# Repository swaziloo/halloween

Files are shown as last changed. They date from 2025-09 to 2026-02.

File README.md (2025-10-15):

# Hallowe'en Projects #

___
## [Animatronic Crow](animatronicCrow/README.md) ##
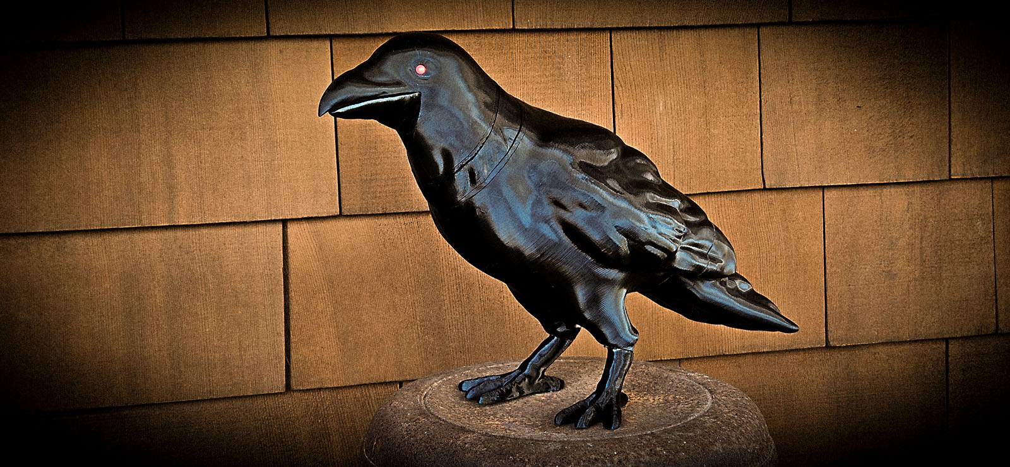
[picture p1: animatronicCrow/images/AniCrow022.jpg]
The Animatronic Crow


A 3D printable crow model that turns its head, blinks LED eyes, moves its beak and squawks when it sees your friends or trick-or-treaters.

___
## [Creature Control PCB](creatureControl/README.md) ##
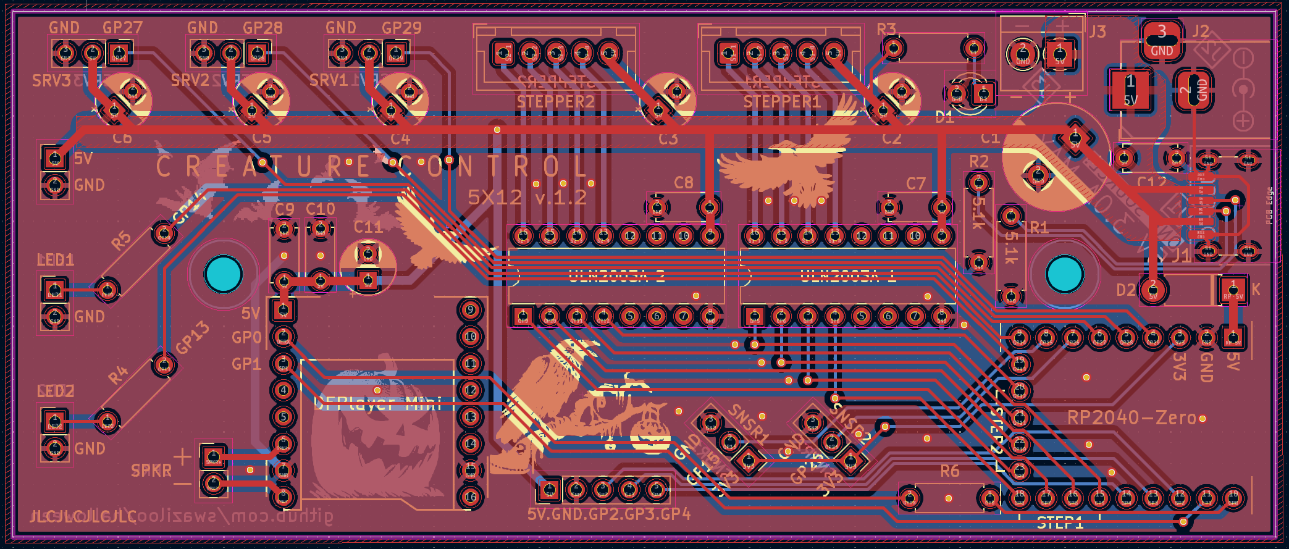
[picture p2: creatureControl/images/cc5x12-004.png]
The Creature Control 5x12 PCB


A PCB to make building animated projects easier to put together.

___
### [Our Hallowe'en Decoration Gallery](https://www.monkeymind.com/halloween) ###

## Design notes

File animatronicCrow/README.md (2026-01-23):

The Animatronic Crow
# Animatronic Crow
Based on  designs from Thingiverse:
[Animatronic Halloween Crow by andymcculloch](https://www.thingiverse.com/thing:6278223)
and [Animatronic Halloween Crow by Doctor_JohnSmith](https://www.thingiverse.com/thing:6258153)
which are themselves remixes from [danman](https://www.thingiverse.com/danman/designs)
who remixed the original model by [YahooJAPAN](https://www.thingiverse.com/yahoojapan/designs).

My work has been done in [KiCad](https://www.kicad.org/),
[FreeCAD](https://www.freecad.org/),
and [Blender](https://www.blender.org/download/releases/4-4/).

I may have extra PCBs available at my cost+shipping. 
Message me if interested.
___
## [Crow Printing Instructions](stl/README.md) ##
Details for printing the models.

## [Crow Build Guide](BUILD.md) ##
How-to guide for building your crow.

### :de: [Crow Guides in German](https://github.com/padpumpkin/animatronicCrow-de) ###
Deutsche Übersetzung der Anleitungen dank padpumpkin.

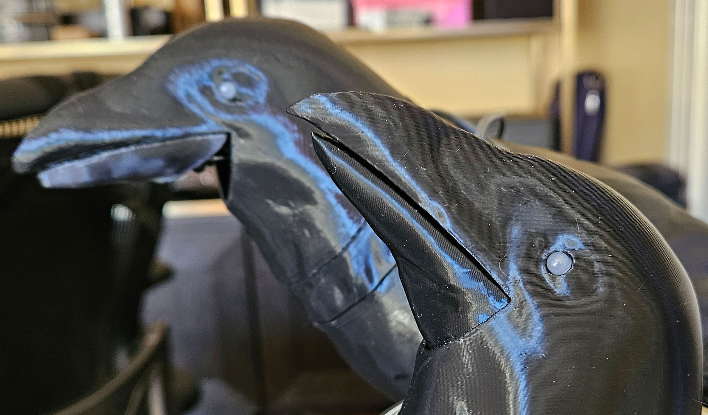
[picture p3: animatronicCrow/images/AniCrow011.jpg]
New beak/head in the foreground.

### Modifications and model sources: ###

| Model | Source | Modifications |
|---|---|---|
| Global | | Standardized on M3 x 4 (or 5) x 5 heat set inserts and M3 fasteners. |
| Head | andymcculloch | Refined beak shape to add more of a point. Smoothed/bevelled lower beak opening. Cut away mounts and rebuilt them slightly wider and short enough to fit below the SG90 servo. |
| Beak | Doctor_Johnsmith | Added a lower collar that fits inside the head without a visible cut-away. Re-drew mounting rail and added separate pin mount holes for actuator. Sliced to enable 3D printing standing up. |
| Beak Servo Mount Plate | andymcculloch | Refined connector tower to accommodate the larger beak when fully open. Straightened out SG-90 mount and shrunk mounting holes to match the screws that come with SG90 servos. Added hexagonal grille for sound. Moved M3 screw holes and shrunk wire pass-thru. |
| Head Stepper Collar | andymcculloch | Moved stepper center. Shrunk cable opening and added alignment pins. Added hexagonal grille for sound with slide path for head pivot pins. Moved M3 screw holes. |
| Body Stepper Mount Plate | Andymcculloch | Moved stepper center. Added arched cutout for alignment pins. Added head pivot pins. Added hexagonal grille for sound. Enlarged head holes to accommodate M3 screws. |
| Body | Doctor_Johnsmith | Cut away servo mount plate and added mounts for andymcculloch stepper mount plate. Added enclosed box for 40mm speaker with flange. Added internal wire management ring. Added access hole behind left leg. Added mount rail for Creature Control 5x12 PCB. Added internal sensor mount. Added PIR window to right knee (optional). Refined 10x3mm magnet mounts. Added mount and M3 hole for securing tail. Added alignment tabs and reversed pins for feet. Filled legs and added drainage routes around/through speaker out out the low point in the right leg. |
| Feet | Doctor_Johnsmith | Reversed pins (socket on feet) and added alignment tabs. Added tie-down horizontal hole through feet. |
| Tail | Doctor_Johnsmith | Refined 10x3mm magnet mounts. Added snap-in tab mount for securing tail to body (optional). Enlarged hole for exterior connection. Made wing tips pointier. |

### Additions: ###

| Model | Description |
|---|---|
| Actuator | Printable arm for connecting hinged beak to servo. Recommend 0.2mm nozzle. |
| Actuator Spacer | Fills the gap between the actuator and the SG90 arm. Recommend a 0.2mm nozzle. |
| PCB Mount | Small rail to mount the Creature Control 5x12 board with M3 hardware to slide inside the body. |
| PIR Mount | Holds a mini PIR sensor and snaps into place inside the right leg. Recommend 0.2mm nozzle. |
| PIR Small Fresnel | PIR window plug and cap are a glue-in holder for a minimal/black fresnel lens to hide the mini-PIR sensor. | 
| PIR Window Plug | Fills a PIR hole in the right knee if you change your mind. Print vertically to match the crow outer pattern. |
| PIR Window Template | A printable oval that matches the hole shape for the PIR window. The intention was to use black IR transmissive acrylic to cover the sensor, but it's too dark for effective sensing. YMMV. |
| LD1020 Mount | Holds an LD1020 radar sensor and snaps into place inside the right leg. Recommend a 0.2mm nozzle. |

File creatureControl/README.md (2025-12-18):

The Creature Control 5x12 PCB
# Creature Control PCB #
When hand soldering a board to enable the animatronic crow I realized that I wanted a half-dozen crows and maybe some talking skulls and hand soldering wasn't my favorite way to spend my time.
Hence Creature Control 5x12. Designed to enable a bunch of capability using an inexpensive and easy to program Raspberry Pi 2040 in the tiny Waveshare Zero format.

*I likely have extra PCBs&mdash;contact me directly if interested in PCB(s) at cost.*

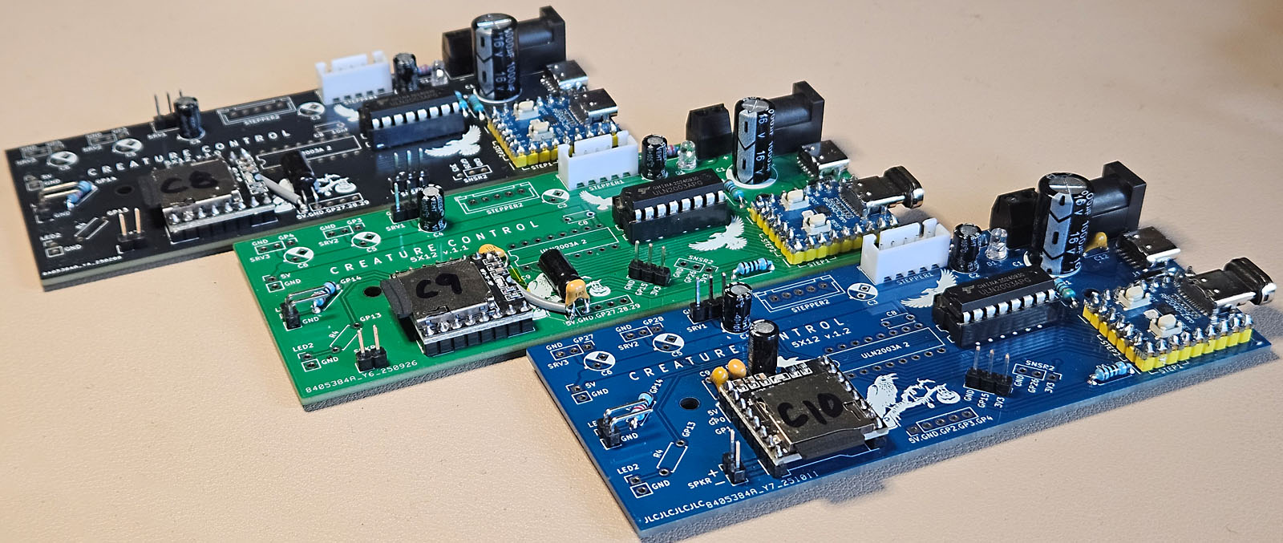
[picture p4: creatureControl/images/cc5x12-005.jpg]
Versions 1.0-1.2 of the CC5x12 PCB

## 5x12 v1.0 ##
Provides a 5-volt 3-amp power rail to supply 3 servos and 2 steppers controlled by a RP2040-Zero which is also wired to incorporate 2 LEDs, 2 motion sensors, the DFPlayer Mini mp3 player and a pin header for the remaining pins.
Designed to be hand-soldered and easily programmable using Arduino libraries.
### v1.1 2025-09 ###
Larger PTH (0.9mm) for MCU and mp3 player mounts, 
add 1KΩ serial resistor for DFPlayer RX (MCU GP0) connection, 
add capacitor (104) for DFPlayer 3V3, 
remove incorrect silk for C7 and C8 value,
rotate sensor mounts for better routing,
update schema.
### v1.2 2025-10 ###
Move DFPlayer Mini to 5V supply and add additional bulk/filtering capacitors (1µF, 220µF),
add filtering capacitor (0.1µF) at 5V power supply,
move servos 1-3 to GP27-GP29,
move GP2-GP4 to expansion header,
rotate DFPlayer Mini,
(re)arrange silks,
update schema.

*Gerber files have been produced for JLCPCB but may work elsewhere.*

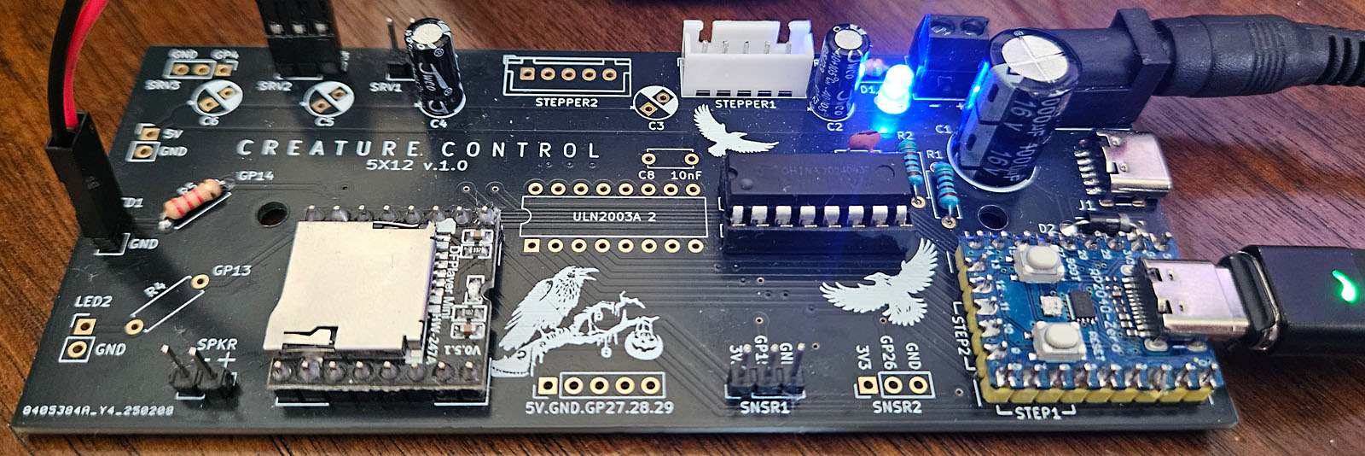
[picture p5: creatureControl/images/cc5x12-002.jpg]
Animatronic Crow build on CC5x12

### VITAL IMPORTANT SAFETY NOTICE! ###
*The 5 volt power rail allows for multiple source connections but only one should be used at any given time.* 
*Do not connect more than one 5 volt source to the power rail!*
(Unless you really know what you're doing.)
It is safe to connect the power to the 5v rail and the RP2040-Zero to your PC at the same time&mdash;in fact it's necessary for testing.
### Parts List ###
The intent is that one would install only the components needed for a project.

| Qty | Ref | Part | Note |
|---|---|---|---|
| 1 | | RP2040-Zero | Waveshare or equivalent. |
| 1 | D2 | 1N5819 Schottky Diode | For RP2040-Zero VCC. |
| 1 | | DFPlayer Mini | DFRobot or equivalent. |
| 3-4 | C7-C9, C12 | 100nF 50v Ceramic Capacitor (104) | (v1.1+) for DFPlayer Mini 5V, (v1.2) input 5V, ULN2003A. |
| 1 | C10 | 1µF 50v Ceramic Capacitor (105) | (v1.2) For DFPlayer Mini midrange filter. |
| 1 | C11 | 220µF 10-16v Electrolytic Capacitor | (v1.2) For DFPlayer Mini . |
| 1 | R6 | 1KΩ Resistor | (v1.1+) for MCU GP0->DFPlayer Mini RX |
| 1-2 | | ULN2003A | Stepper driver. |
| 1-2 (optional) | | IC DIP Socket 16-Pin | For ULN2003A. Or just solder directly to the board. |
| 1-2 | | XH2.54mm 5-Pin Connector | Straight pin for stepper. |
| 1 (optional) | D1 | 3mm LED | For power rail indicator. |
| 1 (optional) | R3 | Resistor for power indicator LED | I used 2.2kΩ for a blue 3mm LED. |
| 1-2 | R4,R5 | Resistor for external LEDs | Based on LED(s) to be used. |
| 1-5 | C2-C6 | 100µF 10-16v Electrolytic Capacitor | One for each 5v servo and stepper. |
| 1 | C1 | 1000µF 10-16v Electrolytic Capacitor | For 5v rail. |
| 1 (optional) | J2 | 5.5x2.1MM DC-005 Power Jack | If using a 5v/3A adapter. |
| 1 (optional) | J1 | USB-C 6-pin Surface Mount | If using a USB battery. |
| 2 (optional) | R1,R2 | 5.1kΩ Resistors | If using a USB battery. |
| 1 (optional) | J3 | KF350-2P 3.5mm Pitch 2Pin PCB Screw Terminal Block Connector | If using a wired 5v source or drain. Also useful if needing to share ground with an external power rail. |
| optional | | 2.54mm Pin Headers | For board connections. |

## Building the CC5x12 ##

* You do not need to fill the board. It is perfectly acceptable to install only the connections and components you intend to use.
* If you are installing the USB-C socket, do that first and test the electrical connections. Every other component is easier to hand solder.
* The RP2040-Zero can be powered by its USB-C connection or the board 5v power, but it will not provide power to the steppers, servos, or DFPlayer (since v1.2). LEDs and sensors draw power from the RP2040-Zero 3V3.
* The C1 capacitor is intended to smooth out the 5v supply for the board. C2-C6 & C11 provide demand power for their nearby stepper, servo, or DFPlayer Mini. Only install these caps for the components you intend to connect.
___

## Testing ##
Install the Arduino IDE and the following libraries:
[AccelStepper](https://www.airspayce.com/mikem/arduino/AccelStepper),
[DFRobotDFPlayerMini](https://github.com/DFRobot/DFRobotDFPlayerMini),
[arduino-pico](https://github.com/earlephilhower/arduino-pico) by Earle Philhower,
[Adafruit NeoPixel](https://github.com/adafruit/Adafruit_NeoPixel).
Install using the library manager in the Arduino IDE.

* Enable the *Waveshare RP2040-Zero* board in the board manager.
* Connect power to one of the 5v inputs and the RP2040-Zero to your pc. 
* Select the connected device/port and ensure the Waveshare RP2040-Zero board is assigned.
* Open the [BoardTest](BoardTest) sketch with the Arduino IDE.
* Set 'true' for available components at the top of the sketch. 
* Select the 'Upload' button.
* The sketch should compile, the board should initialize, and a test loop should run.

The steppers, servos, and MP3 components will cycle.
The LED(s) will reflect the sensor(s) states.

___
## Notes and Issues: ##

### Volume Issues v1.0 and v1.1 ###
The DFPlayer Mini is being powered off the RP2040-Zero 3V3 on these boards which doesn't provide enough power to handle max draw at high volume.
The fix for these boards is to pull the VCC pin from the header and wire to a nearby 5V connection.
Add a 220µF electrolytic and a 1µF (105) ceramic at the power tap and pull a twisted pair of 5V/GND to the DFPlayer, connecting a 0.1µF (104) between ground and VCC at the connection point.
The easier fix is to lower the volume to one that the MCU will support. 
Around 22-25/30.
TX/RX are already shifted to 3.3V for compatibility with MCU communication.

### Connecting to a 12v Rail ###
You should be able to control 12v steppers and servos using the CC5X12 by eliminating the 5v connection to them and providing separate power. 
If you do this, you will want to pull a shared ground over from the block connector or another board source.
*I have not tested this functionality.*

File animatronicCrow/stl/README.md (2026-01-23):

# 3D Printing #
:de: [Crow Guides in German](https://github.com/padpumpkin/animatronicCrow-de)

Print in the orientation shown in the images below. 
Consider PETG for a more weather resistant material, but note that the model is not fully weatherproof.

## Note: ##
The crow body is designed to be printed with minimal supports (only for the "ankles").
If your slicer wants to generate an enormous support to catch the tiny top of the PCB mount you should mark it "do not support" and save some filament.

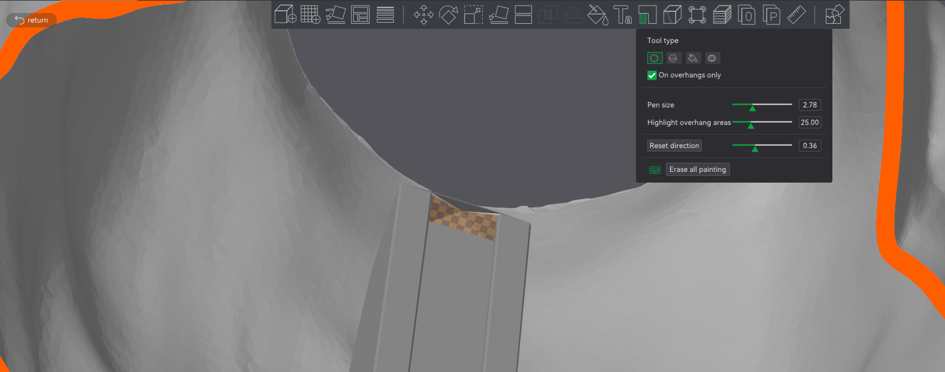
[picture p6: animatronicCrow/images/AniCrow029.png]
No need for printed support here


On a related note, I do prefer to support the sloping underside of the beak. 
The [.3mf](https://makerworld.com/en/models/1869791-animatronic-halloween-crow) includes these settings.

## Second Note: ##
The stepper collar slides against the stepper plate.
I print the collar with ironing on to help smooth the surface.
After printing, I sand both the dome mounts on the body plate and the sliding surface on the collar to 800 grit.
Add dry lube to both before assembly.

# Printing #
I find that PETG printed with a 0.4mm nozzle and 0.16mm layer height provides a strong build and a shiny appearance like bird feathers at the expense of a long print.

| | |
|---|---|
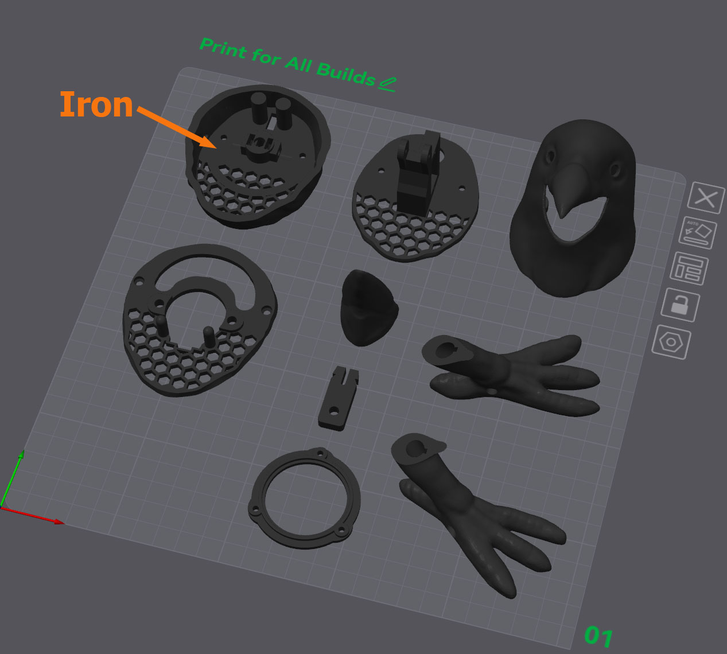
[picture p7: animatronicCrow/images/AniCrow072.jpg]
PIR Crow STL Files for 3D printing
|  | Print all parts on the first plate for all builds. Turn on ironing for the top of the collar. Consider the seam on the lower portion of the head (I like to align it right down the middle). The speaker ring and tail screw tab are optional, though I recommend both. |
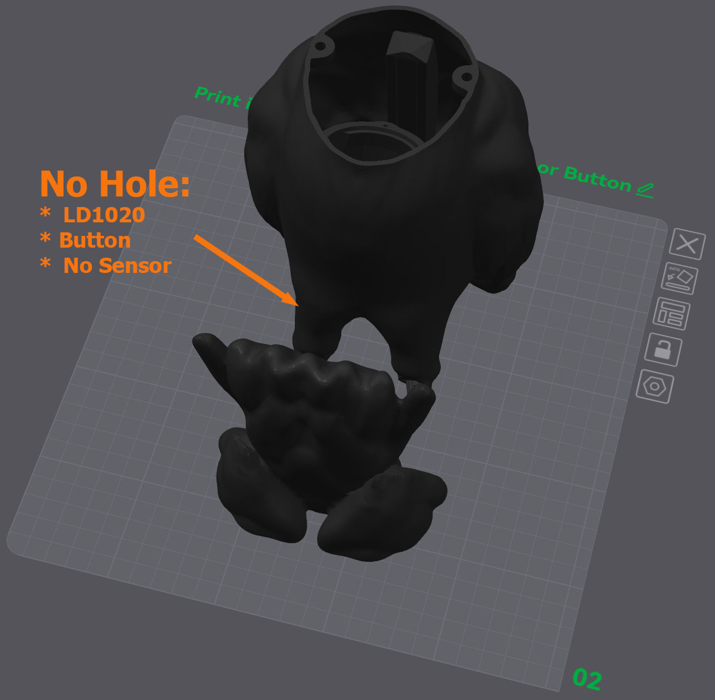
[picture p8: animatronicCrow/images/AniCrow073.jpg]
PIR Crow STL Files for 3D printing
|  | The crow body with no hole is used for non-PIR builds. |
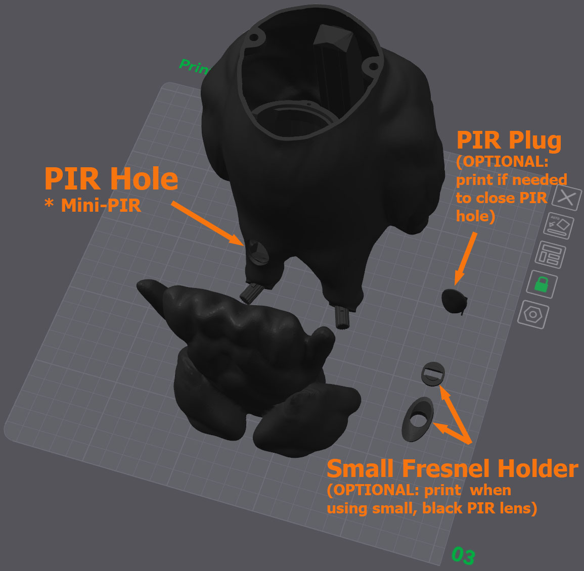
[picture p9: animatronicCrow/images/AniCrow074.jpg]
PIR Crow STL Files for 3D printing
|  | The body with the PIR hole can be used for a regular, white-lens Mini-PIR or with a replacement small black lens. You need the Small Fresnel Holder *or* the Mini-PIR Holder&mdash;not both. The PIR Plug can be used to close the PIR Hole if you decide to use another/no sensor. |
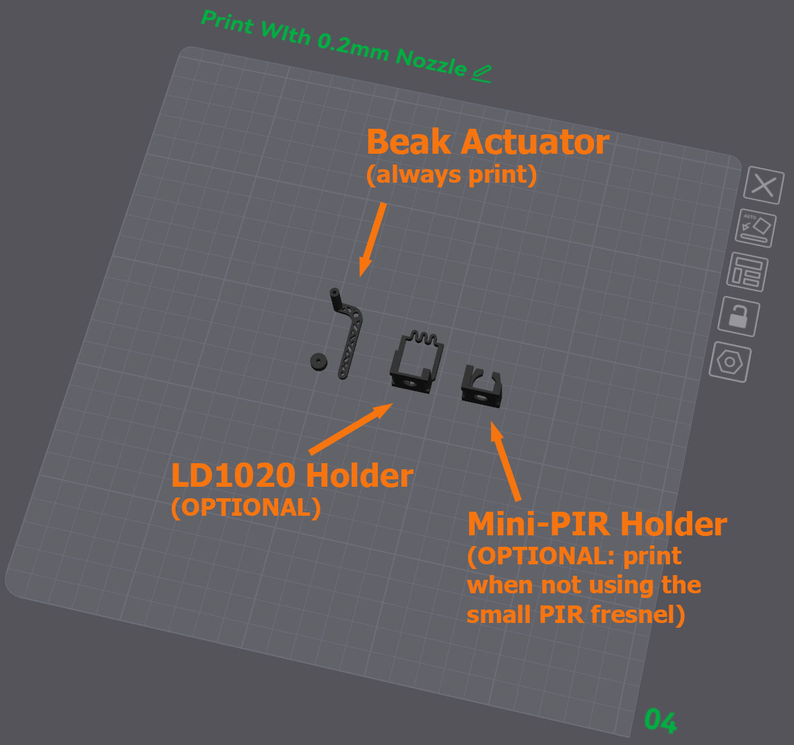
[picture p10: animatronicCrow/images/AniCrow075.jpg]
PIR Crow STL Files for 3D printing
|  | The actuator, spacer, and sensor holders are best printed with a 0.2mm nozzle and a "strength" setting (I prefer 0.10mm layer height). |

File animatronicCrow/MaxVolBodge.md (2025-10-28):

### Bodge for Max Volume PCB 1.0 & 1.1 ###
(You don't need to do any of this on v1.2+ boards)

:de: [Crow Guides in German](https://github.com/padpumpkin/animatronicCrow-de)

| Step | Simple Bodge v1.0 or v1.1 | This is my go-to for both v1.0 and v1.1 since I don't hear any noise or buzzing through the tiny 3-watt speaker without the ceramic caps. |
|---|---|---|
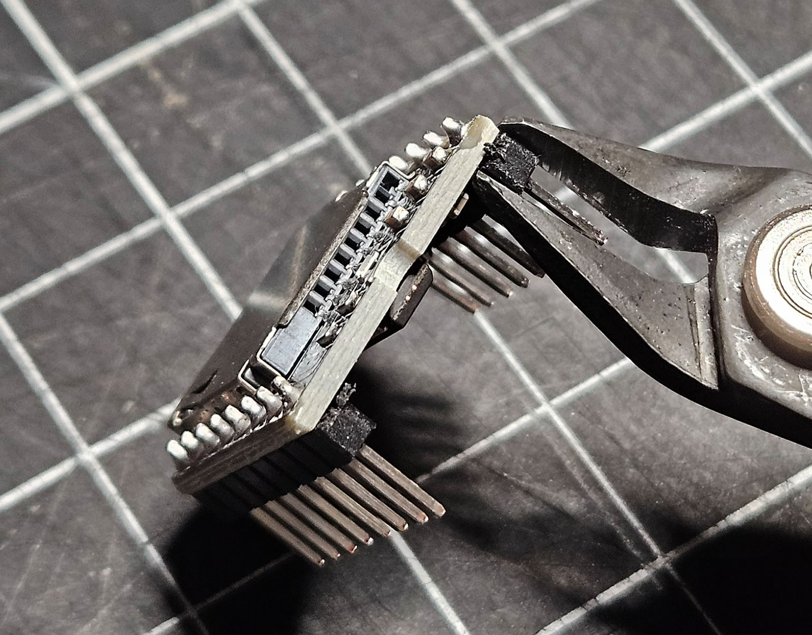
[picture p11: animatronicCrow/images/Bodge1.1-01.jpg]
| 1 |   | Carefully clip the plastic above the VCC pin on the DFPlayer Mini. |
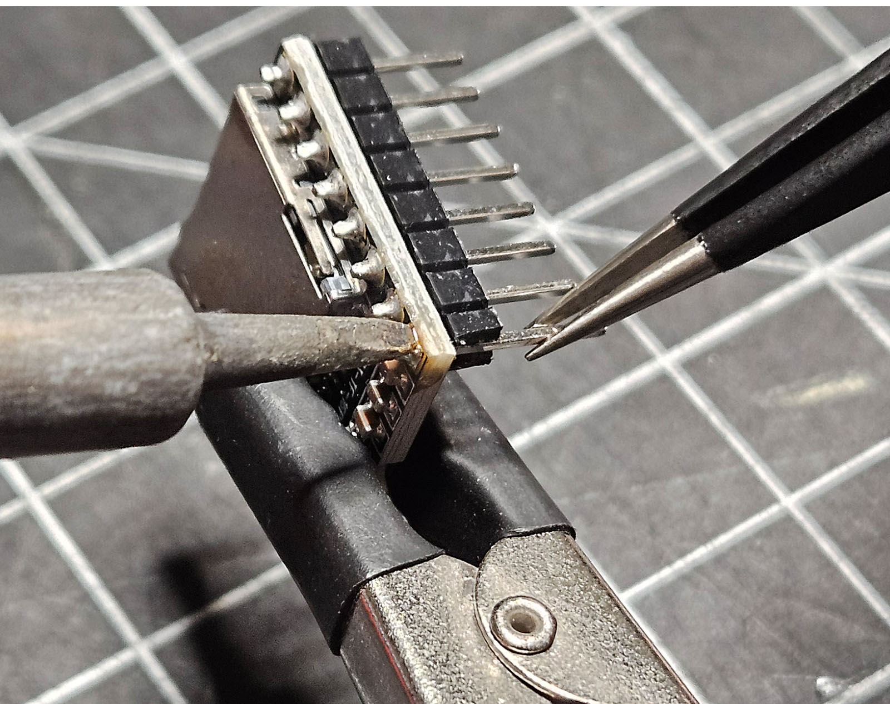
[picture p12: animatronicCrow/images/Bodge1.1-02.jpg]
| 2 |   | Any soldering on the DFPlayer Mini runs a risk of disrupting the tiny SMD caps and resistors. Keep away from them and heat the pin until you can pull it out of the board and header. Clip away the rest of the plastic below VCC. |
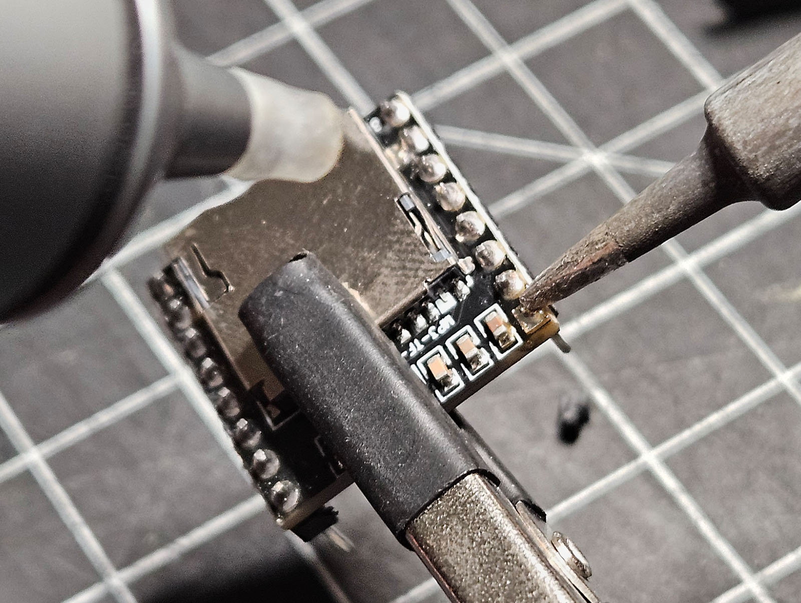
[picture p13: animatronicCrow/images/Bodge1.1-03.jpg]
| 3 |   | Clean up the through hole with a solder sucker (or tape, but...risky). |
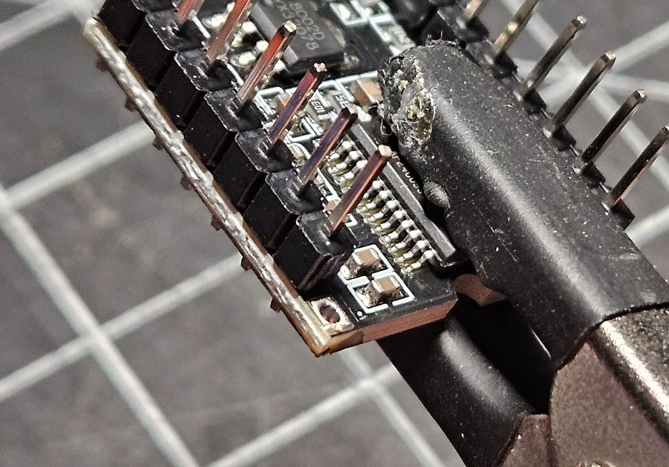
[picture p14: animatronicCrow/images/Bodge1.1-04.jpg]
| 4 |   | When you're done, ensure you didn't move or detatch any SMD components on the top or bottom of the board. The through hole should be clear. |
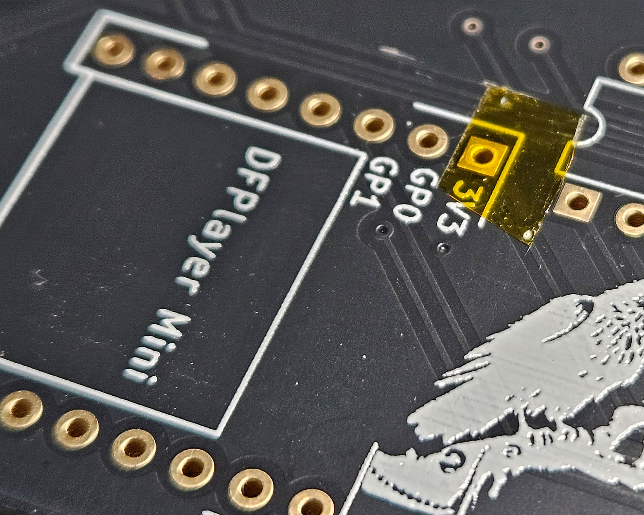
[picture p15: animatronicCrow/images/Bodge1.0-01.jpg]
| 5 |   | Cover the 3V3 through-hole pad with a bit of Kapton or electrical tape. |
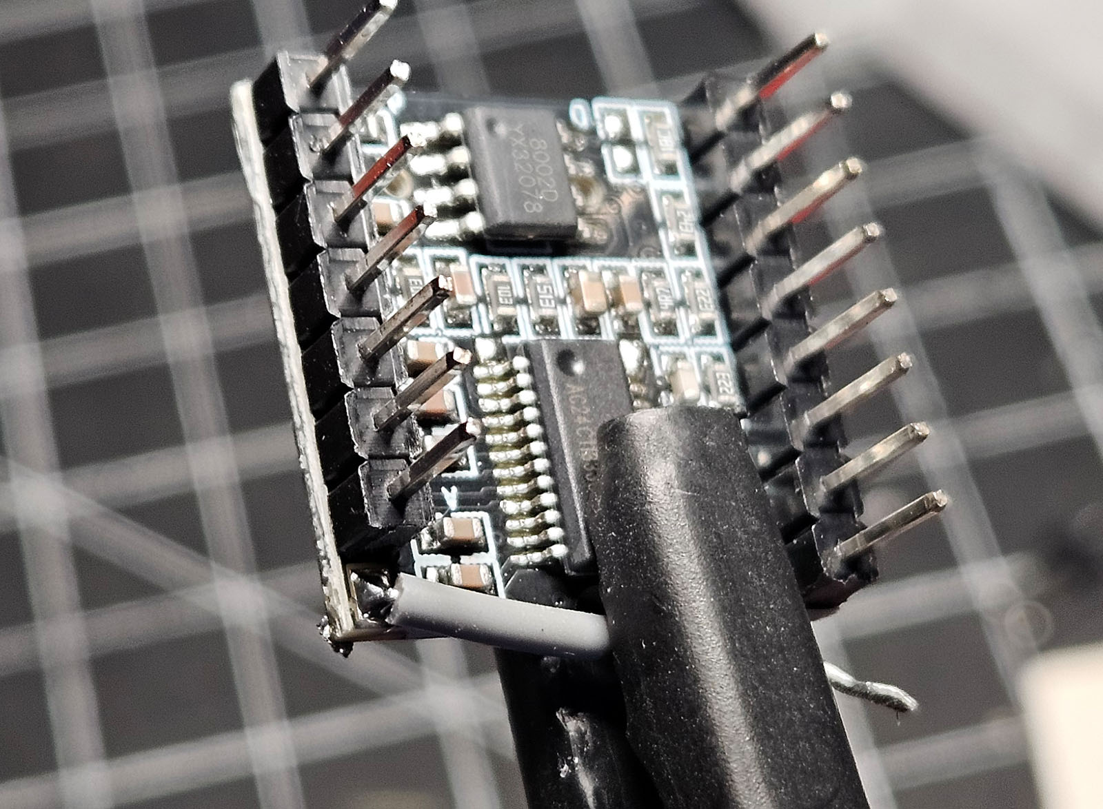
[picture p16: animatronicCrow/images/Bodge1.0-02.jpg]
| 6 |   | Strip the ends off a ~25mm length of high-temperature wire. Twist and solder one end through the DFPlayer Mini from below. Solder the DFPlayer Mini to the CC5x12 board. |
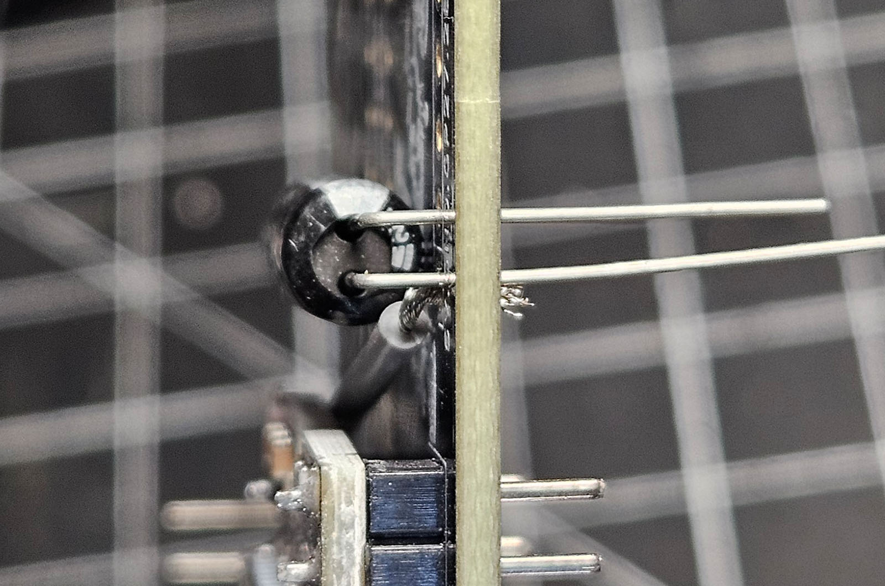
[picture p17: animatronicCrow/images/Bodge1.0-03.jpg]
| 7 |   | Bend the other end of the wire through the 5V expansion header hole. Fit a 220uF electrolytic capacitor through the same 5V and adjacent GND holes. Solder in place. |
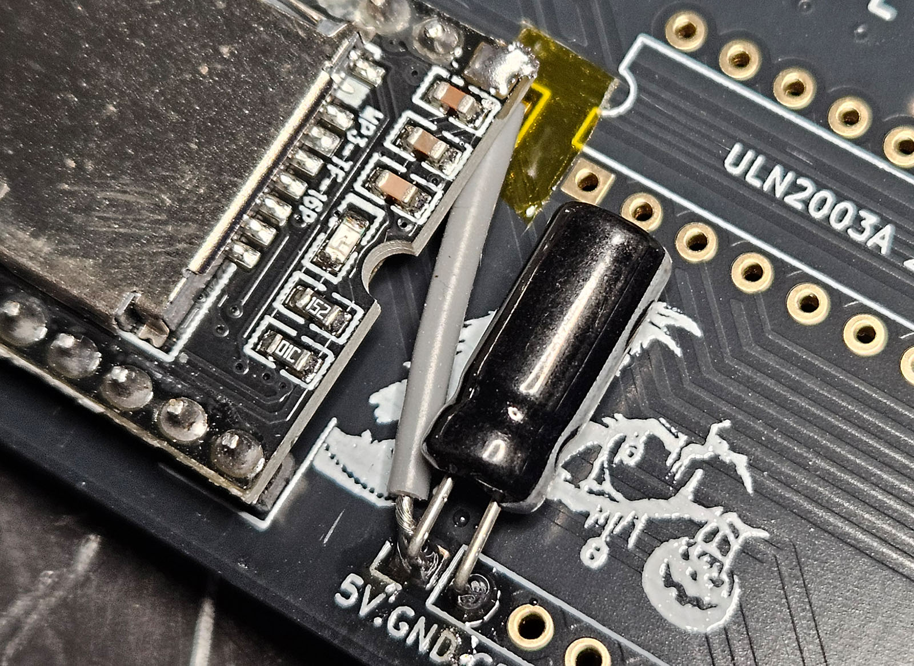
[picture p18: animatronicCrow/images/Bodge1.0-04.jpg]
| 8 |   | The completed bodge will support max volume (30) from the internal 3W amplifier of the DFPlayer Mini. |

| Step | Bodge v1.1 with Ceramic Caps | Ceramic capacitors will reduce board noise. |
|---|---|---|
| 1-4  | Same as above. | |
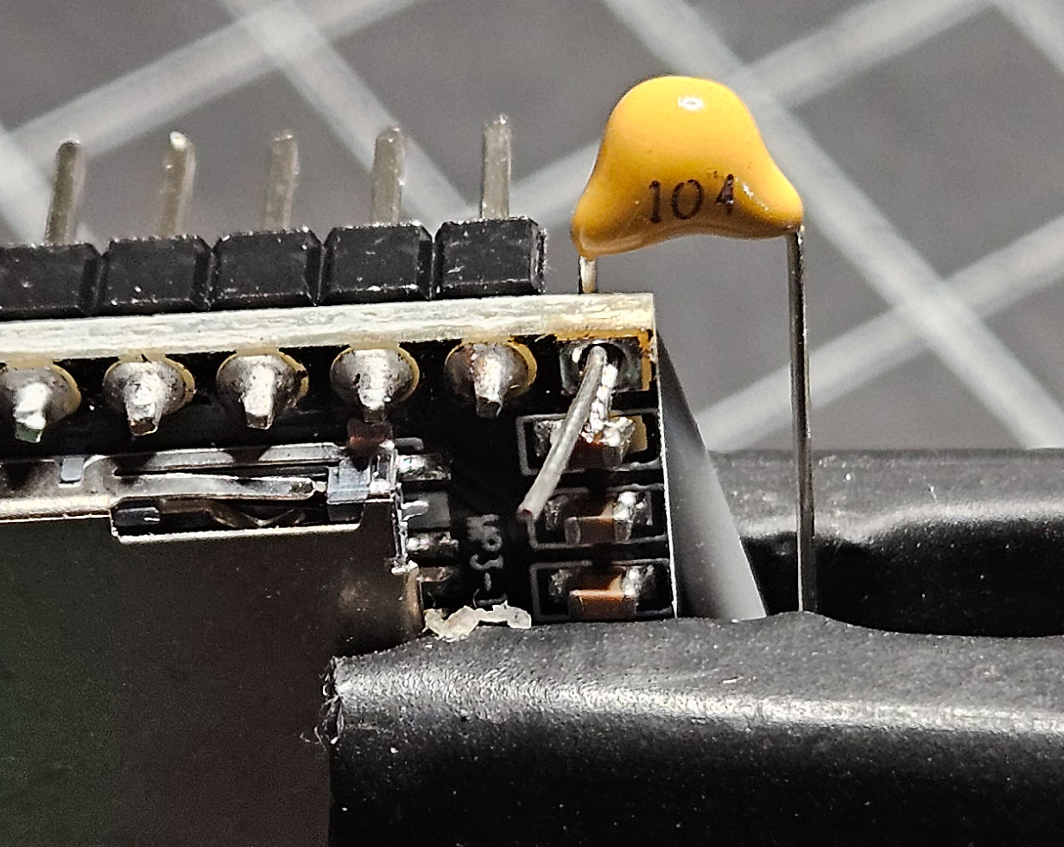
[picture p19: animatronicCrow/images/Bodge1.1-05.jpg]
| 5 |   | Fit a short piece of high temp wire and one leg from your 104 resistor from the bottom and solder those in place. |
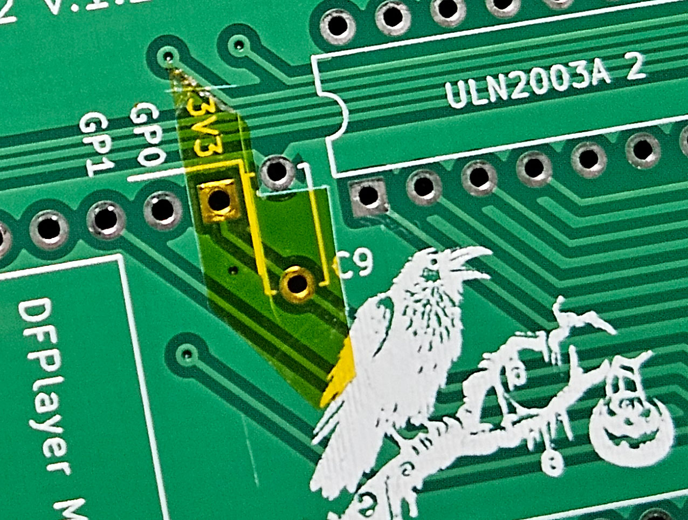
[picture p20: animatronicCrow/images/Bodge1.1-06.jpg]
| 6 |   | Add some Kapton (or electrical) tape to cover the 3v3 through hole pads. |
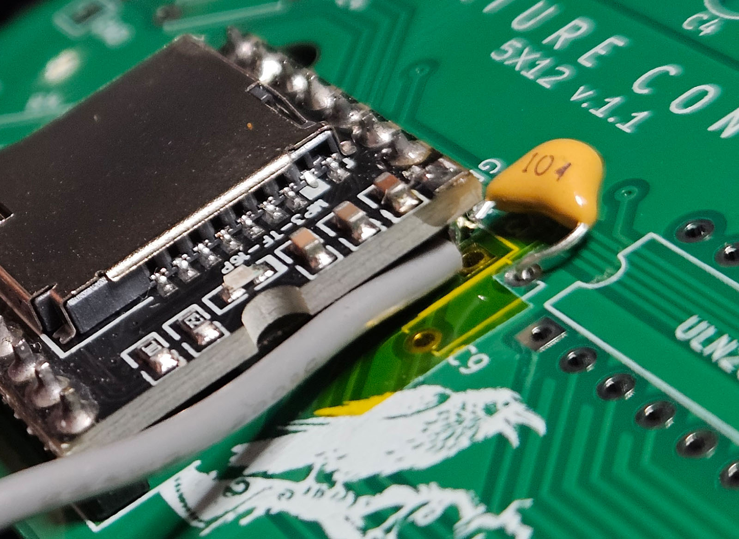
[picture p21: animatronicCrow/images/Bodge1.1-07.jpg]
| 7 |   | Mount the DFPlayer mini carefully fitting the other leg of the 104 cap into the ground. Solder both. |
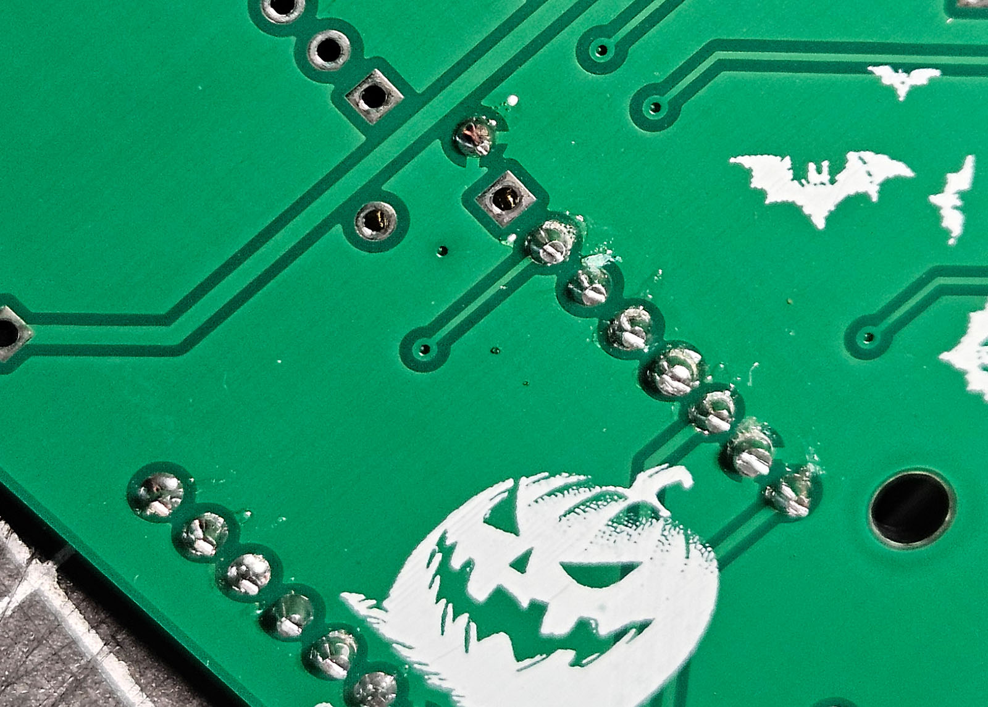
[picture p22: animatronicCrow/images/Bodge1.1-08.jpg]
| 8 |   | After soldering and clipping the legs you should have nothing in either 3v3 through holes. |
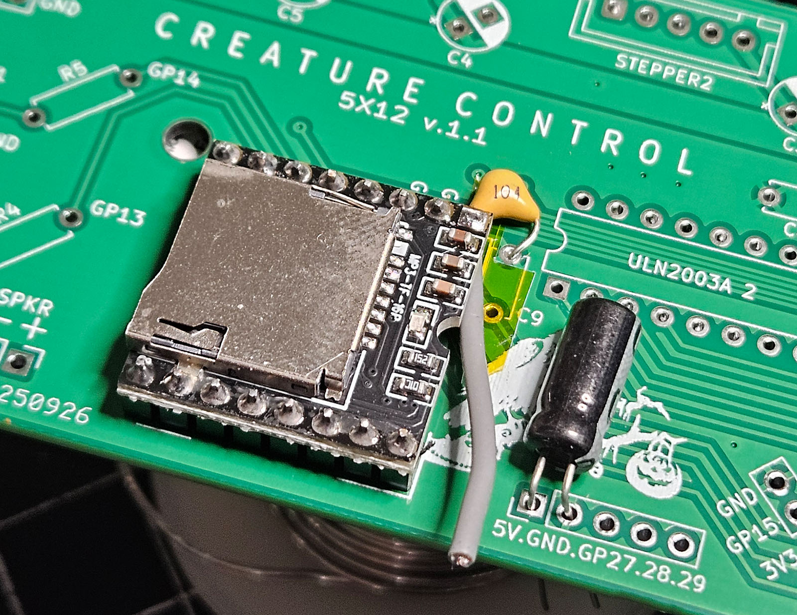
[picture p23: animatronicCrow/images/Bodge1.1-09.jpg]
| 9 |   | Bend the legs of a 220uF electrolytic and fit them into the 5V and GND holes of the nearby expansion header. |
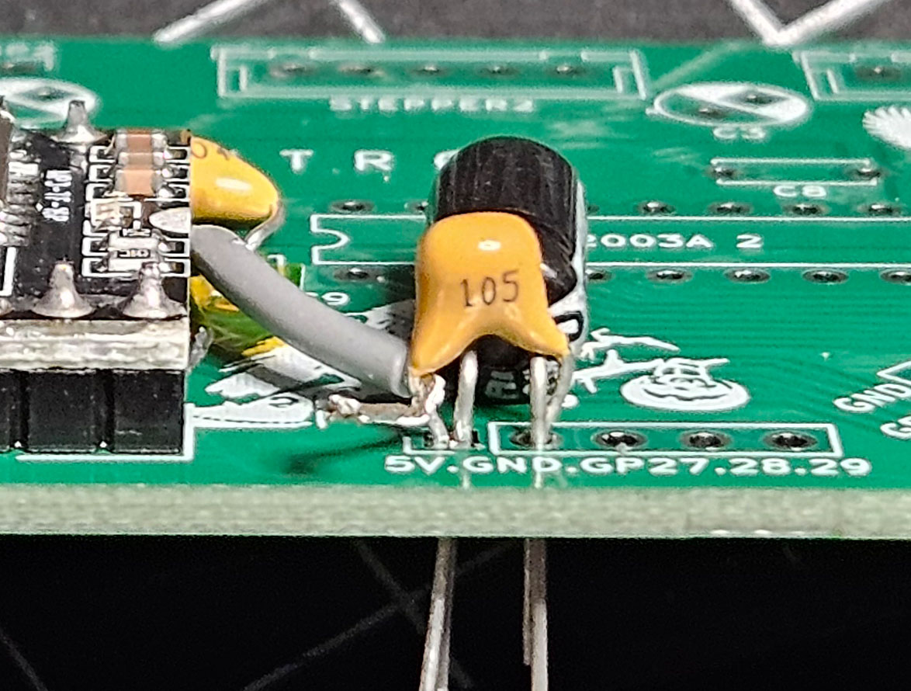
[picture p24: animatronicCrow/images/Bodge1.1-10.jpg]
| 10 |   | Strip the VCC wire and squeeze a 105 cap into the hole with the electrolytic in contact with the VCC wire. Solder them all into place. |
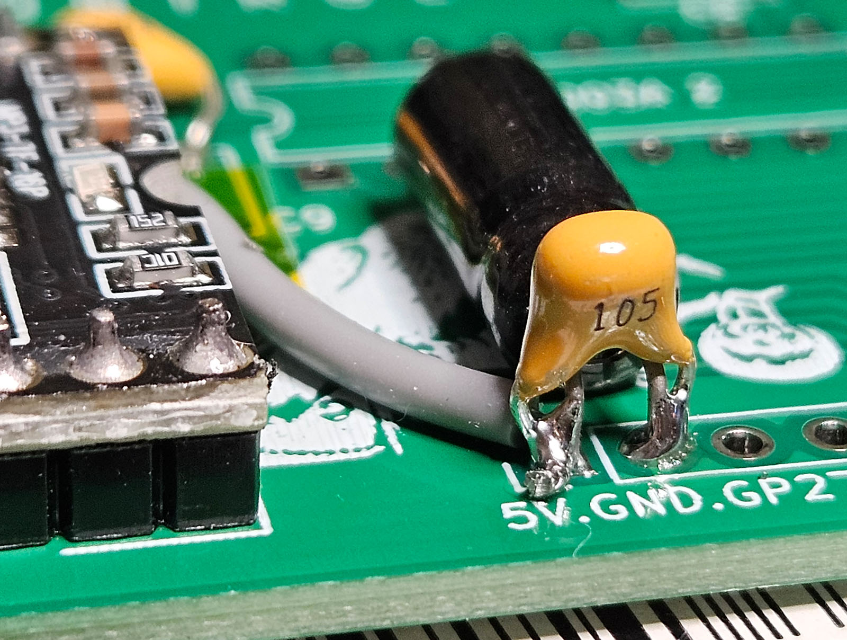
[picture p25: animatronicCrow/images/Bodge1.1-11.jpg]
| 11 |   | Completed bodge at the 5V supply. |
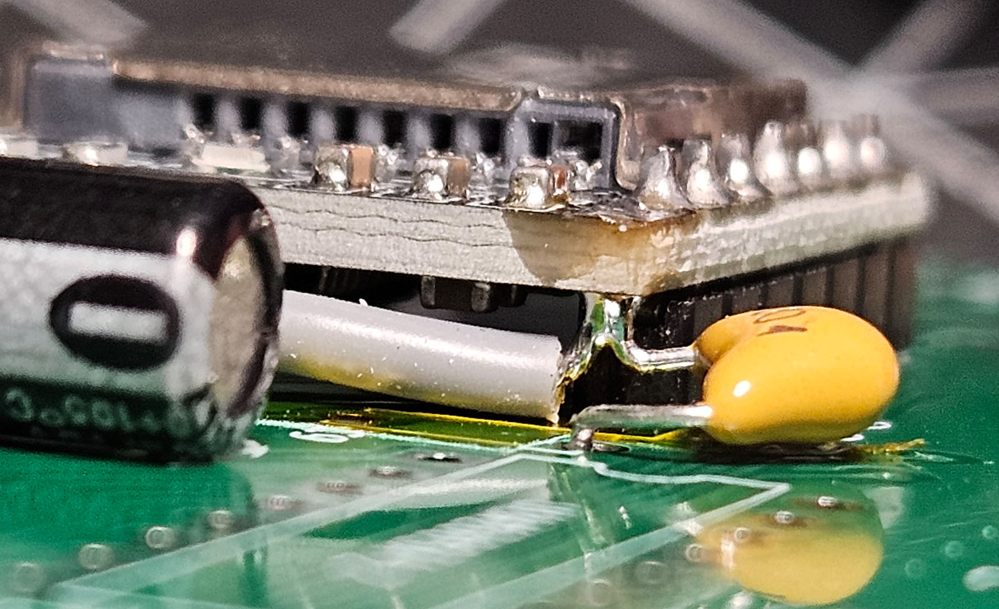
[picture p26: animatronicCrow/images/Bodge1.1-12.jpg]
| 12 |   | Completed bodge at the DFPlayer Mini. |

Test your connections!

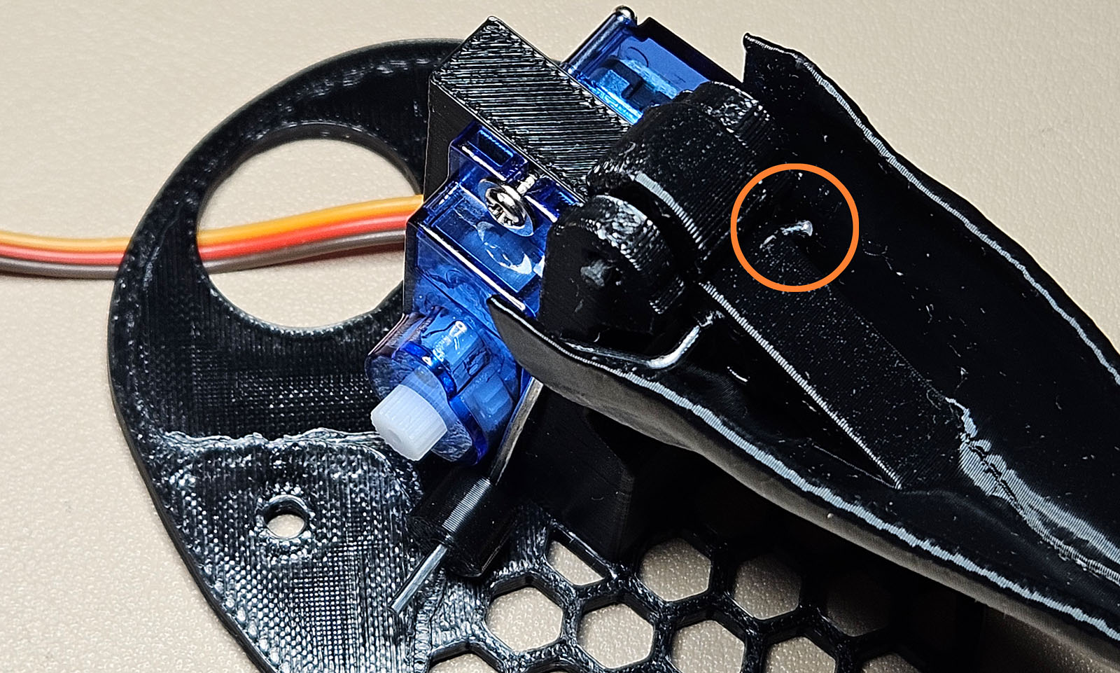
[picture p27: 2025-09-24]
animatronicCrow/images/AniCrow010.jpg

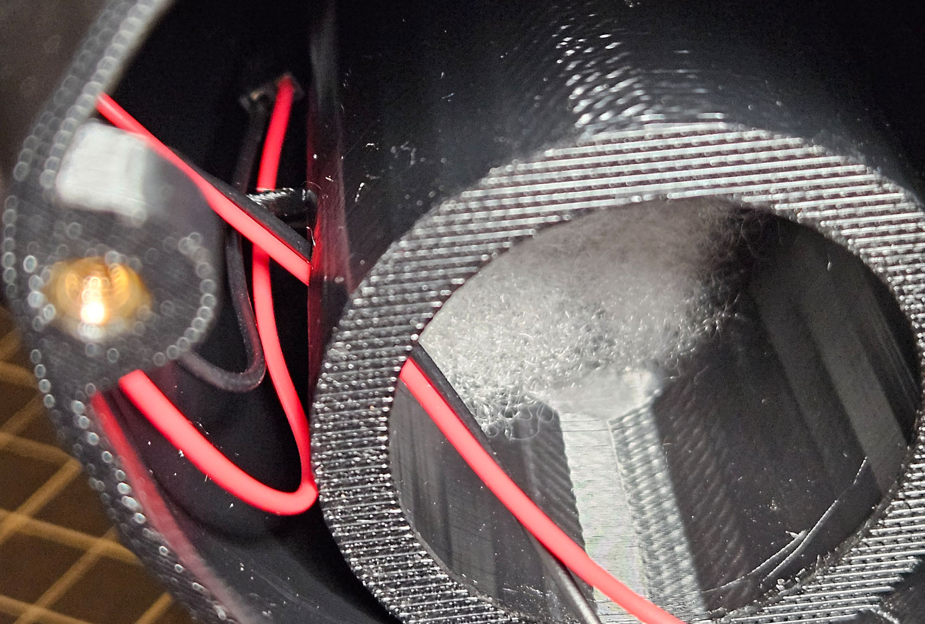
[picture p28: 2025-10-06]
animatronicCrow/images/AniCrow036.jpg

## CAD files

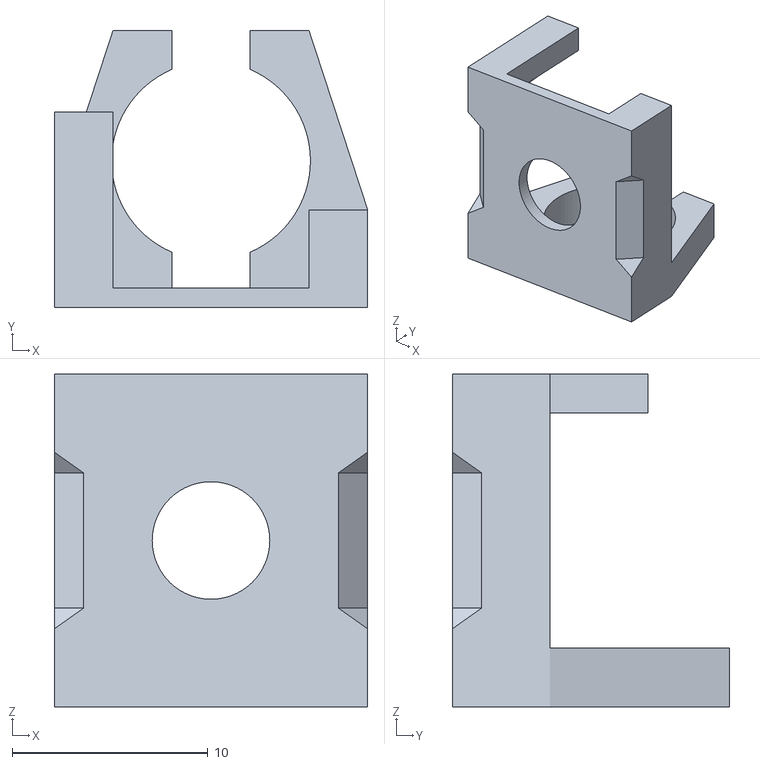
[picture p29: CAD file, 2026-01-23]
animatronicCrow/stl/BodyPIRMount.stl
16.0 x 14.2 x 17.0

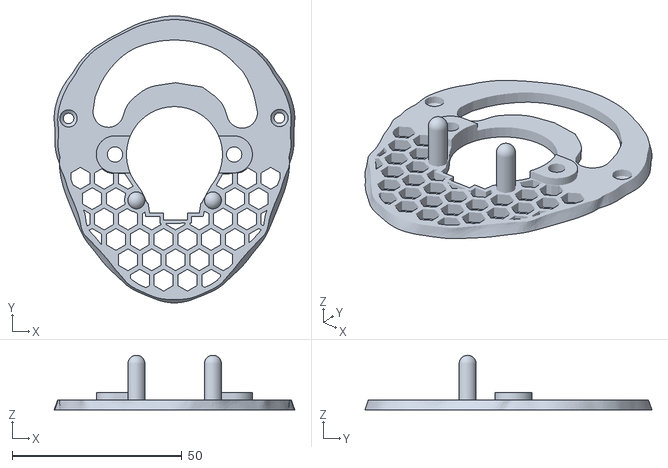
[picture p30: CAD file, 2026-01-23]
animatronicCrow/stl/BodyStepperPlate.stl
70.8 x 84.5 x 16.0

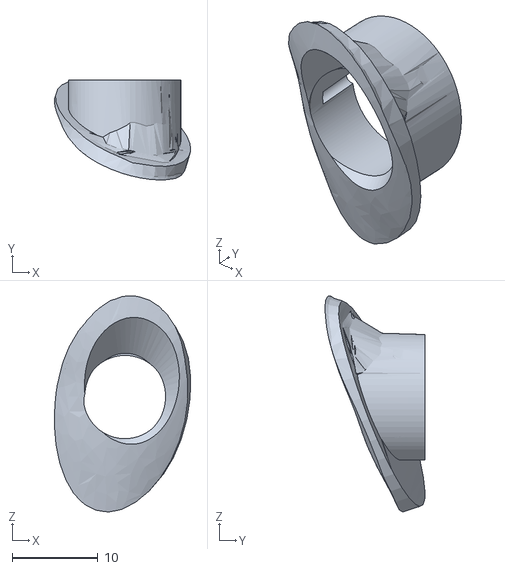
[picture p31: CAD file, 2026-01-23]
animatronicCrow/stl/BodyPIRPlugSmallFresnel.stl
15.9 x 11.7 x 25.2

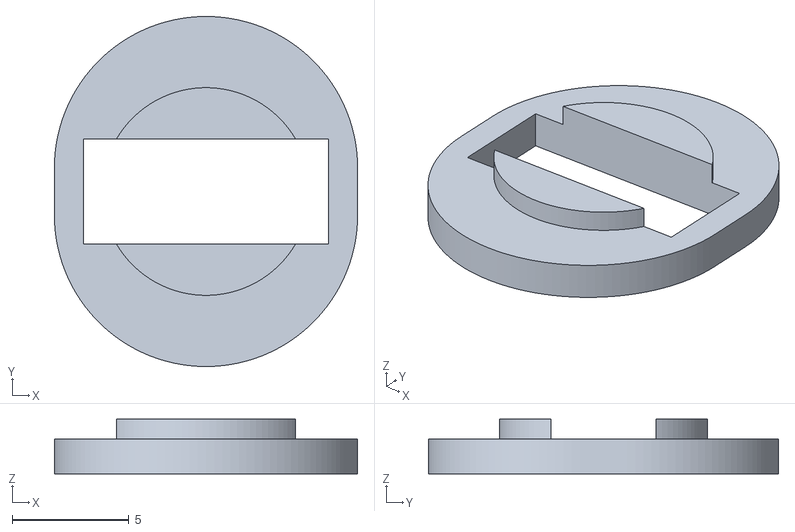
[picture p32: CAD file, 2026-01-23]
animatronicCrow/stl/BodyPIRPlugSmallFresnelCap.stl
13.0 x 15.0 x 2.35

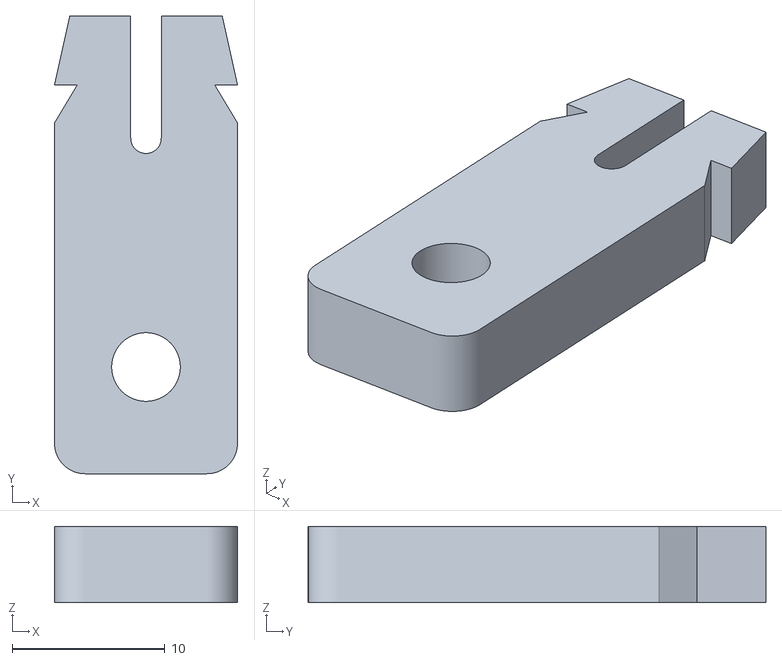
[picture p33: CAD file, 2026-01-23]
animatronicCrow/stl/TailAttachmentTab.stl
12.0 x 30.0 x 5.00

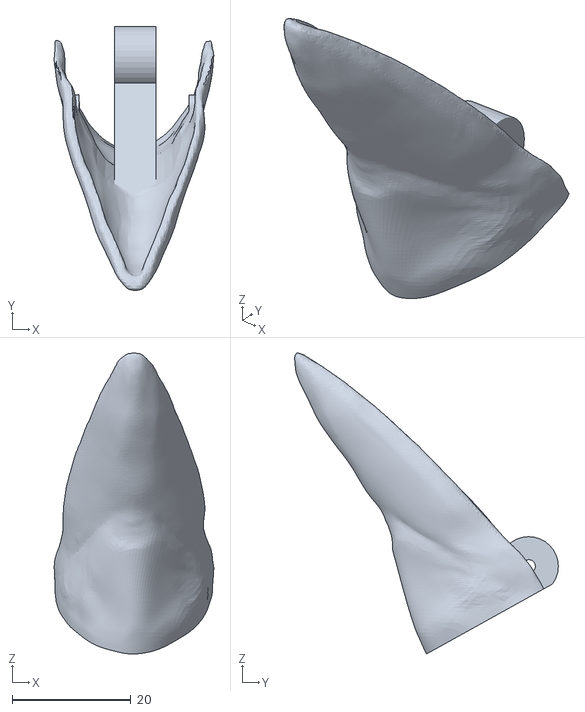
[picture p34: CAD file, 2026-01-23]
animatronicCrow/stl/Beak.stl
26.9 x 44.4 x 50.7

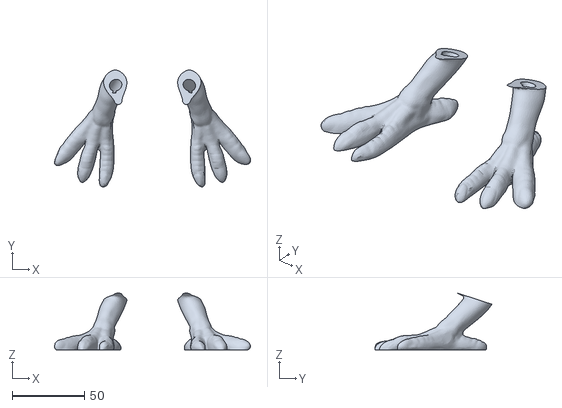
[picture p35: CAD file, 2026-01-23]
animatronicCrow/stl/FeetWithoutHole.stl
135.7 x 80.9 x 39.3

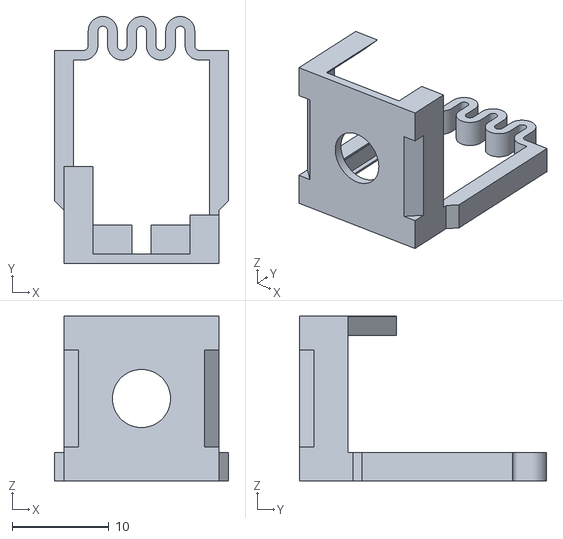
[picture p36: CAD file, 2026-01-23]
animatronicCrow/stl/BodyRadarMount.stl
18.0 x 25.5 x 17.0

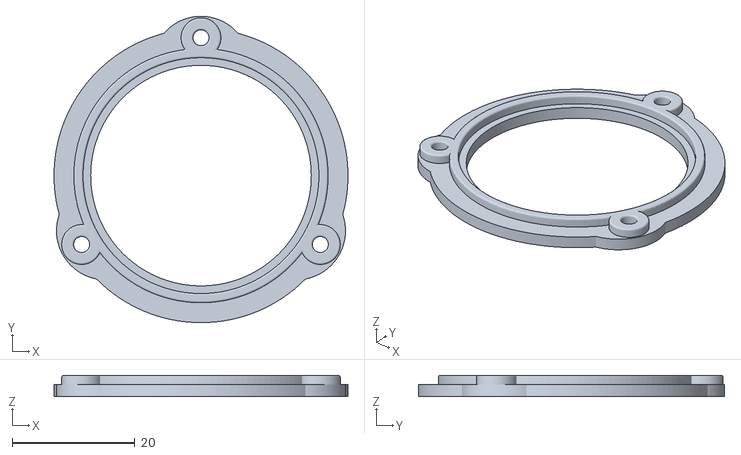
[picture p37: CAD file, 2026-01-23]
animatronicCrow/stl/BodySpeakerFlange.stl
48.0 x 50.0 x 3.50

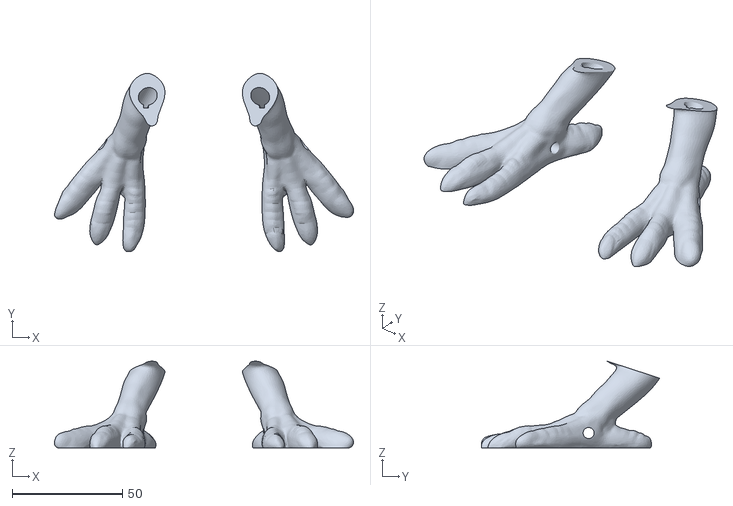
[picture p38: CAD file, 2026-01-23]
animatronicCrow/stl/Feet.stl
135.7 x 80.9 x 39.3

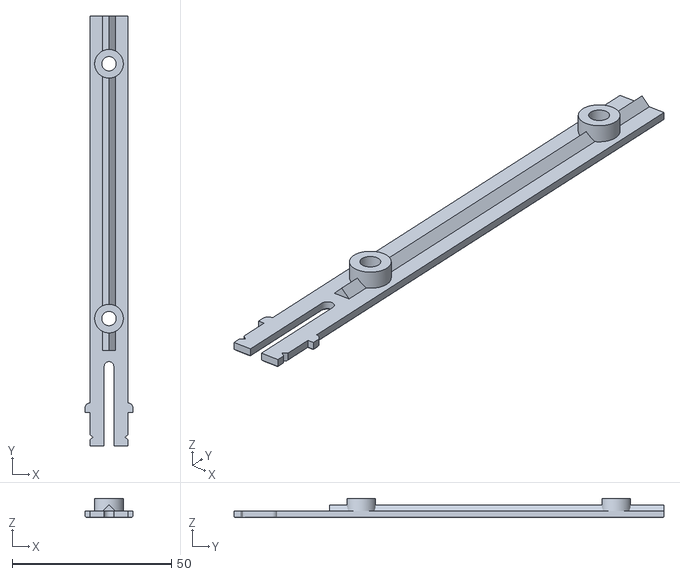
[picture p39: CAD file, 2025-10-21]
animatronicCrow/stl/BodyPCBMount.stl
15.0 x 135.0 x 6.00

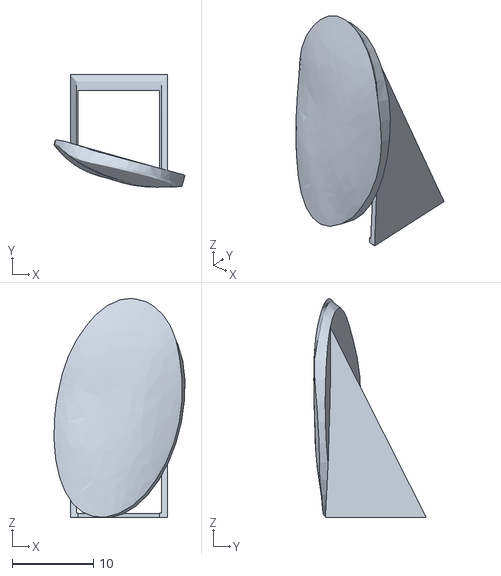
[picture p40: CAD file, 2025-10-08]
animatronicCrow/stl/BodyPIRPlug.stl
16.1 x 13.8 x 26.9

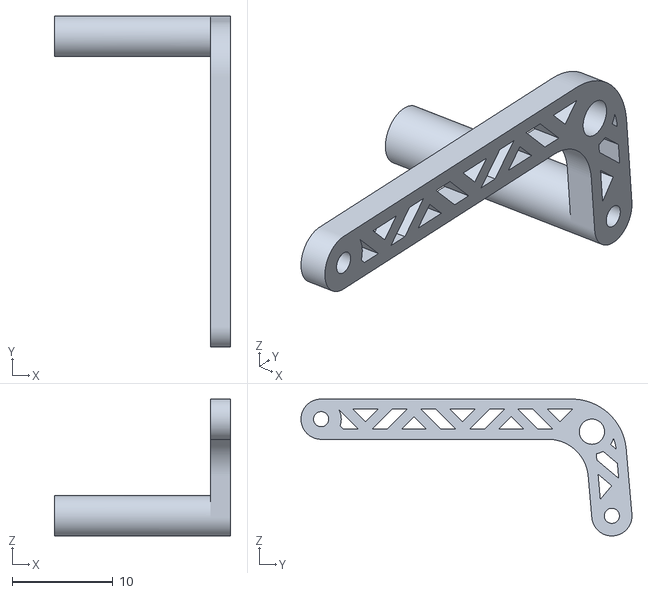
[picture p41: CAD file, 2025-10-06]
animatronicCrow/stl/Actuator.stl
17.5 x 32.9 x 13.6

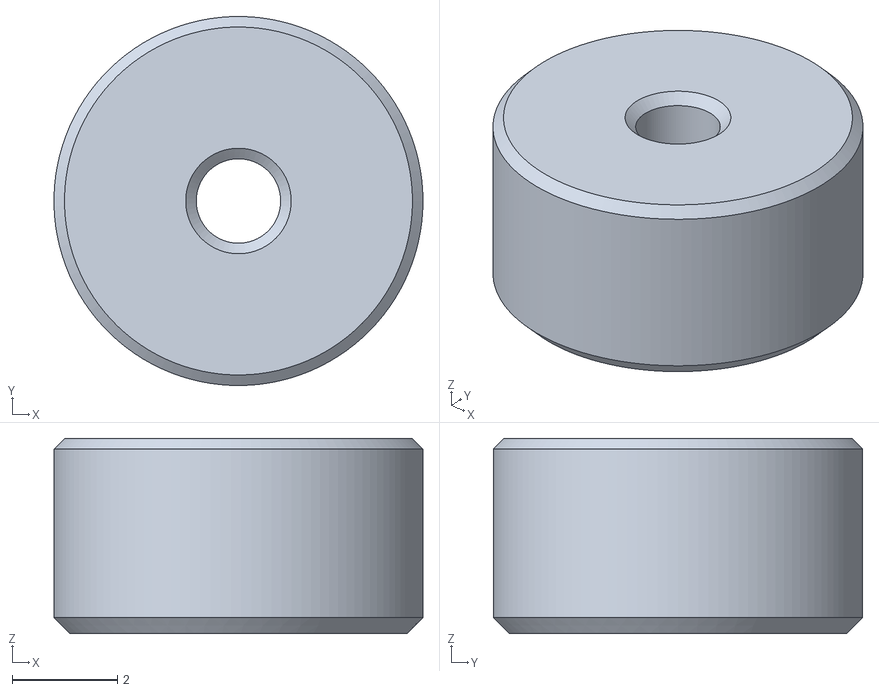
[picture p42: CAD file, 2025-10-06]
animatronicCrow/stl/ActuatorSpacer.stl
7.00 x 7.00 x 3.70

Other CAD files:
animatronicCrow/stl/HeadServoBeakMountPlate.stl
animatronicCrow/stl/HeadStepperCollar.stl

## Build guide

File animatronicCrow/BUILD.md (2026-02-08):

# Build Guide #
:de: [Crow Guides in German](https://github.com/padpumpkin/animatronicCrow-de)

## Parts List: ##
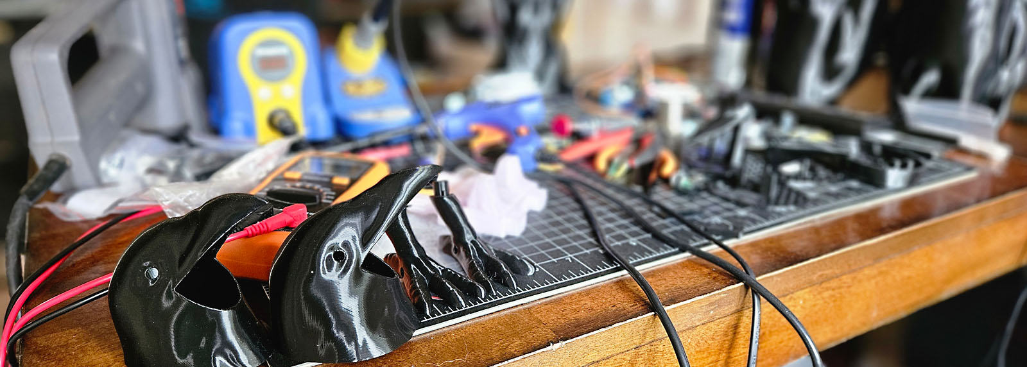
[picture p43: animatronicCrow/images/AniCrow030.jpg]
Crow parts everywhere

### Crow ###

| Qty | Part | Note |
|-----|---|---|
| 2 | 5mm Red LEDs | For the eyes. I am using frosted. |
| 1 | SG90 5v Servo | MG90S also works. |
| 1 | 28BYJ-48 5v Stepper | If using CC5x12 stepper control you do not need the breakout board (though you could transfer those components to the CC5x12). |
| 1 | 40mm 4Ω, 3w Speaker | 8Ω will work. Consider a waterproof speaker if the crow will be left outdoors. A paper cone speaker is the weakest component in wet conditions. |
| 3 | M2.6 x 10mm tapping screws | For attaching the speaker flange.
| 1 | Micro SD Card | For the mp3 audio files. |
| 1 | HC-SR312 AM312 Mini PIR | Optional. Human motion (directional) sensor. |
| 1 | 8006 Fresnel Lens (Black) | Optional. Small lens replacement for the Mini PIR sensor. 
| 1 | HLK-LD1020 10G Radar Sensor | Optional. Radar movement (non-directional) sensor. |
| 3 | Wires/Connectors | Two 2-wire and one 3-wire for the speaker, LEDs, and PIR. CC5X12 uses standard 2.54mm pin headers (or could be soldered directly). |
| 1 | Large Paperclip | ~1.25mm thick. |
| 1 | 2mm Rod | About 15mm long for the beak hinge. I'm using carbon fiber, but any material should work. |
| 9 | M3x4x5 Heat Melt Inserts | 5mm tall (M3x5x5) inserts will also fit. |
| 11  | M3 screws | 5 x 8mm for the head and tail, 4 x 6mm for the stepper and PCB, 2 x 5mm countersunk for the body (or regular 6mm should work). |
| 2 | M3 nuts | For the stepper mount collar in the head. |
| 8 | 10 x 3mm magnets | Neodymium high strength magnets for attaching tail to body. |
| | Cyanoacrylate (CA) and/or Epoxy | To attach the feet, magnets, and PIR window. |
| | Hot Glue | For sealing the speaker wire (and optionally, the speaker). |
| | Polyfill | Just a little for sound dampening in the speaker housing. |

---

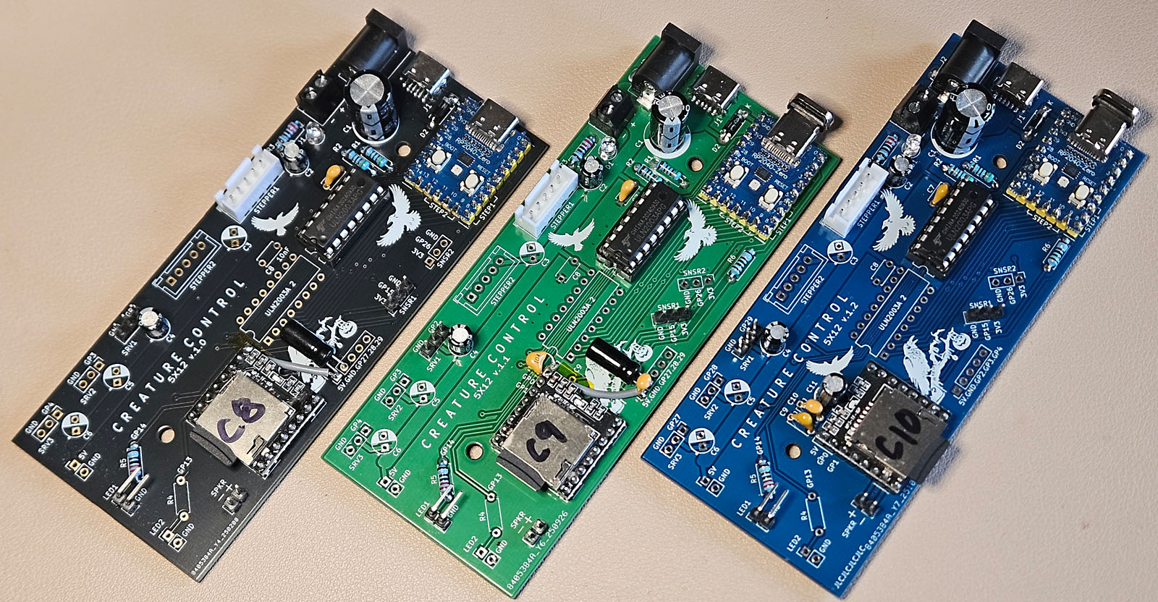
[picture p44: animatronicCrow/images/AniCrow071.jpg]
Crow modules in a Creature Control 5x12 PCB


### [Creature Control 5x12](../creatureControl/README.md) ###
Note that the CC5x12 board will not be fully filled for this project.
CC5x12 provides multiple options for powering the 5v rail.
***You must only ever connect one of them at a time***.
The RP2040-Zero can be plugged into power (including your computer) while the 5v rail is also receiving power.

#### Flashing on Arduino ####
* You may need to hold down BOOT while connecting the board to your PC for the first time if it is not recognized by Arduino. 
This will cause it to mount as a USB drive. 
* I recommend testing using the [BoardTest.ino](../creatureControl/BoardTest) in the CreatureControl project to ensure all components are working.
* Install *calibrate-crow.ino* on your completed CC5x12 board using the 'Software' guide at the bottom of this page.

| Qty | Part | Note |
|---|---|---|
| 1 | RP2040-Zero | Waveshare or equivalent. |
| 1 | DFPlayer Mini | DFRobot or equivalent. |
| 1-2 (optional) | Header sockets/pins for mounting | Socketing the RP2040-Zero and the DFPlayer mini will enable easier replacement should either fail. |
| 3 | 100nF 50v Ceramic Capacitor (104) | (v1.1+) for DFPlayer Mini VCC, (v1.2) input 5V, ULN2003A. |
| 1 | 1µF 50v Ceramic Capacitor (105) | (v1.2) For DFPlayer Mini midrange filter. |
| 1 | 220µF 10-16v Electrolytic Capacitor | (v1.2) For DFPlayer Mini ([or to modify prior versions](MaxVolBodge.md)). |
| 1 | 1KΩ Resistor | (v1.1+) for MCU GP0->DFPlayer Mini RX |
| 1 (optional) | IC DIP Socket 16-Pin | For ULN2003A. Or just solder directly to the board. |
| 1 | ULN2003A | |
| 1 | XH2.54mm 5-Pin Connector | Straight pin for stepper. |
| 1 | 1N5819 Schottky Diode | For RP2040-Zero VCC. |
| 1 (optional) | 3mm LED | For power rail indicator. |
| 1 (optional) | Resistor for above LED | I used 2.2kΩ for a blue 3mm LED. |
| 1 | Resistor for Eye LEDs | I used a 2.2kΩ for a pair of red 5mm LEDs wired in parallel. |
| 1 | 1uF 50v Ceramic Capacitor (105) | For ULN2003A (mislabelled on v1.0 silk). |
| 2 | 100uF 16v Electrolytic Capacitor | For servo and stepper. |
| 1 | 1000uF 16v Electrolytic Capacitor | For 5v rail. |
| 1 (optional) | 5.5x2.1MM DC-005 Power Jack | If using a 5v/3A adapter. |
| 1 (optional) | USB-C 6-pin Surface Mount | If using a USB battery. |
| 2 (optional | 5.1kΩ Resistors | If using a USB battery. |
| optional | 2.54mm Pin Headers | If not soldering wires directly to board. |

___
## Head ##

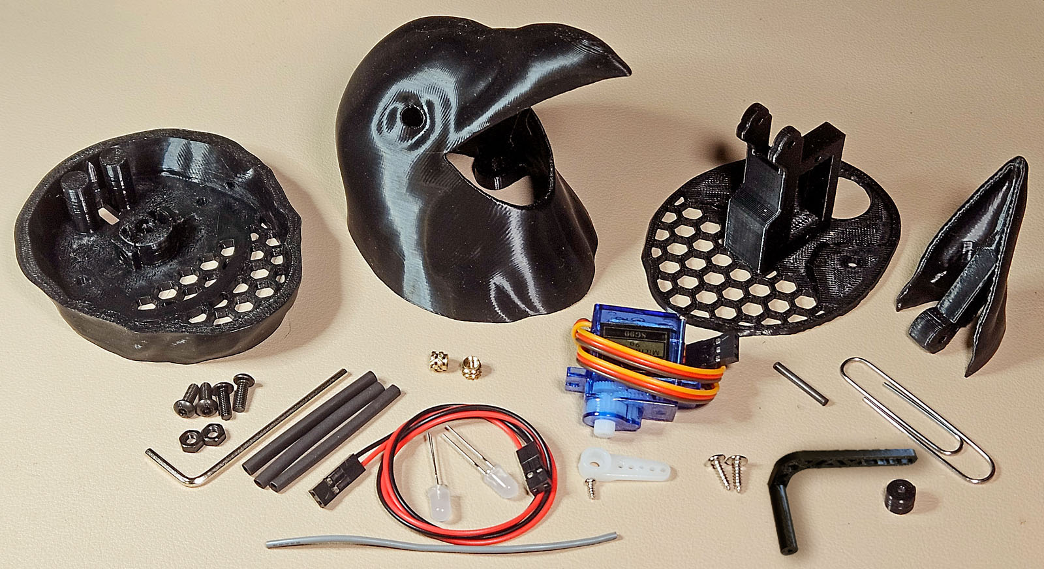
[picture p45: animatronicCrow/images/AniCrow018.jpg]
Crow Head Parts


| | |
|---|---|
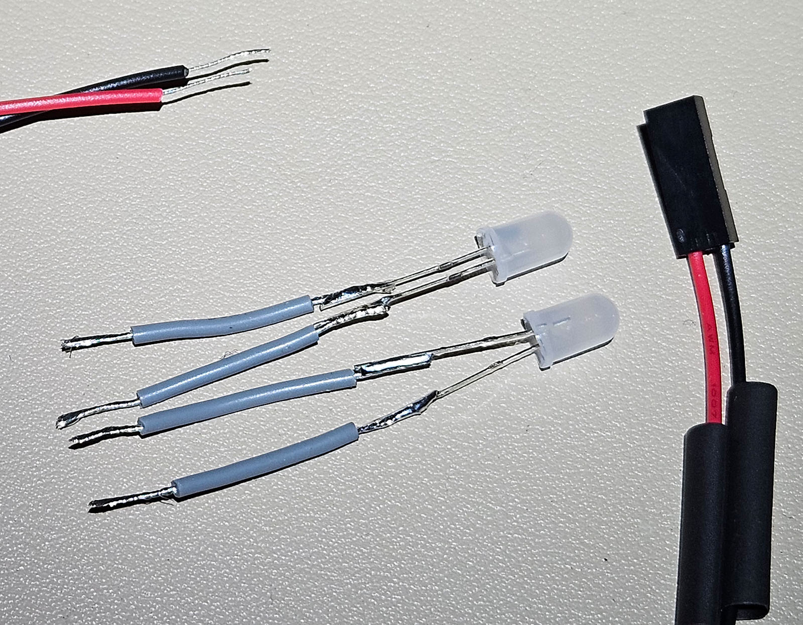
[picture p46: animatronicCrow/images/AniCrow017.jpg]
LEDs for crow eyes
|  | Begin by assembling the LEDs. The resistor will be on the board, so you just wire them in parallel. I'm using a 2-wire connector from which I've cut the end and stripped the wires, plus a couple small pieces of high-temp wire and some heat shrink tubing. |
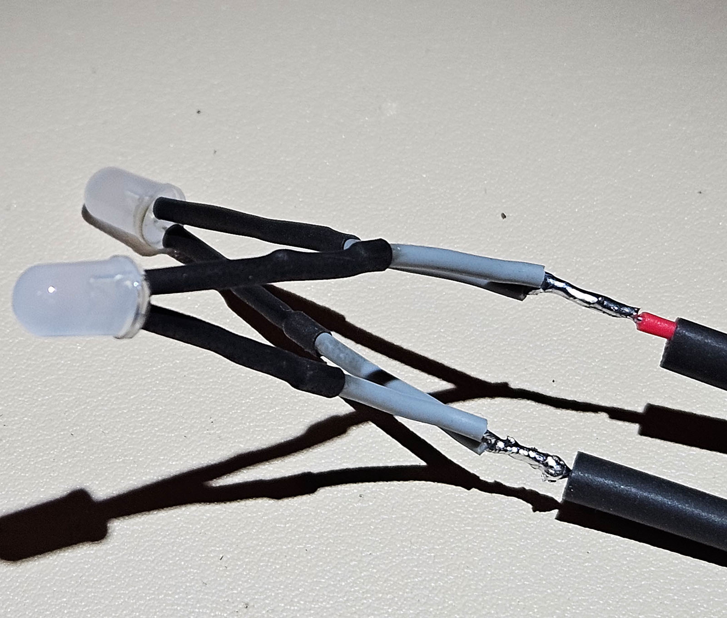
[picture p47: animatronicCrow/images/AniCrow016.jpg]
Soldered LEDs for crow eyes
|  | Solder the LEDs together "stacked," putting the positive and negative leads together with the positive or negative wire. Cover all exposed wiring with heat shrink tubing or electrical tape. |
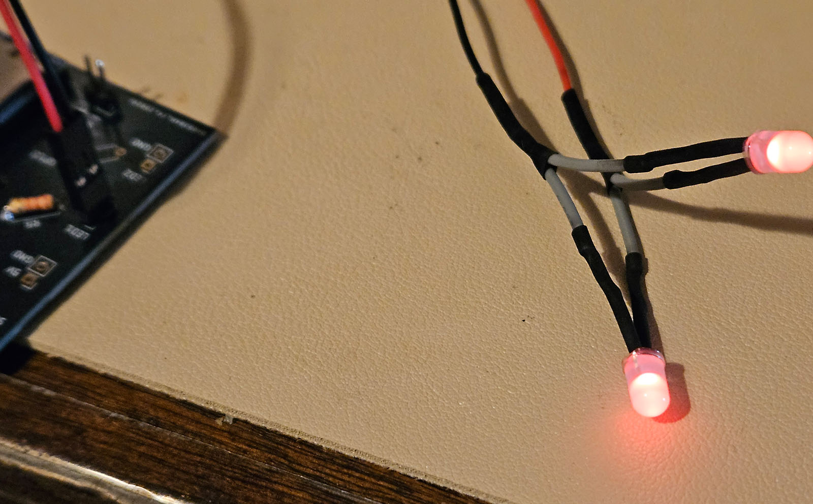
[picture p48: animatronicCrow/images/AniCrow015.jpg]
Crow LED eyes test
|  | Before assembling, test with calibrate-crow.ino script loaded onto your CC5x12 board. Both lights should illuminate evenly. |
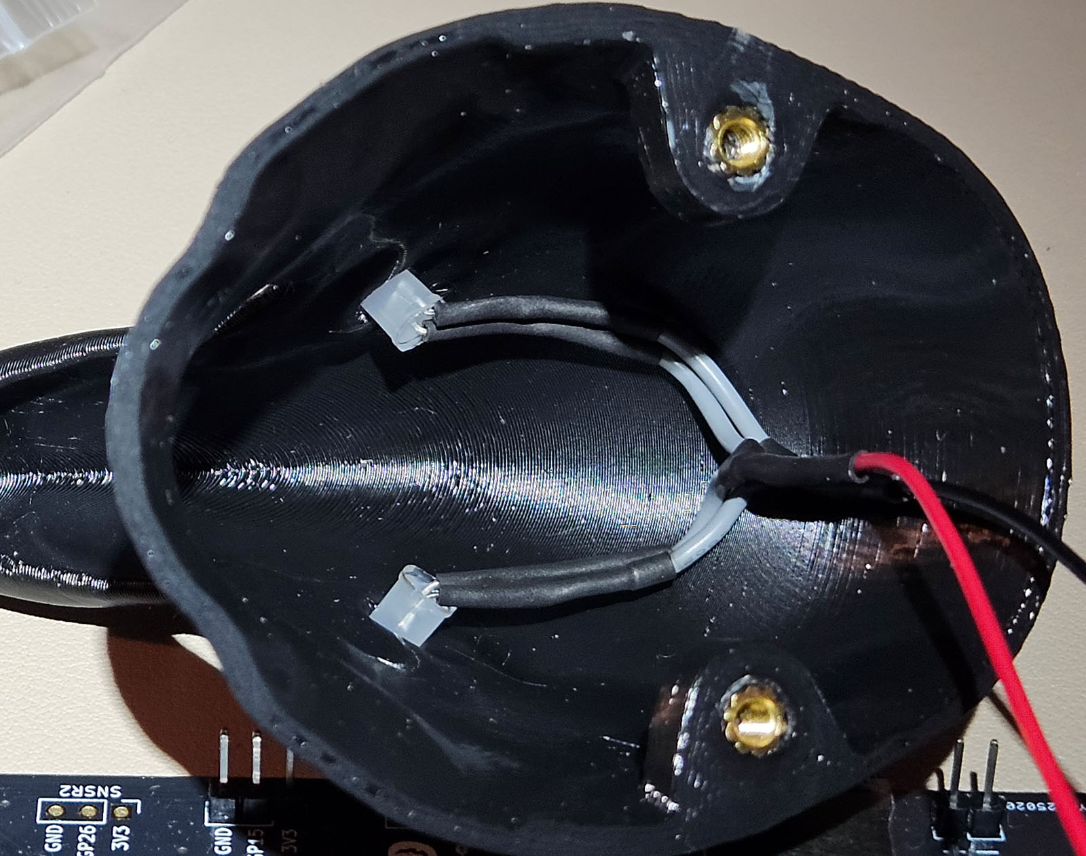
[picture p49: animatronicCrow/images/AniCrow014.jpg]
Crow LED eyes installed
|  | Carefully bend and fit both eyes into the sockets so that the cables lay nicely and run down the back inside of the head. Adjust the depth to an aesthetic level (don't push them all the way in.) |
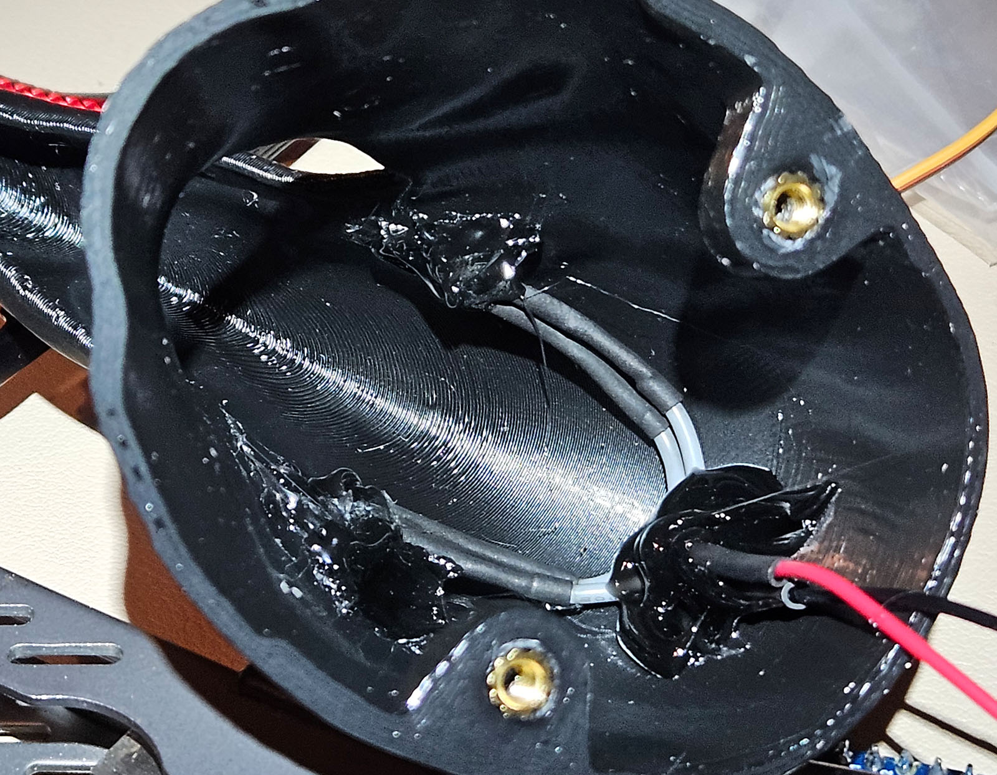
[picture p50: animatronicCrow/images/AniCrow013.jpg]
Crow LED eyes glued
|  | With everything in place, lock in the eyes and cable connections with hot glue. Leave it to cool completely with everything in place. |
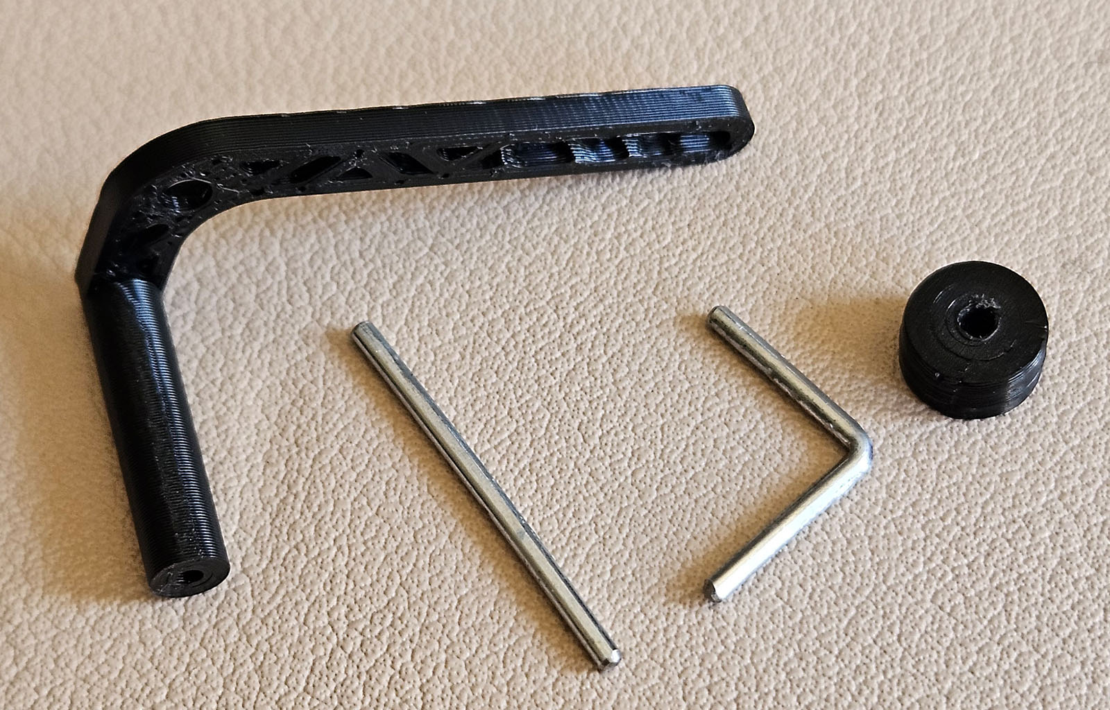
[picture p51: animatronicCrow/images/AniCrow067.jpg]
Crow actuator parts
|  | The actuator is made from four small parts. I recommend printing these with a 0.2mm nozzle for strength and accuracy. The metal bits are from a large (~1.25mm thick) paperclip. |
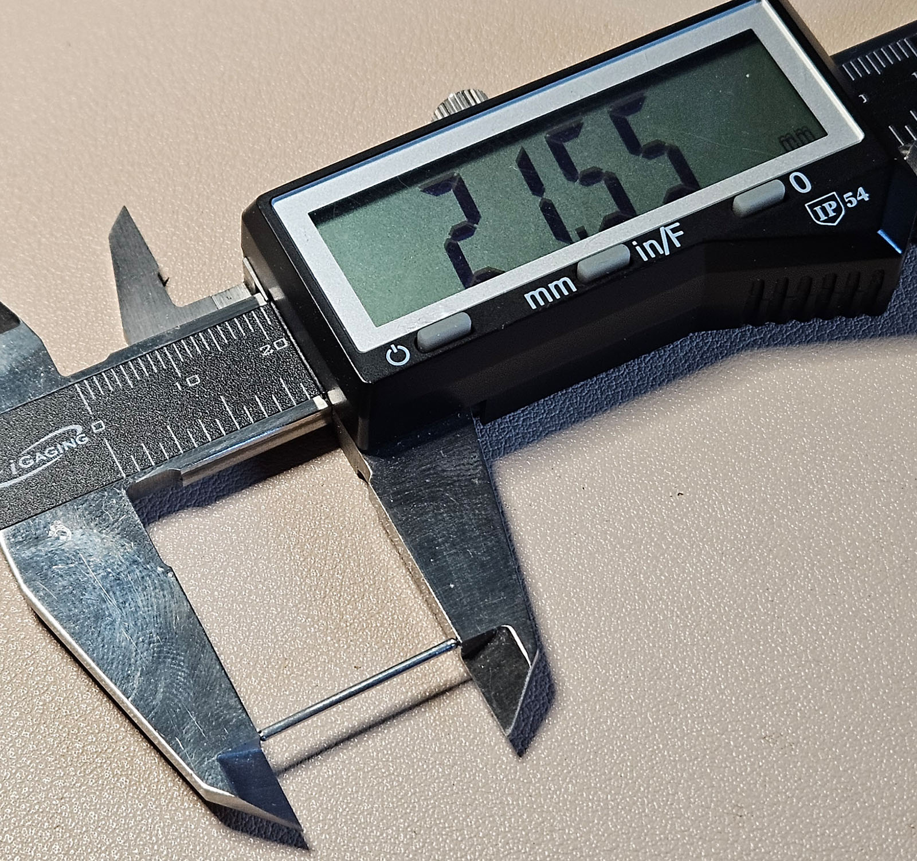
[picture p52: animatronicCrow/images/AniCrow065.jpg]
Actuator hinge pin
|  | The hinge pin for the beak needs to be 21.5mm long (21 to 21.6mm is acceptable) and have smooth, rounded ends. If possible, use a micrometer and a small grinder (or file) to ensure the length is correct and the ends are rounded off. |
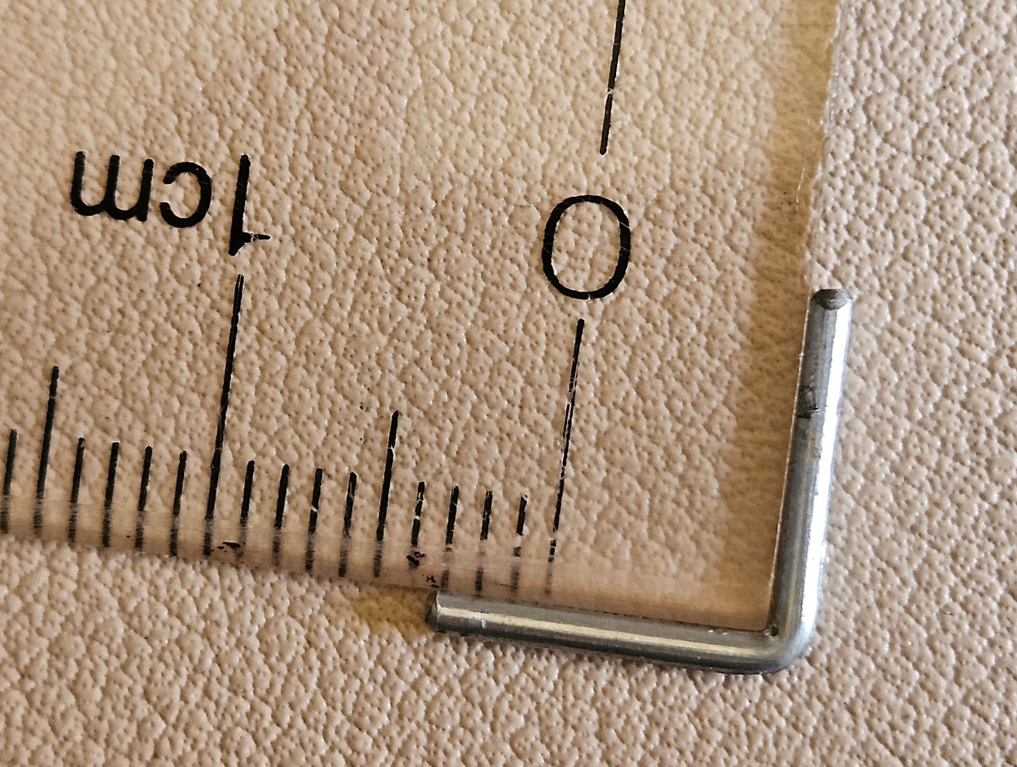
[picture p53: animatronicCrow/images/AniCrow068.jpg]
Actuator servo connection
|  | Bend a second ~20mm piece (also with rounded ends) into a sharp 90-degree angle. The tighter the better. |
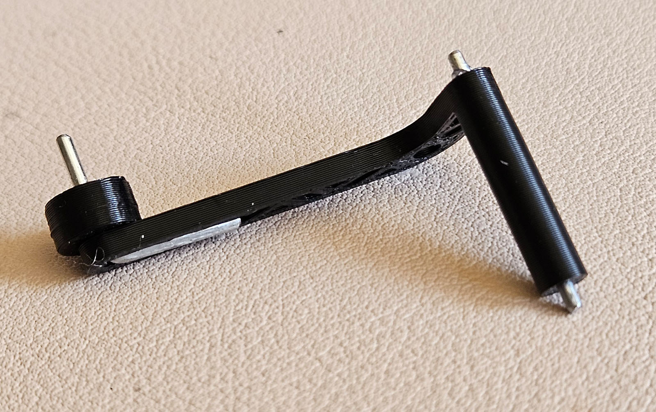
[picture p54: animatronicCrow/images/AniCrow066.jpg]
Assembled actuator
|  | The assembled actuator looks like this. The 90-degree piece should snap into place, but a touch of glue won't hurt. |
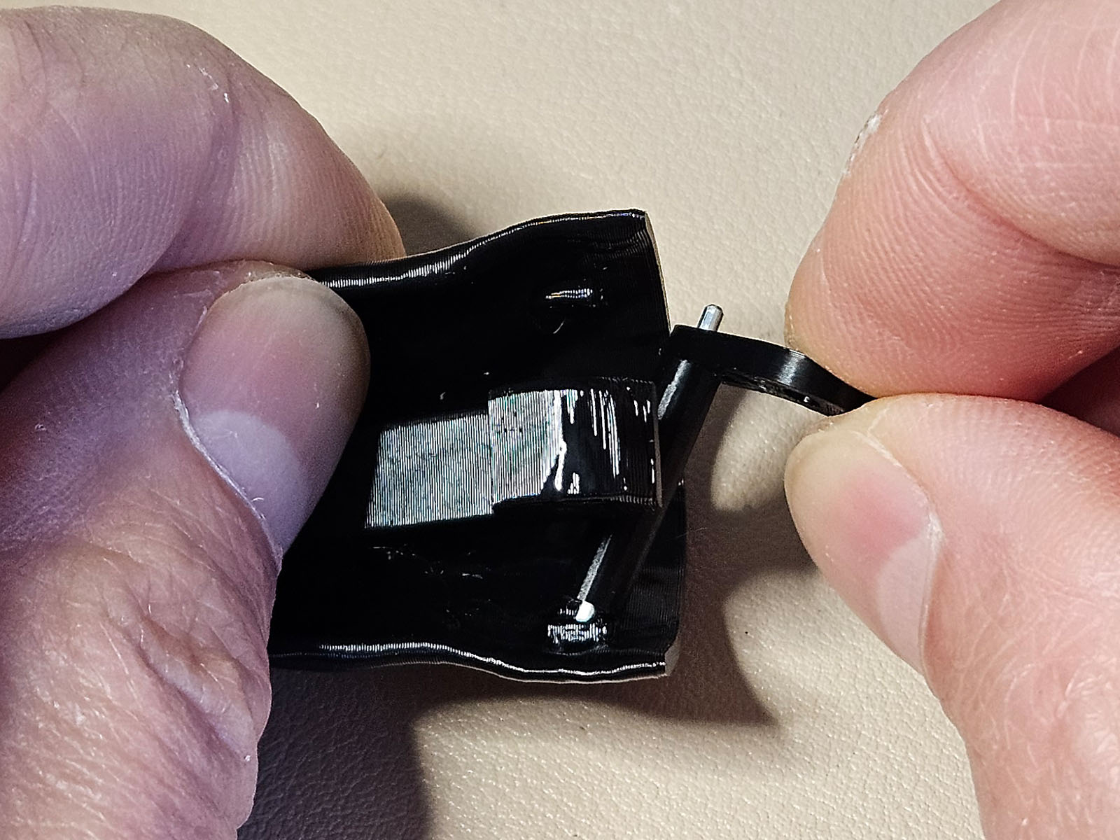
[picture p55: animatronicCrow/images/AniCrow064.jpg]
Insert the left side of the actuator pin
|  | Installing the actuator into the beak requires a firm hold since you need to flex the plastic. Start by putting the long (left) side into the hole as shown. |
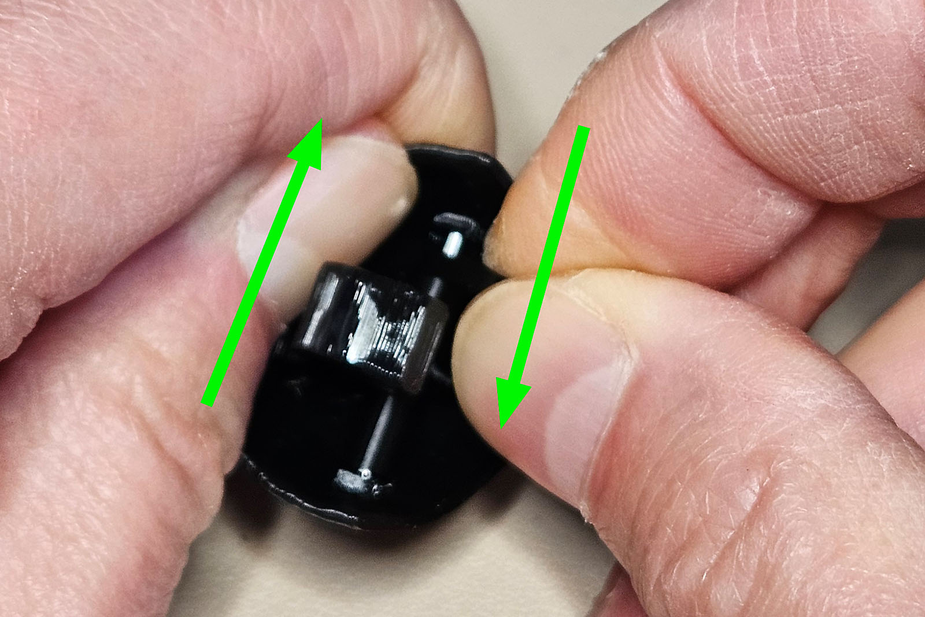
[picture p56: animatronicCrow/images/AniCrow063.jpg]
Flex the beak and swing the right side into place
|  | While simultaneously pushing down with the actuator and flexing the right side of the beak up (away) pivot the pin into the second hole. |
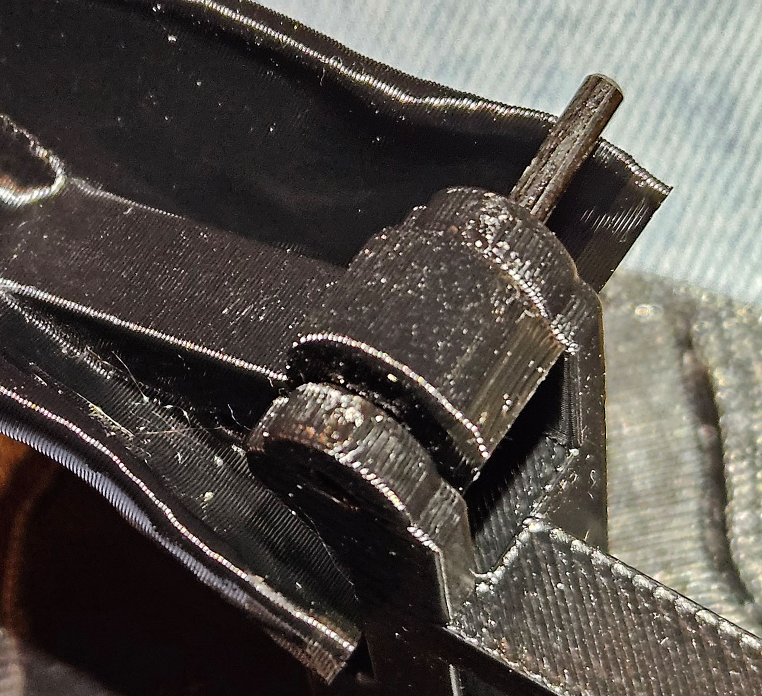
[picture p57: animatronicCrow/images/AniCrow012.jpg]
Crow beak hinge pin install
|  | I'm using a graphite 2mm rod but any 2mm material should work. Cut it just longer than the support and round over the ends. It's a little easier to press it through from the right side. Be careful not to bend the tower tabs as they are somewhat delicate. |
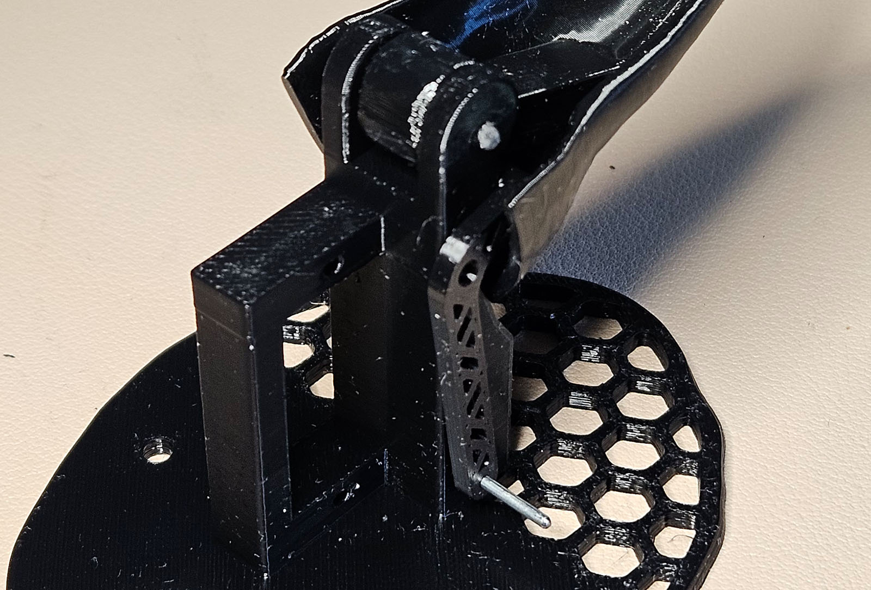
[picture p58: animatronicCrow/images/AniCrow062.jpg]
Beak and actuator attached to servo mount
|  | The assembled beak, servo plate, and actuator should move freely. Add (dry) lubricant to the beak hinge pins and the surface on the side of the mount where the actuator will slide. Note that the actuator will not hit the beak hinge pin. |
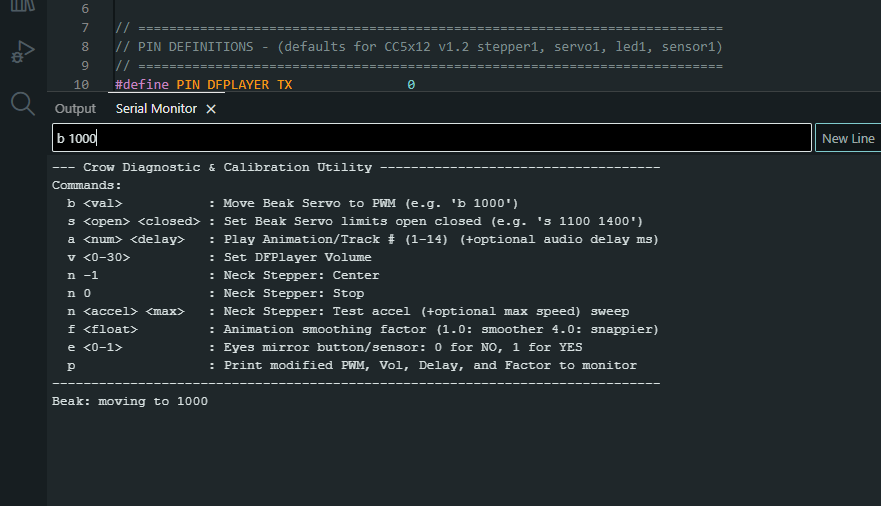
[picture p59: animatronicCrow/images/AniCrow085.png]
Reset the servo position
|  | Connect your SG90 (or MG90S) servo to the CC5x12. Connect power to the 5v rail and the MCU's USB to your PC. Compile and upload the appropriate *calibrate-crow* sketch to your CC5x12 (see 'Software' below) and enable the the Serial Monitor. Once the instructions are displayed (or enter `?` to display them) move your servo to the 1000 PWM position by typing `b 1000`. You should hear the servo adjust to that position. Disconnect power and your servo and continue. |
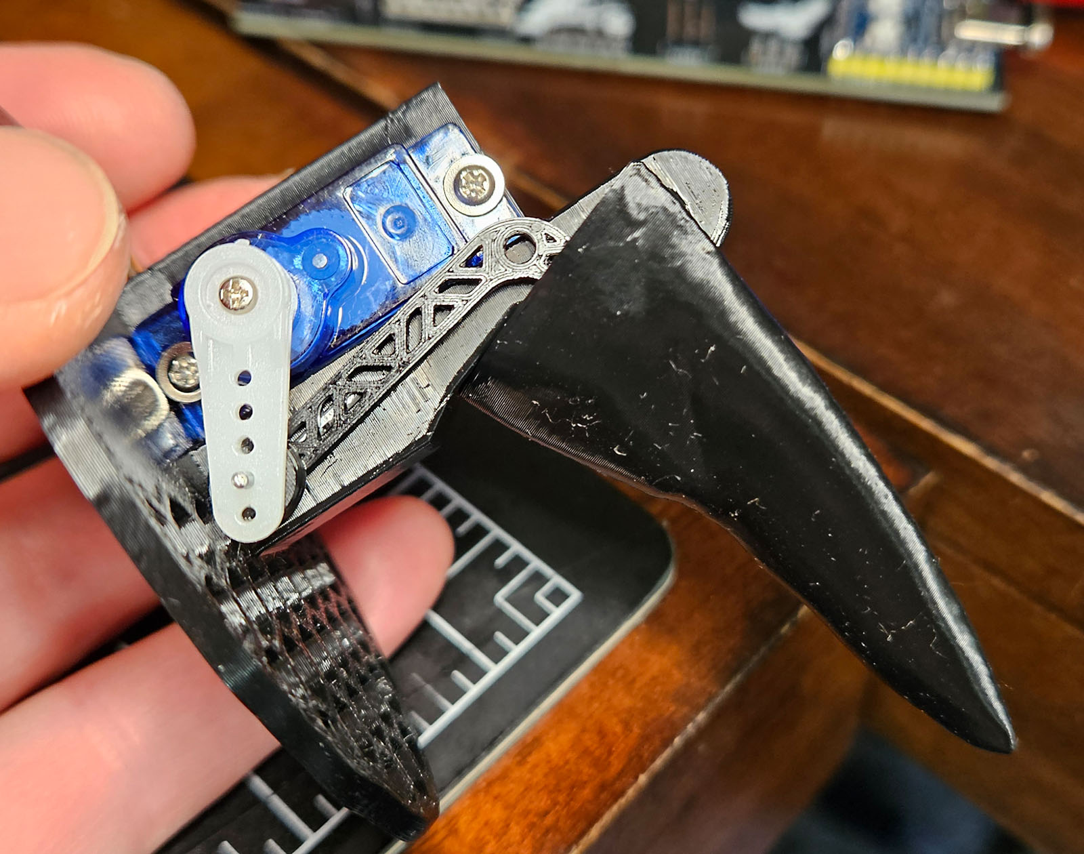
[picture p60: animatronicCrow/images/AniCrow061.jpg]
Attach servo arm at lowest position
|  | Install the servo with the wires towards the plate. Attach it with the two provided screws. Hold the beak all the way down, place the spacer on the actuator pin and and hook the single servo arm over it at the second-to-last hole. Slide the arm onto the servo gears as low as it will go without hitting the plate or putting the gears under tension. Install the screw. |
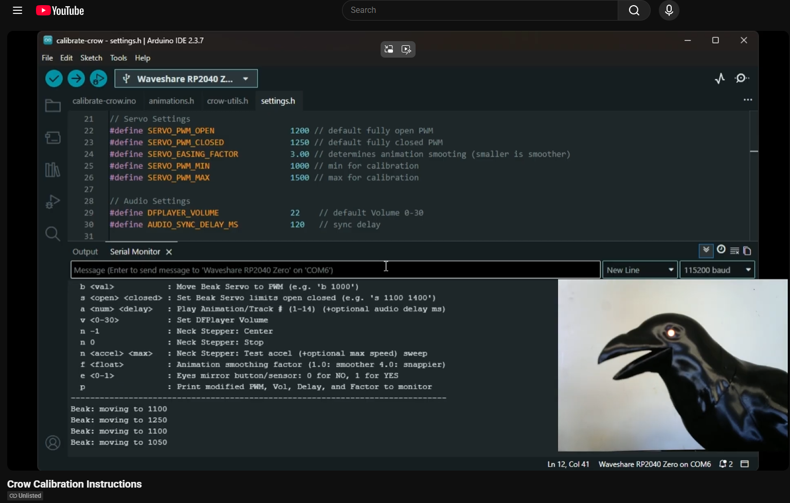
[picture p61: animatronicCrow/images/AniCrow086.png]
Validate the ranges in software
| [ YouTube Video](https://youtu.be/_if5lX7wsH4) | Connect the servo mount plate to the head with a couple M3 screws and reconnect the CC5x12 (power and USB). The beak should move to a central position once it starts up. Enable the Serial Monitor.<br/><br/> * To find your OPEN and CLOSED PWM, send different values to the crow by entering `b <value>` into the Serial Monitor. You're looking for the lowest value that does not pull against the bottom and the highest value that does not press the beak shut. Small changes matter.<br/><br/>* Once you determine these values, write them to memory by typing `s <OPEN> <CLOSED>`.<br/><br/>* Connect your speaker and test animations and delay with `a <NUM> <DELAY>` where NUM is 1-14 and DELAY is the amount of time to wait for the DFPlayer Mini to begin playing. Usually 100-200ms. You want to find the value that best synchronizes the beak motion with the audio.<br/><br/>* If the beak is snapping  open/closed too hard, lower the smoothing factor by entering `f <FACTOR>` where FACTOR is a floating point number between 1.0 (very smooth) and 4.0 (very snappy). Find the value that works best for your hardware.<br/><br/>* With these determined, press `p` to print them to the Serial Monitor. Save them and change these values in your *animatronic-crow/settings.h* file.<br/><br/> |
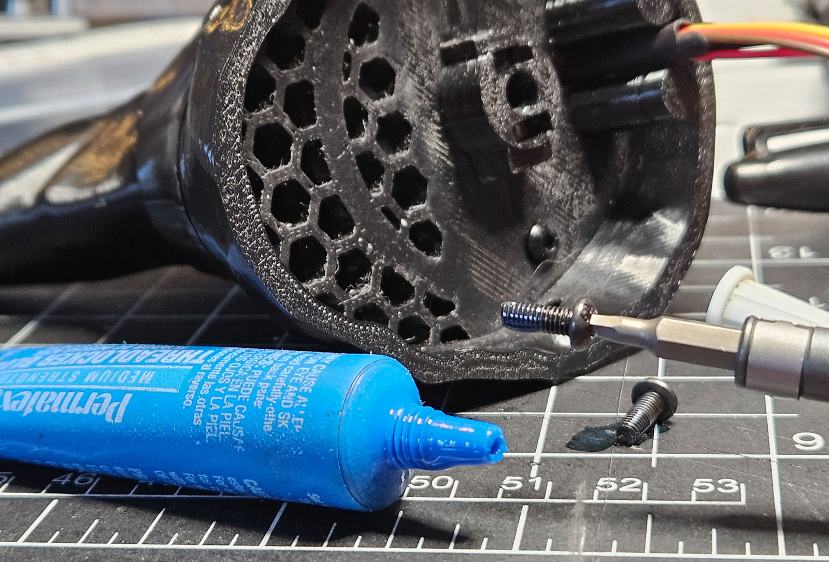
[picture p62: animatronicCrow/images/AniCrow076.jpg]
Consider thread locker on head collar screws
|  | Consider adding a thread locker to the stepper collar mounting screws. Clean the screws and nuts with isopropyl alcohol to remove oil and add a small amount of a removable thread locker to the threads. |
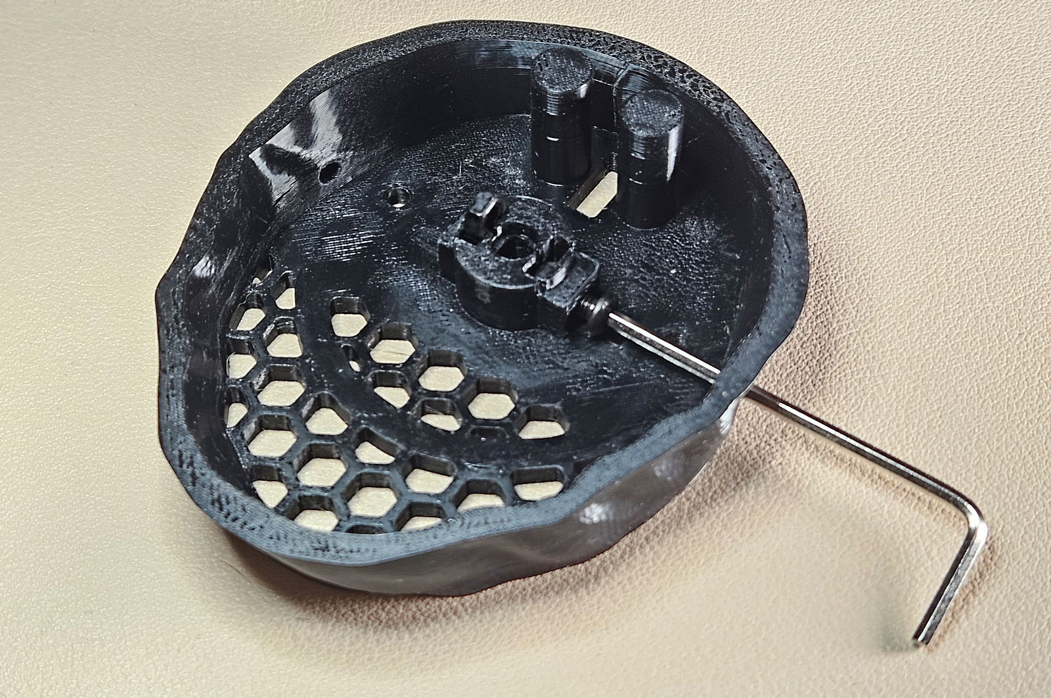
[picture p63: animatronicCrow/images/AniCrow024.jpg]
Install mounting screws into stepper collar
|  | Sand the sliding arc surface on the inside of the stepper collar smooth and lube with dry lube. Drop two M3 nuts into the slots and install two 8mm M3 screws by fitting the hex wrench through the access holes until they will just touch the stepper pin. |
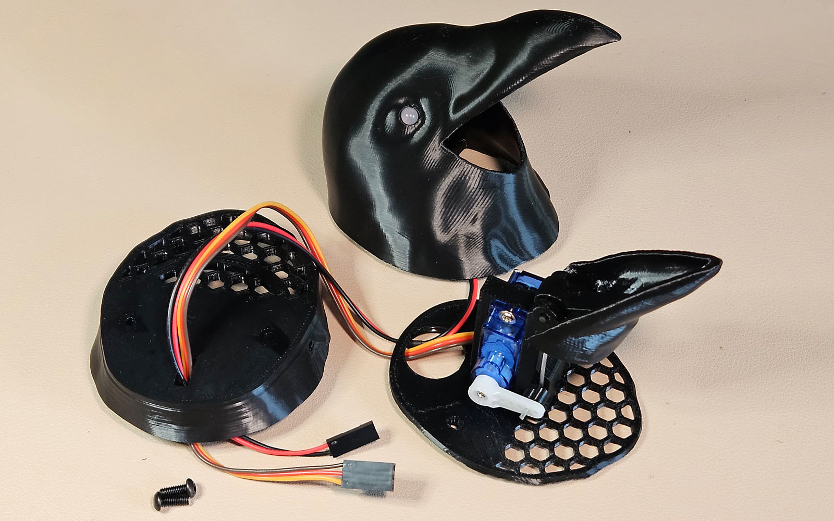
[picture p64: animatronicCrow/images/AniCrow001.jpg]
Assembly
|  | Once everything looks good, route the cables through the plates. Stack the parts and join them with two M3 8mm screws. Your crow head is ready to go. |

___
## Body ##

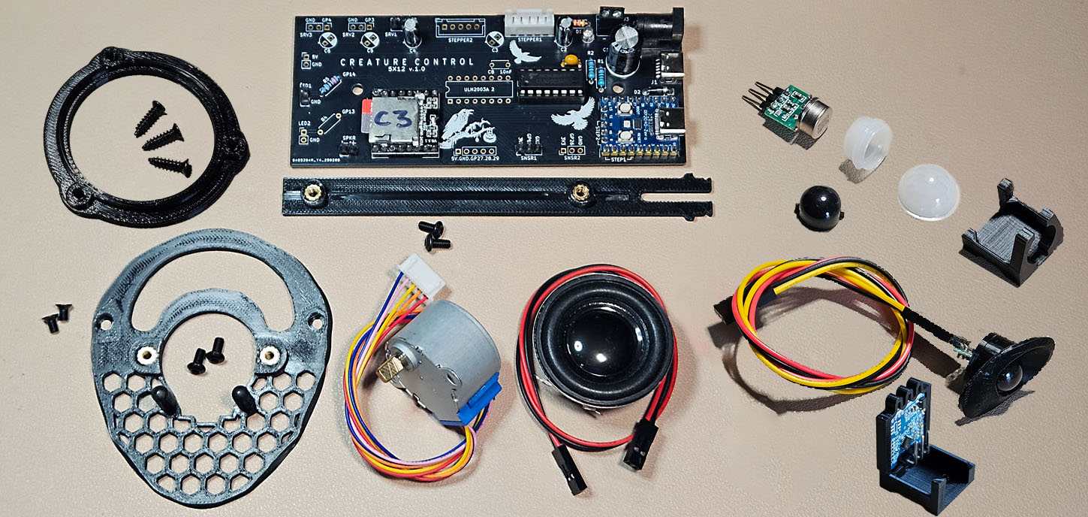
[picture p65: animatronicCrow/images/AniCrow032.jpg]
Crow Body Components


| | |
|---|---|
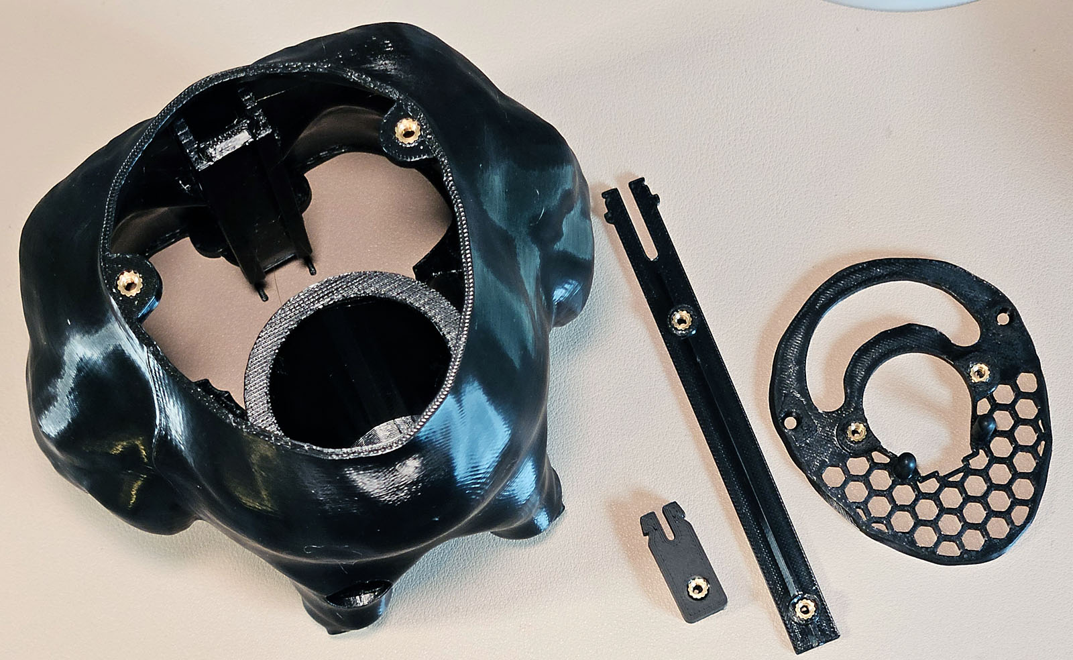
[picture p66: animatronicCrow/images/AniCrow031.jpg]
Install M3 heat melt inserts
|  | Install seven heat melt inserts. Two for the stepper plate, two for the stepper, two for the PCB, and one for the tail tab. |
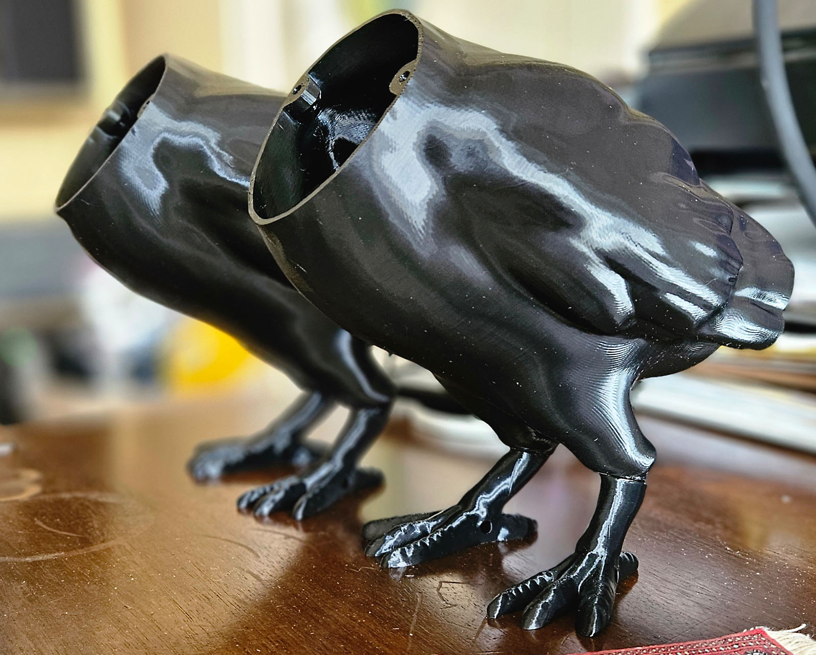
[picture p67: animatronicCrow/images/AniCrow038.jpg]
Glue on the feet
|  | Glue on the feet. I used 2-ton epoxy with a slower cure time. Coat the feet sockets and pegs and after installing them stand the crow upright on a flat surface and adjust the feet slightly with a little downward pressure on the body before leaving them to set. |
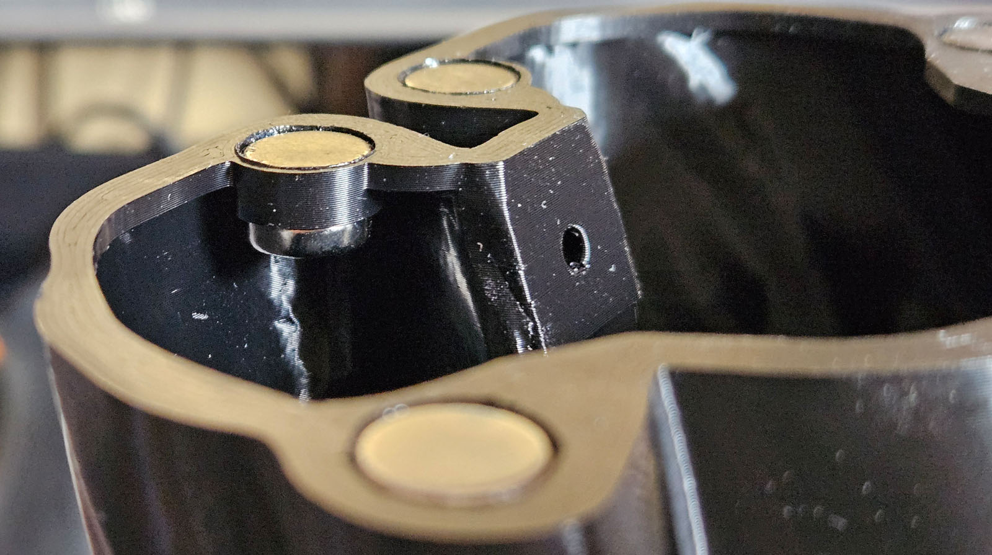
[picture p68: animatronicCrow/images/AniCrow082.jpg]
Glue on the magnets
|  | Remove supports and scrape the magnet recesses clear. Glue magnets using epoxy or CA while paying close attention to polarity. |
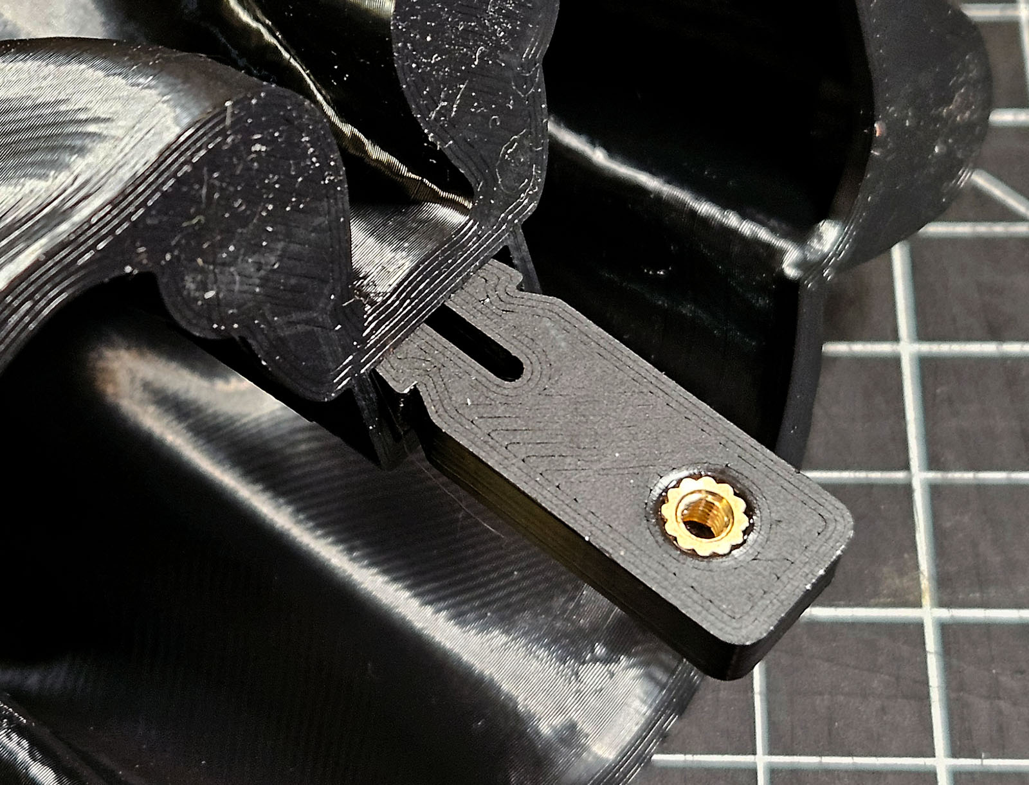
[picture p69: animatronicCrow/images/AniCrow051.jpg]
Add the tab to the tail
|  | The tail tab is designed to snap into place. You might need to press hard until it clicks. |
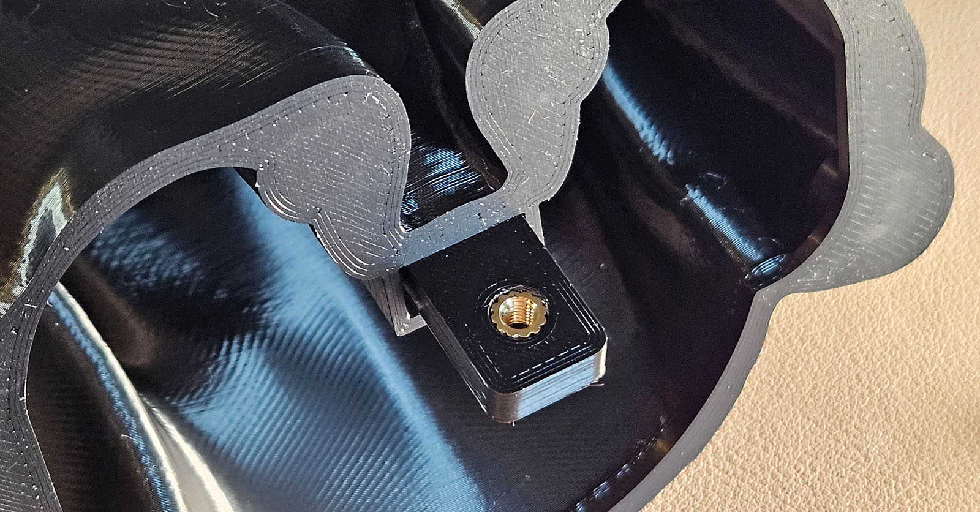
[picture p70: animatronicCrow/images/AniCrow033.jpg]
Tail tab installed
|  | With the tab installed, the tail is ready to go. |
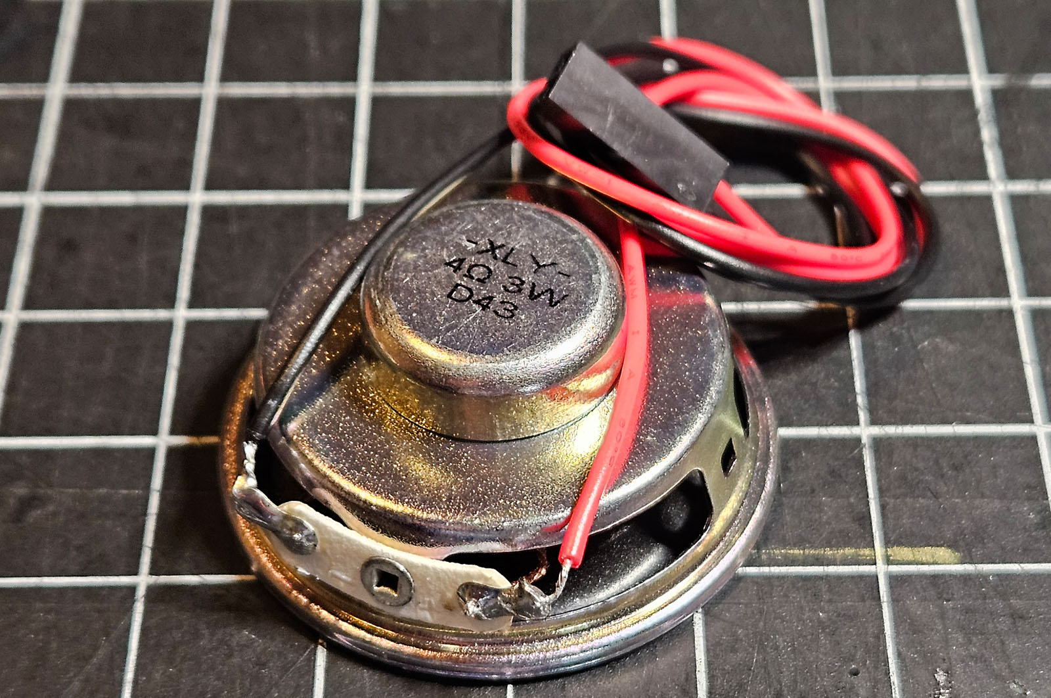
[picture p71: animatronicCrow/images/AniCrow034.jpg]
Prepare the speaker
|  | Attach the lead to the speaker. I clipped the end of a standard 2-pin connector and soldered the ends directly to the speaker. Once glued in place there shouldn't be any strain on the wires. |
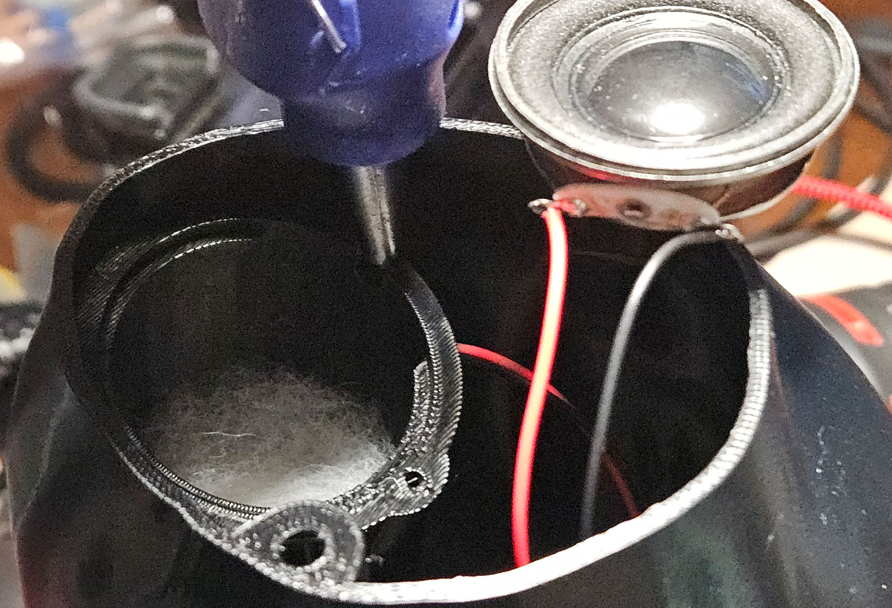
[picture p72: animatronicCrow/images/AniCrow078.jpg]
Add glue to the speaker wire pass-thru
|  | Prepare the speaker by feeding the connector through the guide ring on the side of the speaker box. Note the loose polyfill in the speaker box. This is intended to reduce noise, but might be best left out if the model will be outside in wet conditions. Seal the wires into the slot using hot glue or another sealant. |
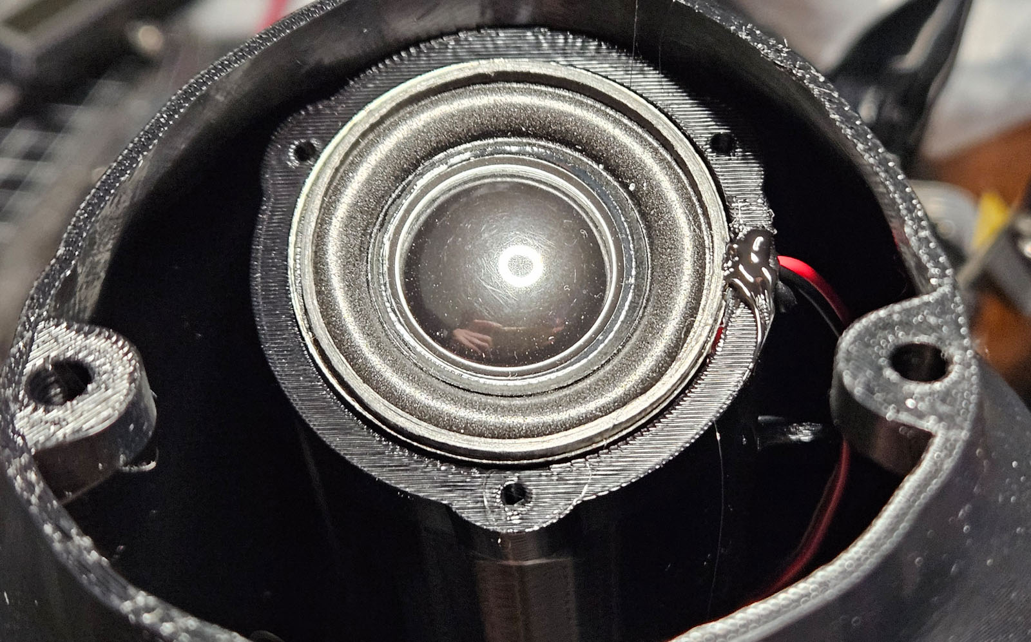
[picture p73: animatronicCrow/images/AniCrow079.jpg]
Install the speaker and seal the wires
|  | After placing the speaker into the fitting, top up the glue or sealant around the wires to prevent a sound leak. |
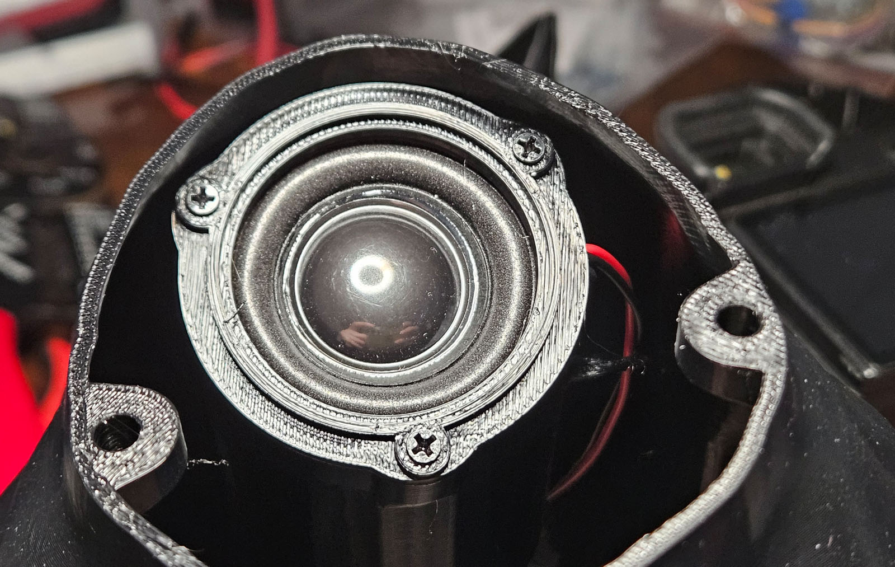
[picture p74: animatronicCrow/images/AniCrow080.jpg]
Install the speaker ring with screws
|  | Install the speaker flange with 2.6mm x 8mm tapping screws. Alternatively, glue the speaker into the housing. |
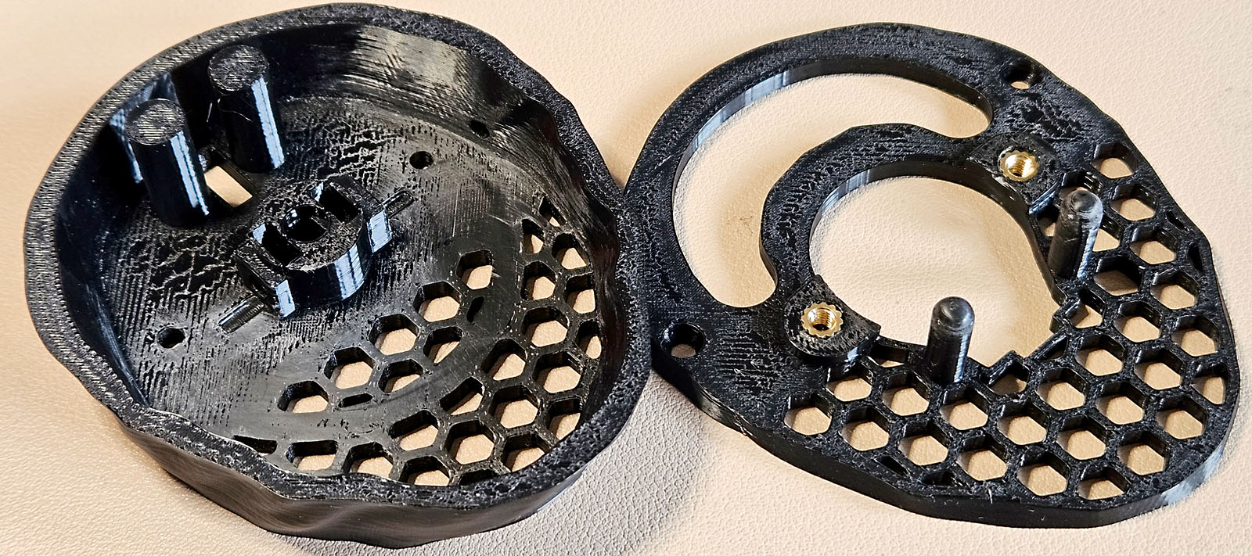
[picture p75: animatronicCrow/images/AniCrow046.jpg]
Prepare the stepper mounting plates
|  | The crow's head rotates on the two pegs that stick out just to the sides at the bottom of the stepper mount. I am sanding these (and the sweeping arc on the stepper collar that mounts to the head) to 800 grit and coating them with dry PTFE lubricant. |
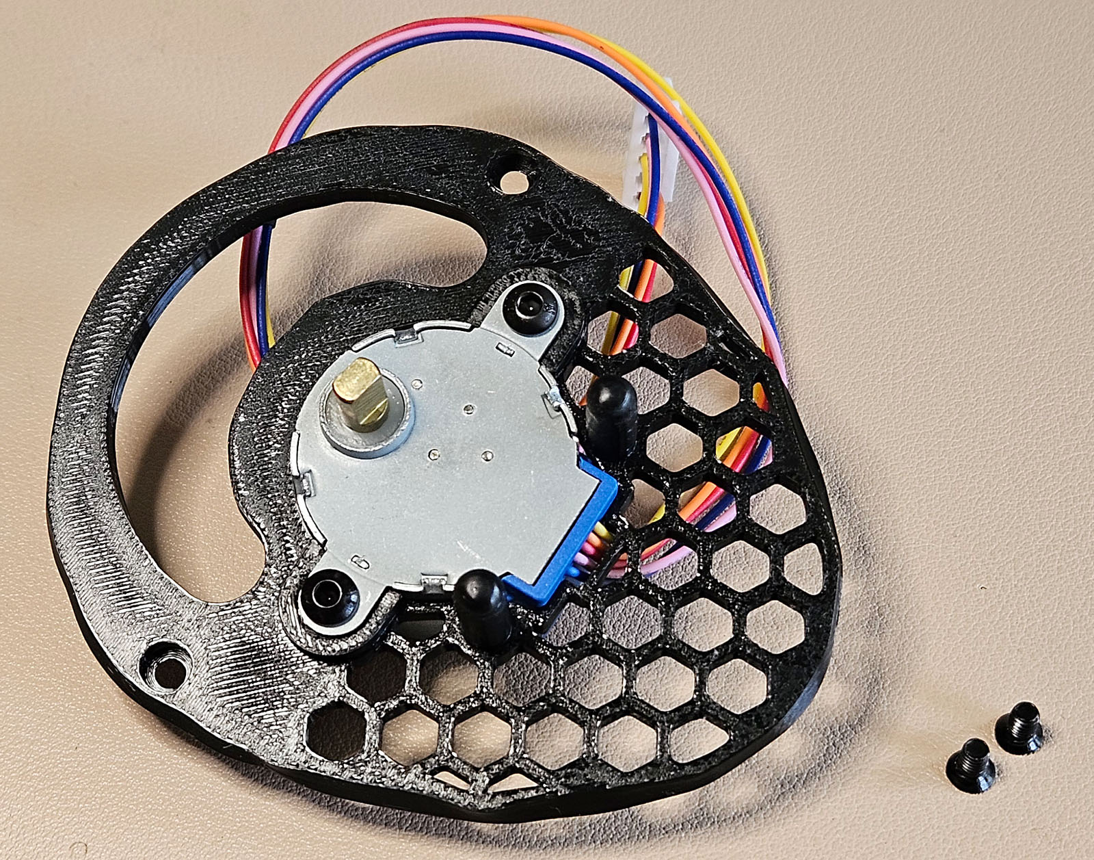
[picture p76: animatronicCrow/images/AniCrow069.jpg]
Mount the stepper to the plate
|  | Install the stepper with two M3x6 screws. I am using two M3x5 countersunk screws to attach the plate to the body, but regular M3x6 screws should work as well. |
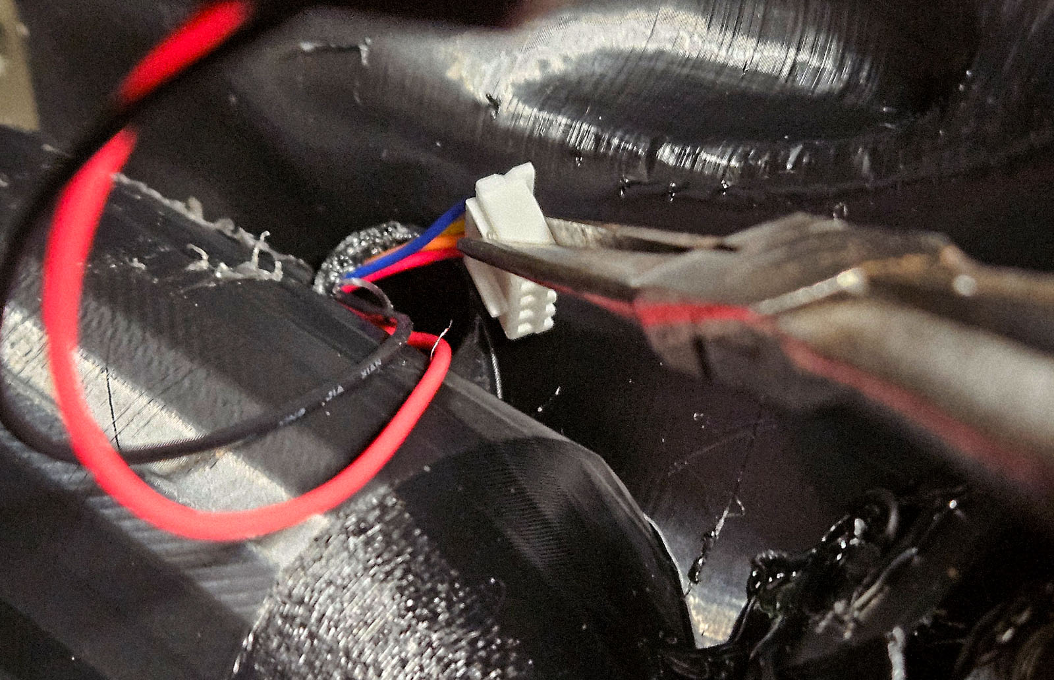
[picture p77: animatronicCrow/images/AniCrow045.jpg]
Route the stepper wire through the ring
|  | Routing the stepper connection requires some very long needle-nosed pliers. Bend the wires sideways and slip the connector and wires through the same ring you put the speaker wires through. |
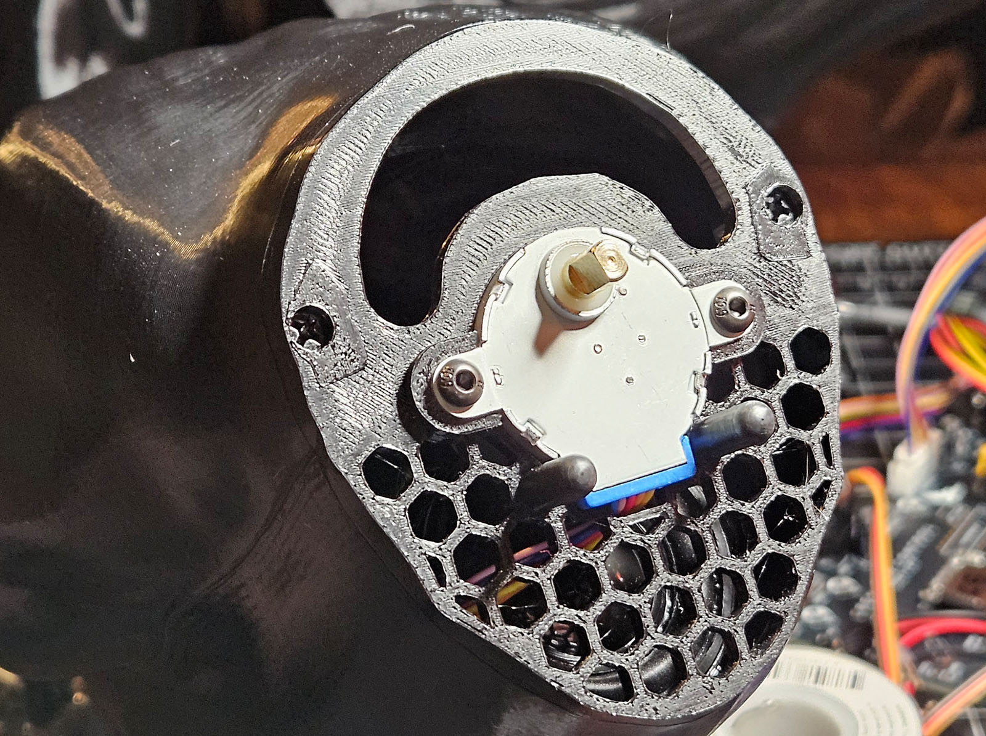
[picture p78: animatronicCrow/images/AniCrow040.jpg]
Attach the stepper plate
|  | Attach the stepper plate to the crow body using M3 screws. |
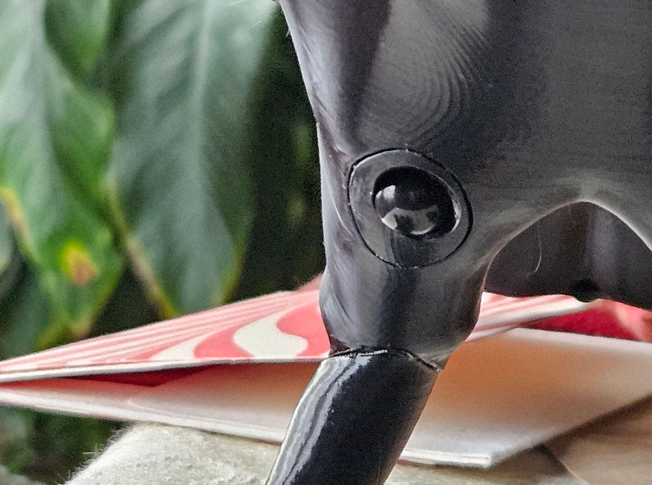
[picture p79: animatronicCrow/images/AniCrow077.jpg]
|  | **1a: PIR Sensor with Black Fresnel (my preferred)**<br/><br/>*The sensor is optional*<br/>The small, black fresnel lens (8006) is an upgrade to the mini-PIR sensor. The holder is printed in two pieces and will need to be glued together (heat can damage the PIR sensor) and glued into the body. |
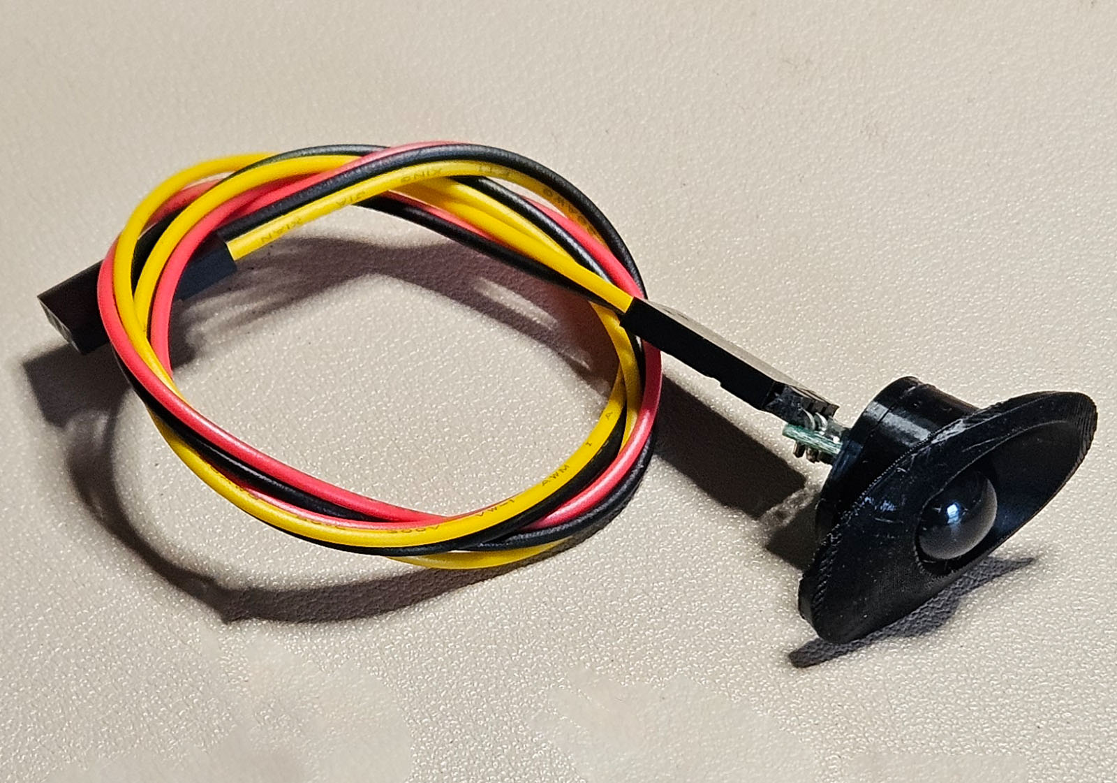
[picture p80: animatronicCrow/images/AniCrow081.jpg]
|  | **1b: PIR Sensor with Black Fresnel (my preferred)**<br/><br/>Prepare by replacing the lens (clean the sensor and ensure the inside of the fresnel lens is clear), inserting it into the leg plug, and gluing on the rear cap. I also place a little hot glue on the 3-pin connector just to ensure it doesn't pull off during assembly. |
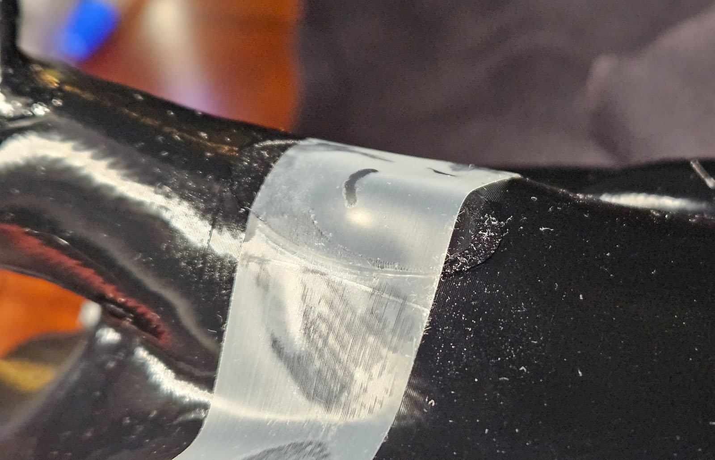
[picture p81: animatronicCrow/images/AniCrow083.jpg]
|  | **1c: PIR Sensor with Black Fresnel (my preferred)**<br/><br/>Take care gluing the plug into the knee. I prefer epoxy for this, but either glue needs to be managed with care to prevent damage to the finish. |
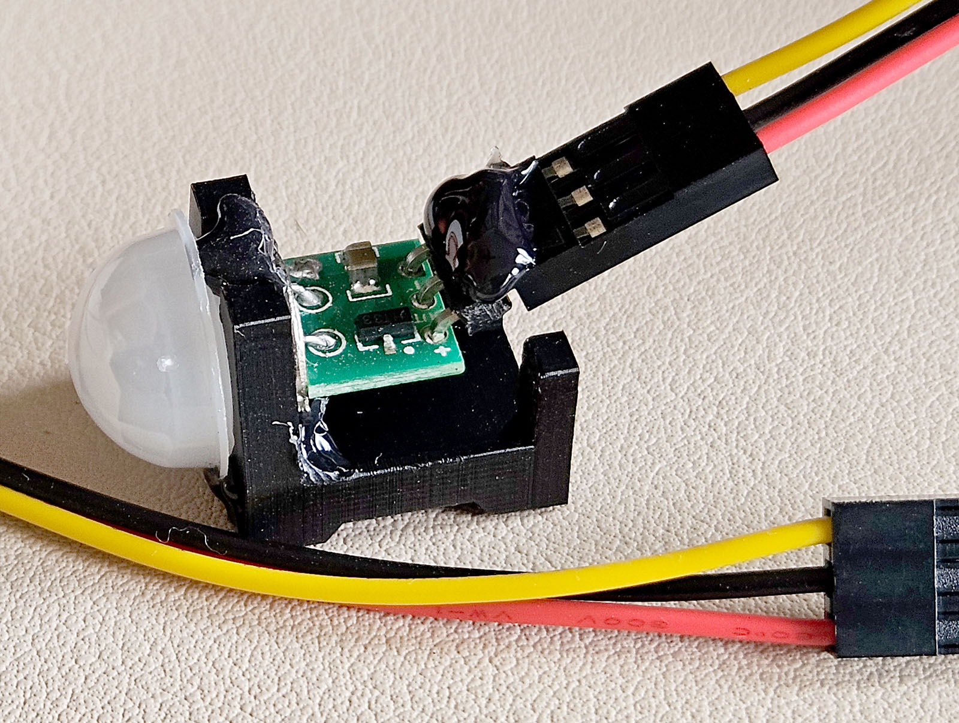
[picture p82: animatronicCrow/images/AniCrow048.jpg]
Prepare the PIR sensor
|  | **2a: PIR Sensor with Standard Fresnel**<br/><br/>*The sensor is optional*<br/>It's better to print the PIR sensor mount face-down with a 0.2mm nozzle.<br/><br/>There is not much room for the wires, so either install the header vertically or bend it like I have (a risky maneuver). Add some hot glue to ensure things don't shake loose. |
| Prepare the Radar sensor | **3a: Radar Sensor**<br/><br/>*The sensor is optional*<br/>It's better to print the radar sensor mount face-down with a 0.2mm nozzle.<br/><br/>There is not much room for the wires, so I've used a 90-degree pin header. Add some hot glue to ensure things don't shake loose. |
| Install the sensor | **2b & 3B PIR: Sensor with Standard Fresnel *or* Radar Sensor:** Installing the sensor is fiddly and requires slightly flexing the holder. Practice ahead of time with the empty holder. To remove the holder, grab the little column (green arrow here) with a pair of pliers and lift it upwards. |
| Install the "Try Me" Button | **4a: "Try Me" Button**<br/><br/>*Optional*<br/>To utilize the pushbutton feature, attach a two-pin button (either NO or NC) to the SNSR1 GND and GP15 pins (connect nothing to the 3V3 pin). Route the wire out through the hole behind the left leg or tail. |
| Attach the head | Install the head on the stepper and use a piece of card stock to "shim" the top edge (green arrow). Using a 2mm hex wrench through the access holes on either side, tighten each while alternating: first just snug each, then tighten firmly. |
| Ready for PCB | At this point you should have all the wires hanging out the back of the body. |
| Install the mount rail on the PCCB | Attach the mounting rail to the PCB with M3x6 screws. Clip any long leads that stick through the PCB under or near the mounting rail.<br/><br/>*Copy MP3 files to the SD card, as it will require disconnecting the PCB to get to it later.* |
| Flip onto it's back | Flip the crow over onto its back. Set it on a t-shirt or soft cloth to prevent scratches. |
| Attach servo, speaker, and LED connections | Connect the LED, speaker, and servo leads. Pay attention to polarity (servo brown is GND). |
| Attach stepper and sensor | Slide the board partway into the body and connect the stepper and sensor. |
| Slide PCB into place until it clicks | Slide the board the rest of the way in until it stops and the rail clicks into place. |
| Attach the tail | Flip over the crow. Route any external connections through the hole in the tail and attach it to the back of the crow. |
| Secure the tail tab with a M3 screw | You can secure the tail to the body with a M3x8 screw through the hole located between the wings just in front of the tail. |
| Crow assembled | In lieu of a cable, you can carefully set a battery into the body of the crow (taking care not to damage or short any components) for a self-contained model. |

___
## Software ##

1.  Copy the [mp3](mp3) folder to your SD card and insert it into the DFPlayer-Mini.
2. Install the [Arduino IDE](https://www.arduino.cc/en/software/) and the following libraries: [AccelStepper](https://www.airspayce.com/mikem/arduino/AccelStepper), [DFRobotDFPlayerMini](https://github.com/DFRobot/DFRobotDFPlayerMini), [Adafruit NeoPixel](https://github.com/adafruit/Adafruit_NeoPixel).
    * For RP2040-Zero: Install the [arduino-pico](https://github.com/earlephilhower/arduino-pico) by Earle Philhower library.
    * For ESP32-S3-Zero: Install the [esp32 by espressif systems](https://github.com/espressif/arduino-esp32) **board manager** 
and the [ESP32Servo](https://madhephaestus.github.io/ESP32Servo/annotated.html) by Kevin Harrington library. 
    * All of these should be installable from the library manager or board manager once in the Arduino IDE.
3. Enable the *Waveshare RP2040-Zero* or the *Waveshare ESP32-S3-Zero* MCU the board in the board manager.
4. Connect your CC5x12 to power and the MCU USB to your PC, select the connected device, and assign the appropriate board. 
5. Open the desired sketch, make changes to `settings.h` if needed, and select 'Upload.'

### Sketches ###
Use the appropriate subdirectory in the [ino](ino) folder for your MCU.

### <u>*calibrate-crow*</u> ###
Use this sketch to determine settings or test aspects of your crow.
At a minimum, you will need to use this sketch to determine the correct `SERVO_PWM_OPEN` and `SERVO_PWM_CLOSED` settings for your beak.
Enable the Serial Monitor in Arduino. Enter values (without `<>`) to adjust settings or test as follows:
* `?` Help: displays available commands
* `b <val>` Beak: set position to PWM value (usually around 1000 fully-open and 1400 fully-closed, but these can vary a lot)
* `s <open> <closed>` Set: once you know the fully open and closed values, set them this way
* `a <num> <delay` Animate: play animation number (1-14) with an (optional) delay in order to test both PWM settings and delay
* `v <0-30>` Volume: set volume to the specified value
* `f <float>` Factor: set an easing factor for animations from 1.0 (very smooth) to 4.0 (very snappy)
* `e <0/1>` Eyes: 0 for ON and 1 for MIRROR SENSOR (eyes will illuminate when the sensor detects motion)
* `NECK Stepper`
    * `n -1` Run automatic centering
    * `n 0` Stop movement and return to center
    * `n <accel> <max>` Test acceleration (and optional max speed) sweeping neck from side to side looking for skips
* `p` Print: modified PWM, Volume, Delay, and Smoothing Factor settings (save and change in animatronic-crow/settings.h)

### <u>*animatronic-crow*</u> ### 
The runtime software for your bird. 
You'll need to change the PWM OPEN and CLOSED for your particular crow in the settings.h file.
When connected to a PC, debug messages are sent to the Arduino Serial Monitor.
  * __SERVO_PWM_OPEN__ and __SERVO_PWM_CLOSED__ *are required* if you want the beak motion to match your crow.
  * __TEST_MODE__ when set to true will illuminate the eyes whenever the sensor senses movement.
  * __SENSOR_MODE__ set to one of the following values:
    * __SENSOR_MODE_PIR__ will scold when it detects IR motion.
    * __SENSOR_MODE_LD1020__ will scold when it detects any nearby motion but should block the sensor from detecting the crow's own movements.
    * __SENSOR_MODE_BUTTON__ enables a "Try Me" push-button feature. The crow will wake up, scold, turn its head, squawk, and go back to sleep whenever the button is pressed. Button presses while the sequence is running will have no effect.
    * __SENSOR_MODE_NONE__ with no sensor, or when you prefer the full set of random scold and squawk animations (will ignore any sensor).
  * __DFPLAYER_VOLUME__ hypothetical max 30, but actual max depends on power supply, speaker, etc. It's best to test with calibrate-crow (5v on battery power, if that's how you intend to deploy it) and if sound drops out, lower until it doesn't.
  * __LD1020_ANIMATION_COOLDOWN_MS__ is your main "how reactive do I want this crow to be?" setting when using radar.
  * __SCOLD_SQUAWK_BLOCK_MS__ is your main "how reactive do I want this crow to be?" setting when using PIR.
  * __IDLE*__ settings control how active a non-reacting crow will be.
  * __BLINK*__ controls frequency of blinking.
  * __NECK*__ don't change the range, but adjust the fast speed if needed after testing your stepper.
  * __PIN__ definitions change if you aren't using the CC5x12 sensor1, servo1, stepper1, or LED1.

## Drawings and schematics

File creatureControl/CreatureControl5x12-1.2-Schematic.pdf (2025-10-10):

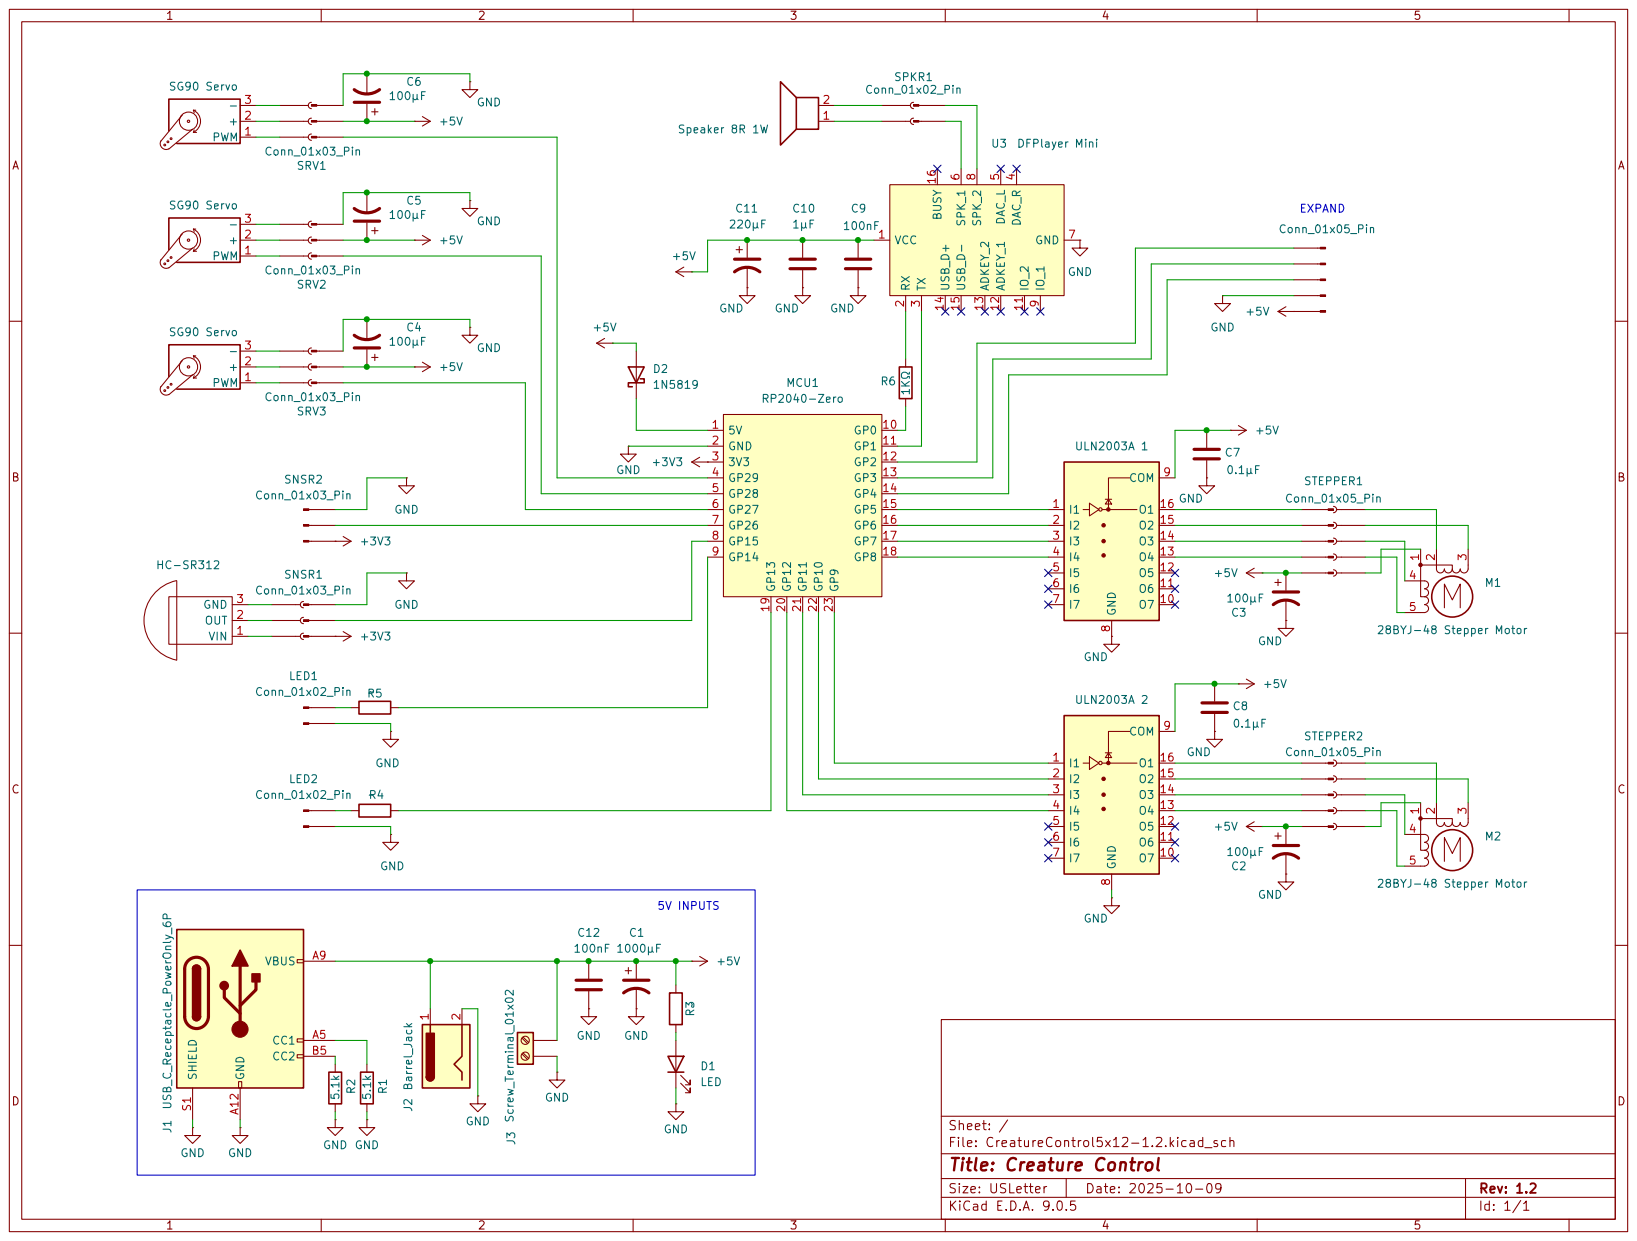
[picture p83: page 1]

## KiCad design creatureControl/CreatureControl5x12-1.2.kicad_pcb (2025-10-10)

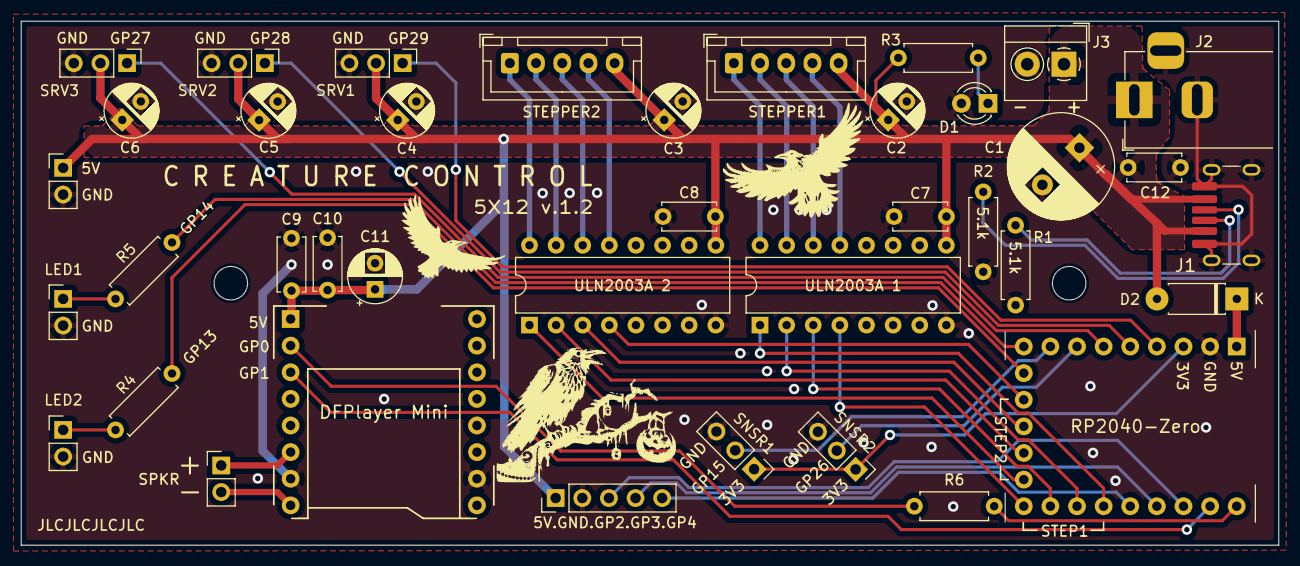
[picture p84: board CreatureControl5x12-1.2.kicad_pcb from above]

Board: 2 copper layers, 120.0 x 50.0 mm, 38 parts (0 on the bottom side), 37 nets.

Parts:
5V: PinHeader_1x02_P2.54mm_Vertical
 R5: 2.2 kΩ; R_Axial_DIN0207_L6.3mm_D2.5mm_P7.62mm_Horizontal
C1: CP_Radial_D10.0mm_P5.00mm
C2, C3, C4, C5, C6, C11: CP_Radial_D5.0mm_P2.50mm
C7, C8: 10nf; C_Disc_D5.0mm_W2.5mm_P5.00mm
C9, C10, C12: C_Disc_D5.0mm_W2.5mm_P5.00mm
D1: LED_D3.0mm
D2: D_DO-41_SOD81_P7.62mm_Horizontal
DFPlayer Mini: DFPlayer Mini
J1: USB_C_Receptacle_GCT_USB4125-xx-x-0190_6P_TopMnt_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; USB_C_Receptacle_GCT_USB4125-xx-x-0190_6P_TopMnt_Horizontal
J2: BarrelJack_Horizontal
J3: TerminalBlock_4Ucon_1x02_P3.50mm_Horizontal
LED1, LED2: PinHeader_1x02_P2.54mm_Vertical
R1, R2, R6: 5.1 kΩ; R_Axial_DIN0207_L6.3mm_D2.5mm_P7.62mm_Horizontal
R3, R4: 2.2 kΩ; R_Axial_DIN0207_L6.3mm_D2.5mm_P7.62mm_Horizontal
RP2040-Zero: RP2040 Zero
SNSR1, SNSR2: PinHeader_1x03_P2.54mm_Vertical
SPKR: PinHeader_1x02_P2.54mm_Vertical
SRV1, SRV2, SRV3: PinHeader_1x03_P2.54mm_Vertical
STEPPER1, STEPPER2: JST_XH_B5B-XH-A_1x05_P2.50mm_Vertical
ULN2003A 1, ULN2003A 2: DIP-16_W7.62mm

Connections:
3V3: RP2040-Zero.3, SNSR1.1, SNSR2.1
5V: 5V.1, C1.1, C2.1, C3.1, C4.1, C5.1, C6.1, C7.1, C8.1, C9.1, C10.1, C11.1, C12.1, D2.2, DFPlayer Mini.1, J1.A9, J1.B9, J2.1, J3.1, R3.1, SRV1.2, SRV2.2, SRV3.2, STEPPER1.5, STEPPER2.5, ULN2003A 1.9, ULN2003A 2.9
A5: J1.A5, R1.2
B5: J1.B5, R2.2
D1: D1.1, R3.2
DFRX: DFPlayer Mini.2, R6.2
GND: 5V.2, C1.2, C2.2, C3.2, C4.2, C5.2, C6.2, C7.2, C8.2, C9.2, C10.2, C11.2, C12.2, D1.2, DFPlayer Mini.7, DFPlayer Mini.15, J1.A12, J1.B12, J1.S1, J2.2, J2.3, J3.2, LED1.2, LED2.2, R1.1, R2.1, RP2040-Zero.2, SNSR1.3, SNSR2.3, SRV1.3, SRV2.3, SRV3.3, ULN2003A 1.8, ULN2003A 2.8
GP0: R6.1, RP2040-Zero.10
GP1: DFPlayer Mini.3, RP2040-Zero.11
GP5: RP2040-Zero.15, ULN2003A 1.1
GP6: RP2040-Zero.16, ULN2003A 1.2
GP7: RP2040-Zero.17, ULN2003A 1.3
GP8: RP2040-Zero.18, ULN2003A 1.4
GP9: RP2040-Zero.23, ULN2003A 2.1
GP10: RP2040-Zero.22, ULN2003A 2.2
GP11: RP2040-Zero.21, ULN2003A 2.3
GP12: RP2040-Zero.20, ULN2003A 2.4
GP13: R4.2, RP2040-Zero.19
GP14: R5.2, RP2040-Zero.9
GP15: RP2040-Zero.8, SNSR1.2
GP26: RP2040-Zero.7, SNSR2.2
GP27: RP2040-Zero.6, SRV3.1
GP28: RP2040-Zero.5, SRV2.1
GP29: RP2040-Zero.4, SRV1.1
LED1: R5.1, LED1.1
LED2: LED2.1, R4.1
RP-5V: D2.1, RP2040-Zero.1
S1-1: STEPPER1.1, ULN2003A 1.16
S1-2: STEPPER1.2, ULN2003A 1.15
S1-3: STEPPER1.3, ULN2003A 1.14
S1-4: STEPPER1.4, ULN2003A 1.13
S2-1: STEPPER2.1, ULN2003A 2.16
S2-2: STEPPER2.2, ULN2003A 2.15
S2-3: STEPPER2.3, ULN2003A 2.14
S2-4: STEPPER2.4, ULN2003A 2.13
SPKR+: DFPlayer Mini.6, SPKR.1
SPKR-: DFPlayer Mini.8, SPKR.2

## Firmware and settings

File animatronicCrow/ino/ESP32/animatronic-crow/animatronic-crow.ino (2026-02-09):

/*
 * Animatronic Crow Controller
 * ---------------------------
 *
 * Features:
 * - Dual-core: Core1 monitors motion sensor, Core0 runs animations
 * - Scolding, idle movements, random squawks
 * - Synchronized beak animations with audio files
 * - Non-blocking control
 * - Random eye blinking
 * - Test mode for sensor debugging
 * - LD1020 mode enables animation cooldown to prevent self-triggering
 * - BUTTON mode for "Try Me" functionality
 * 
 * >> "User Configuration" is located in settings.h <<
 * 
 */
#include <Arduino.h>
#include <ESP32Servo.h>
#include <DFRobotDFPlayerMini.h>
#include <AccelStepper.h>

// SENSOR MODE CODES - Do not modify these values
#define SENSOR_MODE_PIR 0
#define SENSOR_MODE_LD1020 1
#define SENSOR_MODE_NONE 2
#define SENSOR_MODE_BUTTON 3  // connect button to PIN_MOTION_SENSOR/GND

#include "settings.h"
#include "animations.h"
#include "crow-utils.h"

// ============================================================================
// GLOBAL OBJECTS 
// ============================================================================
AccelStepper stepper(AccelStepper::HALF4WIRE, PIN_STEPPER_1, PIN_STEPPER_3, PIN_STEPPER_2, PIN_STEPPER_4);
Servo beakServo;
DFRobotDFPlayerMini dfPlayer;

#if SHOW_NEOPIXEL_STATUS
#include <Adafruit_NeoPixel.h>
Adafruit_NeoPixel statusLED(1, PIN_NEOPIXEL, NEO_GRB + NEO_KHZ800);
#endif

// Neck position definitions
const int NECK_CENTER = 0;
const int NECK_SIDE = NECK_RANGE / 2;

// ============================================================================
// STATE TRACKING
// ============================================================================
enum CrowMode {
  MODE_IDLE,
  MODE_IDLE_MOVE,
  MODE_SCOLDING,
  MODE_SQUAWKING,
  MODE_RESETTING
};

volatile bool sensorCurrentlyHigh = false;
volatile bool buttonDefaultState = HIGH;
volatile bool buttonTriggered = false;
bool buttonSequenceActive = false;
unsigned long buttonWaitMs = 0;
unsigned long lastButtonStepTime = 0;
uint8_t buttonStep = 0;

CrowMode currentMode = MODE_IDLE;
unsigned long lastIdleMoveTime = 0;
unsigned long nextIdleMoveTime = 0;
unsigned long lastIdleSquawkTime = 0;
unsigned long nextIdleSquawkTime = 0;
unsigned long lastBlinkTime = 0;
unsigned long nextBlinkTime = 0;
unsigned long lastAudioTime = 0;
unsigned long movementStart = 0;
unsigned long movementEnd = 0;

// ============================================================================
// SETUP - CORE 0
// ============================================================================
void setup() {
  Serial.begin(115200);
  delay(7500);

  Serial.println(F("\n========================================"));
  Serial.println(F("Crow Animation Controller"));
  if (TEST_MODE) {
    Serial.println(F("*** TEST MODE ACTIVE ***"));
    Serial.println(F("Eyes mirror sensor: ON=HIGH, OFF=LOW"));
  }
  if (SENSOR_MODE == SENSOR_MODE_LD1020) {
    Serial.println(F("*** LD1020 RADAR MODE ***"));
    Serial.print(F("Animation cooldown: "));
    Serial.print(LD1020_ANIMATION_COOLDOWN_MS);
    Serial.println(F("ms"));
  } else if (SENSOR_MODE == SENSOR_MODE_PIR) {
    Serial.println(F("*** PIR SENSOR MODE ***"));
  } else if (SENSOR_MODE == SENSOR_MODE_BUTTON) {
    Serial.println(F("*** BUTTON MODE ***"));
  } else {
    Serial.println(F("*** NO SENSOR CONFIGURED ***"));
  }
  Serial.println(F("========================================\n"));

  randomSeed(analogRead(A0));
  
  initializeNeopixel();
  showPixel(0, 50, 0); // NeoPixel: green

  initializeEyes();
  initializeBeak();
  initializeNeck();
  initializeDFPlayer();
  initializeMotionSensor();

  resetIdleTimers();

  showPixel(0, 0, 0); // NeoPixel: off
  Serial.println(F("✓ Initialization complete. Crow is alive!"));
}

// ============================================================================
// MAIN LOOP - CORE 0
// ============================================================================
void loop() {
  unsigned long now = millis();
  stepper.run();
  updateBeak();
  updateSensorState(now);

  // BUTTON MODE: Handle button sequence
  if (SENSOR_MODE == SENSOR_MODE_BUTTON) {
    // Handle blinking in test mode or during sequence
    if (TEST_MODE) {
      digitalWrite(PIN_LED_EYES, buttonTriggered ? HIGH : LOW);
    } else if (buttonSequenceActive) {
      handleBlinking(now);
    }

    // Check for button trigger
    if (buttonTriggered && !buttonSequenceActive) {
      lastButtonStepTime = millis();
      buttonStep = 0;
    }
    executeButtonSequence(now);
    return;  // Skip all other mode logic
  }

  // Handle eye behavior based on mode
  if (TEST_MODE) {  // Test mode: eyes mirror sensor state
    digitalWrite(PIN_LED_EYES, sensorCurrentlyHigh ? HIGH : LOW);
  } else {  // Normal mode: random blinking
    handleBlinking(now);
  }

  // LD1020 Mode: Check if cooldown period has elapsed
  bool ld1020Clear = true;
  if (SENSOR_MODE == SENSOR_MODE_LD1020) {
    long moveTime = max(movementEnd, movementStart);
    ld1020Clear = (now - moveTime >= LD1020_ANIMATION_COOLDOWN_MS);
    if (!ld1020Clear) return;  // Skip other behaviors during cooldown
  }

  // Prevent rapidly-repeating squawks and scolds
  bool squawkEnabled = (now - lastAudioTime >= SCOLD_SQUAWK_BLOCK_MS);

  // Scold when triggered and available
  if (currentMode != MODE_SCOLDING && sensorCurrentlyHigh && !animating && squawkEnabled && ld1020Clear) {
    Serial.println(F("[Scold]  Motion detected! Scolding..."));
    // Interrupt idle neck movement if in progress
    if (currentMode == MODE_IDLE && stepper.distanceToGo() != 0) {
      Serial.println(F("[Break]  Stopping idle movement for scold"));
      stepper.stop();
    }
    startScoldSequence();
    return;  // Skip other behaviors this loop
  }

  // Handle current mode
  switch (currentMode) {
    case MODE_IDLE:
      handleIdleMode(now, squawkEnabled, ld1020Clear);
      break;

    case MODE_IDLE_MOVE:
      if (stepper.distanceToGo() == 0) {
        currentMode = MODE_IDLE;
        movementEnd = millis();
      }
      break;

    case MODE_SCOLDING:
      // Wait for animation to complete
      if (!animating && stepper.distanceToGo() == 0) {
        if (SENSOR_MODE == SENSOR_MODE_LD1020) {
          Serial.print(F("[LD1020] Scold complete, entering "));
          Serial.print(LD1020_ANIMATION_COOLDOWN_MS);
          Serial.println(F("ms cooldown"));
        } else {
          Serial.println(F("[Scold]  Complete. Returning to idle"));
        }
        currentMode = MODE_IDLE;
        resetIdleMoveTime();
        addBlockToSquawkTime();
        lastAudioTime = millis();
        movementEnd = millis();
      }
      break;

    case MODE_SQUAWKING:
      // Wait for animation to complete
      if (!animating && stepper.distanceToGo() == 0) {
        currentMode = MODE_IDLE;
        Serial.println(F("[Squawk] Complete. Returning to idle"));
        lastAudioTime = millis();
        movementEnd = millis();
      }
      break;

    case MODE_RESETTING:
      // Wait for neck to center
      if (stepper.distanceToGo() == 0) {
        currentMode = MODE_IDLE;
      }
      break;
  }
}

// ============================================================================
// INITIALIZATION FUNCTIONS
// ============================================================================

void initializeEyes() {
  pinMode(PIN_LED_EYES, OUTPUT);
  digitalWrite(PIN_LED_EYES, HIGH);
  Serial.println(F("[Init]   Eyes online"));
  delay(500);

  if (!TEST_MODE) {
    digitalWrite(PIN_LED_EYES, LOW);
    delay(500);
  }
}

void initializeBeak() {
  showPixel(25, 25, 25); // NeoPixel: white
  int mid = (SERVO_PWM_OPEN + SERVO_PWM_CLOSED) / 2;
  beakServo.writeMicroseconds(mid);  // start center
  beakServo.attach(PIN_SERVO, SERVO_PWM_OPEN, SERVO_PWM_CLOSED);
  beakServo.setTimerWidth(16);
  delay(200);
  for (int p = mid; p > SERVO_PWM_OPEN; p--) {  // move open
    beakServo.writeMicroseconds(p);
    delay(2);
  }
  for (int p = SERVO_PWM_OPEN; p < SERVO_PWM_CLOSED; p++) {  // move closed
    beakServo.writeMicroseconds(p);
    delay(2);
  }
  beakServo.writeMicroseconds(SERVO_PWM_CLOSED);
  delay(200);
  Serial.println(F("[Init]   Beak servo online"));
  delay(500);
}

void initializeNeck() {
  showPixel(0, 50, 25); // NeoPixel: teal
  setNeckSpeedSlow();

  // Center the neck through a calibration sequence
  Serial.println(F("[Init]   Centering neck..."));
  stepper.setCurrentPosition(0);
  stepper.moveTo(NECK_RANGE + 100);
  while (stepper.distanceToGo() != 0) {
    stepper.run();
  }
  stepper.setCurrentPosition(0);
  stepper.moveTo(-(NECK_RANGE / 2 + 50));
  while (stepper.distanceToGo() != 0) {
    stepper.run();
  }
  stepper.setCurrentPosition(0);
  Serial.println(F("[Init]   Neck centered and online"));

  setNeckSpeedFast();
  delay(500);
}

void initializeDFPlayer() {
  showPixel(50, 25, 0); // NeoPixel: orange
  Serial1.begin(9600, SERIAL_8N1, PIN_DFPLAYER_RX, PIN_DFPLAYER_TX);
  delay(1000);

  if (!dfPlayer.begin(Serial1, true, true)) {
    Serial.println(F("[Init]   ✗ DFPlayer Mini failed!"));
    showPixel(50, 0, 0); // NeoPixel: red
    delay(2000);
  } else {
    Serial.println(F("[Init]   DFPlayer Mini online"));
    showPixel(50, 0, 50); // NeoPixel: purple

    delay(2000);
    dfPlayer.volume(DFPLAYER_VOLUME);
    delay(200);
    dfPlayer.play(11);
  }
  delay(2500);
}

void initializeMotionSensor() {
  if (SENSOR_MODE == SENSOR_MODE_BUTTON) {
    // Button mode: Use INPUT_PULLUP and detect default state
    pinMode(PIN_MOTION_SENSOR, INPUT_PULLUP);
    delay(100);  // Let pin stabilize

    buttonDefaultState = digitalRead(PIN_MOTION_SENSOR);
    showPixel(0, 0, 50); // NeoPixel: blue
    
    Serial.println(F("[Init]   Button sensor online (INPUT_PULLUP)"));
    Serial.print(F("[Init]   Button default state: "));
    Serial.println(buttonDefaultState == HIGH ? "HIGH (NO)" : "LOW (NC)");
    Serial.println(F("[Init]   Waiting for button press test..."));

    unsigned long startTime = millis();
    bool detected = false;

    while (millis() - startTime < 5000) {
      if (digitalRead(PIN_MOTION_SENSOR) != buttonDefaultState) {
        Serial.println(F("[Init]   ✓ Button press detected!"));
        detected = true;
        // Wait for release
        while (digitalRead(PIN_MOTION_SENSOR) != buttonDefaultState) {
          delay(50);
        }
        break;
      }
      delay(100);
    }

    if (!detected) {
      Serial.println(F("[Init]   No button press detected (this is OK)"));
    }

  } else if (SENSOR_MODE != SENSOR_MODE_NONE) {
    // PIR or LD1020 mode: Standard INPUT
    pinMode(PIN_MOTION_SENSOR, INPUT);
    showPixel(0, 0, 50); // blue
    Serial.println(F("[Init]   Motion sensor online"));
    Serial.println(F("[Init]   Waiting for motion test..."));

    unsigned long startTime = millis();
    bool detected = false;

    while (millis() - startTime < 5000) {
      if (digitalRead(PIN_MOTION_SENSOR) == HIGH) {
        Serial.println(F("[Init]   ✓ Motion detected!"));
        detected = true;
        break;
      }
      delay(100);
    }

    if (!detected) {
      Serial.println(F("[Init]   No motion detected (this is OK)"));
    }
  }

  delay(500);
}

void initializeNeopixel() {
  // Initialize status LED (conditional)
#if SHOW_NEOPIXEL_STATUS
  pinMode(PIN_NEOPIXEL_POWER, OUTPUT);
  digitalWrite(PIN_NEOPIXEL_POWER, HIGH);
  statusLED.begin();
  statusLED.setBrightness(50);
#endif
}

// ============================================================================
// MODE HANDLERS
// ============================================================================

void executeButtonSequence(unsigned long now) {
  if (buttonTriggered) {
    if (!buttonSequenceActive) {
      buttonSequenceActive = true;
      Serial.println(F("[Button] ===== STARTING BUTTON SEQUENCE ====="));
    }

    // Check if we need to wait before advancing
    if (now - lastButtonStepTime < buttonWaitMs) return;

    switch (buttonStep) {
      case 0:
        Serial.println(F("[Button] Eyes ON"));
        digitalWrite(PIN_LED_EYES, HIGH);
        nextBlinkTime = now + random(BLINK_MIN_INTERVAL_MS, BLINK_MAX_INTERVAL_MS);
        buttonWaitMs = 800;
        lastButtonStepTime = now;
        buttonStep++;
        break;
      case 1:
        Serial.println(F("[Button] Scolding"));
        startScoldSequence();
        buttonStep++;
        break;
      case 2:
        if (!animating && stepper.distanceToGo() == 0) {
          buttonWaitMs = random(1000, 3000);
          lastButtonStepTime = now;
          buttonStep++;
        }
        break;
      case 3:
        Serial.println(F("[Button] Movement"));
        startIdleMove(now);
        buttonStep++;
        break;
      case 4:
        if (stepper.distanceToGo() == 0) {
          buttonWaitMs = random(1200, 2400);
          lastButtonStepTime = now;
          buttonStep++;
        }
        break;
      case 5:
        Serial.println(F("[Button] Squawk"));
        animateAudio(random(8, 15));
        buttonStep++;
        break;
      case 6:
        if (!animating && stepper.distanceToGo() == 0) {
          buttonWaitMs = random(1000, 3000);
          lastButtonStepTime = now;
          buttonStep++;
        }
        break;
      case 7:
        Serial.println(F("[Button] Centering Neck"));
        setNeckSpeedSlow();
        stepper.moveTo(NECK_CENTER);
        buttonStep++;
      case 8:
        if (stepper.distanceToGo() == 0) {
          Serial.println(F("[Button] Eyes OFF"));
          digitalWrite(PIN_LED_EYES, LOW);
          Serial.println(F("[Button] ===== SEQUENCE COMPLETE ====="));
          buttonSequenceActive = false;
          buttonTriggered = false;
        }
        break;
    }
  }
}

void handleIdleMode(unsigned long now, bool squawkEnabled, bool ld1020Clear) {

  // Random neck movements
  if (ld1020Clear && now >= nextIdleMoveTime && stepper.distanceToGo() == 0 && !animating) {

    // Randomly scold if there is no sensor
    if (SENSOR_MODE == SENSOR_MODE_NONE) {
      if (squawkEnabled && random(0, 4) == 0) {
        Serial.println(F("[Scold]  Idle scold! Scolding..."));
        startScoldSequence();
        resetIdleMoveTime();
        return;
      }
    }
    // Trigger idle movement and (re)set volume
    dfPlayer.volume(DFPLAYER_VOLUME);
    startIdleMove(now);
  }

  // Random idle squawks
  if (ld1020Clear && squawkEnabled && now >= nextIdleSquawkTime && !animating) {
    startIdleSquawk();
    resetIdleSquawkTime();
  }
}

void startScoldSequence() {
  currentMode = MODE_SCOLDING;
  movementStart = millis();
  lastAudioTime = millis();

  // Move neck to +/- 20% position
  setNeckSpeedFast();
  int rangePercent = random(0, NECK_RANGE_SCOLD_PERCENT + 1);
  int direction = random(0, 2) == 0 ? 1 : -1;
  int scoldPos = (NECK_SIDE * rangePercent / 100) * direction;
  stepper.moveTo(scoldPos);

  Serial.print(F("[Scold]  Turning head to "));
  Serial.println(scoldPos);
  // Choose random scold sound (tracks 1-7)
  animateAudio(random(1, 8));
}

void startIdleSquawk() {
  Serial.println(F("[Squawk] Random squawk..."));
  currentMode = MODE_SQUAWKING;
  movementStart = millis();
  lastAudioTime = millis();
  // Choose random squawk sound (tracks 8-14)
  animateAudio(random(8, 15));
}

void startIdleMove(unsigned long now) {
  // Randomly choose slow or fast movement
  if (random(0, 2) == 0) setNeckSpeedFast();
  else setNeckSpeedSlow();

  // Generate random position: 30-100% of range in either direction
  int rangePercent = random(IDLE_NECK_MIN_PERCENT, IDLE_NECK_MAX_PERCENT + 1);
  int direction = random(0, 2) == 0 ? 1 : -1;  // Left or right
  int targetPos = (NECK_SIDE * rangePercent / 100) * direction;

  stepper.moveTo(targetPos);

  Serial.print(F("[Idle]   Moving neck to "));
  Serial.print(targetPos);
  Serial.print(F(" ("));
  Serial.print(rangePercent);
  Serial.println(F("% range)"));
  currentMode = MODE_IDLE_MOVE;
  movementStart = now;

  resetIdleMoveTime();
}

void resetIdleTimers() {
  resetIdleMoveTime();
  resetIdleSquawkTime();
}

void resetIdleMoveTime() {
  nextIdleMoveTime = millis() + random(IDLE_MOVE_MIN_MS, IDLE_MOVE_MAX_MS);
}

void resetIdleSquawkTime() {
  nextIdleSquawkTime = millis() + random(IDLE_SQUAWK_MIN_MS, IDLE_SQUAWK_MAX_MS);
}

void addBlockToSquawkTime() {
  nextIdleSquawkTime = millis() + SCOLD_SQUAWK_BLOCK_MS;
}

// ============================================================================
// SENSOR MONITOR
// ============================================================================
void updateSensorState(unsigned long now) {
  if (SENSOR_MODE == SENSOR_MODE_NONE)  return;

  static unsigned long lastSensorRead = 0;
  const unsigned long SENSOR_INTERVAL = 50; 

  if (now - lastSensorRead > SENSOR_INTERVAL) {
    if (SENSOR_MODE == SENSOR_MODE_BUTTON) {
      // Button mode: Detect state changes (debounced)
      static bool lastState = buttonDefaultState;
      static unsigned long lastChangeTime = 0;

      bool currentState = digitalRead(PIN_MOTION_SENSOR);
      // Detect change from default state (button pressed)
      if (currentState != buttonDefaultState && currentState != lastState) {
        if (millis() - lastChangeTime > SENSOR_INTERVAL) {
          if (!buttonSequenceActive) buttonTriggered = true;
          lastChangeTime = millis();
        }
      }
      lastState = currentState;

    } else {
      // PIR or LD1020 mode: Monitor for HIGH state
      sensorCurrentlyHigh = digitalRead(PIN_MOTION_SENSOR);
      lastSensorRead = now;
    }
  }
}

// ============================================================================
// NECK CONTROL
// ============================================================================

void setNeckSpeedSlow() {
  stepper.setMaxSpeed(NECK_SPEED_SLOW_MAX);
  stepper.setAcceleration(NECK_SPEED_SLOW_ACCEL);
}

void setNeckSpeedFast() {
  stepper.setMaxSpeed(NECK_SPEED_FAST_MAX);
  stepper.setAcceleration(NECK_SPEED_FAST_ACCEL);
}

void resetNeckToCenter() {
  stepper.stop();
  setNeckSpeedFast();
  stepper.moveTo(NECK_CENTER);

  // Wait for completion
  while (stepper.distanceToGo() != 0) {
    stepper.run();
  }
}

// ============================================================================
// AUDIO CONTROL
// ============================================================================

void animateAudio(uint8_t trackNum) {
  uint8_t idx = trackNum - 1;

  if (idx < NUM_ANIMATIONS) {
    Serial.print(F("► Audio  Playing track "));
    Serial.print(trackNum);
    Serial.print(F(" at time "));
    Serial.println(millis() / 1000);

    dfPlayer.play(trackNum);

    // queue animation with delay to get DFPlayer started
    queuePendingAnimation(idx, millis() + AUDIO_SYNC_DELAY_MS);
  } else {
    Serial.println(F("✗ Audio  Track index out of bounds!"));
  }
}

// ============================================================================
// EYE BLINKING
// ============================================================================

void handleBlinking(unsigned long now) {
  static bool eyesOpen = true;
  static unsigned long blinkStartTime = 0;

  if (eyesOpen) {
    // Check if it's time to blink
    if (now >= nextBlinkTime) {
      digitalWrite(PIN_LED_EYES, LOW);
      eyesOpen = false;
      blinkStartTime = now;
    }
  } else {
    // Check if blink is complete
    if (now - blinkStartTime >= BLINK_DURATION_MS) {
      digitalWrite(PIN_LED_EYES, HIGH);
      eyesOpen = true;
      nextBlinkTime = now + random(BLINK_MIN_INTERVAL_MS, BLINK_MAX_INTERVAL_MS);
    }
  }
}

// ============================================================================
// NeoPixel (on-board LED) status
// ============================================================================
void showPixel(int r, int g, int b) {
#if SHOW_NEOPIXEL_STATUS
  statusLED.setPixelColor(0, statusLED.Color(r, g, b));
  statusLED.show();
#endif
}

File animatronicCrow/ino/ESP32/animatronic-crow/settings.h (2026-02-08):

#ifndef SETTINGS_H
#define SETTINGS_H
// ****************************************************************************
// Animatronic Crow User Configuration
// ****************************************************************************

// ============================================================================
// PIN DEFINITIONS - (defaults for CC5x12 v1.2 stepper1, servo1, led1, sensor1)
// ============================================================================
#define PIN_DFPLAYER_TX               TX
#define PIN_DFPLAYER_RX               RX
#define PIN_SERVO                     13    // SRV1 (2 on CC5x12 <= v1.1)
#define PIN_STEPPER_1                 10    // STEPPER1
#define PIN_STEPPER_2                 9
#define PIN_STEPPER_3                 8
#define PIN_STEPPER_4                 7
#define PIN_LED_EYES                  6    // LED1
#define PIN_MOTION_SENSOR             5    // SNSR1
#define PIN_NEOPIXEL                  21
#define PIN_NEOPIXEL_POWER            35

// TEST MODE - Set to true to mirror sensor state with eyes (for debugging)
#define TEST_MODE                     false // true: eyes mirror sensor, false: normal blinking
#define SHOW_NEOPIXEL_STATUS          true // true: display status color on RP2040-Zero RGB LED

// SENSOR MODE - Choose one mode: SENSOR_MODE_PIR, SENSOR_MODE_LD1020, SENSOR_MODE_BUTTON, SENSOR_MODE_NONE
#define SENSOR_MODE                   SENSOR_MODE_PIR

// Servo Settings
#define SERVO_PWM_OPEN                1050  // fully open PWM
#define SERVO_PWM_CLOSED              1250  // fully closed PWM
#define SERVO_EASING_FACTOR           3.00  // determines animation smooting (smaller is smoother)

// Audio Settings
#define DFPLAYER_VOLUME               25  	// Volume 0-30
#define AUDIO_SYNC_DELAY_MS	          100   // sync delay

// Motion Detection Settings
#define LD1020_ANIMATION_COOLDOWN_MS  8500  // Wait after any animation before checking sensor (LD1020 mode only)
#define SCOLD_SQUAWK_BLOCK_MS         7000  // Delay squawks after scolds and vice-versa

// Idle Behavior Settings
// NOTE: For LD1020 mode, ensure these are > LD1020_ANIMATION_COOLDOWN_MS to prevent self-triggering from animations
// NOTE: For BUTTON mode, most of these timers are ignored
#define IDLE_MOVE_MIN_MS              9000  // Min time between idle movements (must be > LD1020_ANIMATION_COOLDOWN_MS for LD1020)
#define IDLE_MOVE_MAX_MS              18000 // Max time between idle movements
#define IDLE_SQUAWK_MIN_MS            15000 // Min time between random squawks (or scolds without sensor)
#define IDLE_SQUAWK_MAX_MS            45000 // Max time between random squawks (or scolds without sensor)
#define IDLE_NECK_MIN_PERCENT         30    // Min percent of range for idle moves
#define IDLE_NECK_MAX_PERCENT         100   // Max percent of range for idle moves

// Eye Blink Settings
#define BLINK_DURATION_MS             90    // How long eyes stay closed
#define BLINK_MIN_INTERVAL_MS         3000  // Min time between blinks
#define BLINK_MAX_INTERVAL_MS         8000  // Max time between blinks

// Neck Movement Settings
#define NECK_RANGE                    1400  // Total range of motion
#define NECK_SPEED_SLOW_MAX           3250  // Slow movement max speed
#define NECK_SPEED_SLOW_ACCEL         500   // Slow movement acceleration
#define NECK_SPEED_FAST_MAX           6000  // Fast movement max speed
#define NECK_SPEED_FAST_ACCEL         4000  // Fast movement acceleration
#define NECK_RANGE_SCOLD_PERCENT        20  // Percent of range to move during scold (+/-)

#endif

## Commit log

2025-08-29 Initial repository with crow additions
    [4.1mmStepperConnector.stl, HeadStepperNeckConnectRemix01.stl, HeadStepperPlateRemix01.stl]
2025-09-09 Initial remix files and build guide
    [ActuatorSpacer.stl, Beak.stl, BodyStepperPlate.stl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]
2025-09-09 Adding Creature Control 5x12 PCB files
    [CreatureControl5x12-1.0.kicad_pcb, CreatureControl5x12-1.0.kicad_sch]
2025-09-09 Removing temporary files.
    [4.1mmStepperConnector.stl, HeadStepperNeckConnectRemix01.stl, HeadStepperPlateRemix01.stl]
2025-09-22 Update CC5x12 to v1.1
    [CreatureControl5x12-1.1.kicad_pcb, CreatureControl5x12-1.1.kicad_sch]
2025-09-22 Remove old schematic--rename new one
2025-09-22 Update stepper mount and head support interface
    [BodyStepperPlate.stl, HeadStepperCollar.stl]
2025-09-28 Body models and Head modifications
    [Beak.stl, BodyPCBMount.stl, BodyPIRCover.stl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]
2025-09-28 Adding PIR window cutout template
    [BodyPIRWindowTemplate.stl]
2025-09-28 Fix non-manifold body edges, add print instructions & images
2025-10-06 update beak, add actuator, update build
    [Actuator.stl, ActuatorSpacer.stl, Beak.stl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]
2025-10-08 Update sensor mounts and add PIR hole plug
    [BodyPIRMount.stl, BodyPIRPlug.stl, BodyRadarMount.stl]
2025-10-08 Extra PCBs in hand
2025-10-10 Update board files to version 1.2
    [CreatureControl5x12-1.2.kicad_pcb, CreatureControl5x12-1.2.kicad_sch]
2025-10-10 Upgrade bottoms silkscreen art
    [CreatureControl5x12-1.2.kicad_pcb]
2025-10-11 Add explicit PWM settings for SG90 servo
2025-10-12 Add optional NeoPixel, v1.1 bodge, scold rotate
    [BoardTest.ino, animatronic-crow.ino]
2025-10-13 Refine PIR behavior, prevent scolds from lining up too close to squawks
    [animatronic-crow.ino]
2025-10-13 Update BOM for v1.2
2025-10-15 Include no-sensor mode. Refine interactions.
2025-10-21 Update software config re: sensor mode options
2025-10-21 Better balance PCB mount position and enlarge insert melt holes
    [BodyPCBMount.stl]
2025-10-23 Adding board images
2025-12-18 Update default servo pin and some build instructions
2025-12-18 Update pin defaults for CC5x12 v1.2
2026-01-02 Add SENSOR_MODE_BUTTON for "Try Me" interaction
2026-01-02 Model updates to speaker, magnets, drainage, feet, inserts, PIR/fresnel
    [Beak.stl, BodyPIRCover.stl, BodyPIRMount.stl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]
2026-01-02 Remove magnet shims
    [MagnetShim-0.8mm.stl, MagnetShim-1.0mm.stl]
2026-01-03 Update guides to match latest files
    [BodyPIRWindowTemplate.stl]
2026-01-13 Add 8006 fresnel lens clarification
2026-01-22 Restoring feet without side hole (thanks padpumpkin)
    [FeetWithoutHole.stl]
2026-01-23 Clarify beak servo adjustment strategy
2026-01-25 Longer speaker ring screw needed
2026-02-02 Fix small issues, clarify, tidy up formatting
    [animations.h, calibrate-crow.ino, crow-utils.h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]
2026-02-04 Incorporate initial (static) ESP32-S3-Zero control software
2026-02-05 Safer PWM limits
2026-02-06 Fix missing last-but-one frame bug, lighten PROGMEM lookups when animation is unchanged
    [animations.h]
2026-02-08 Update YouTube video link with calibration instructions
2026-02-09 Adding short delay for DFPlayer start/index
    [animatronic-crow.ino]
